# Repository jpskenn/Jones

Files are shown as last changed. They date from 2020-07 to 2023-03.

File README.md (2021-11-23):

# Jones（ジョーンズ）とは

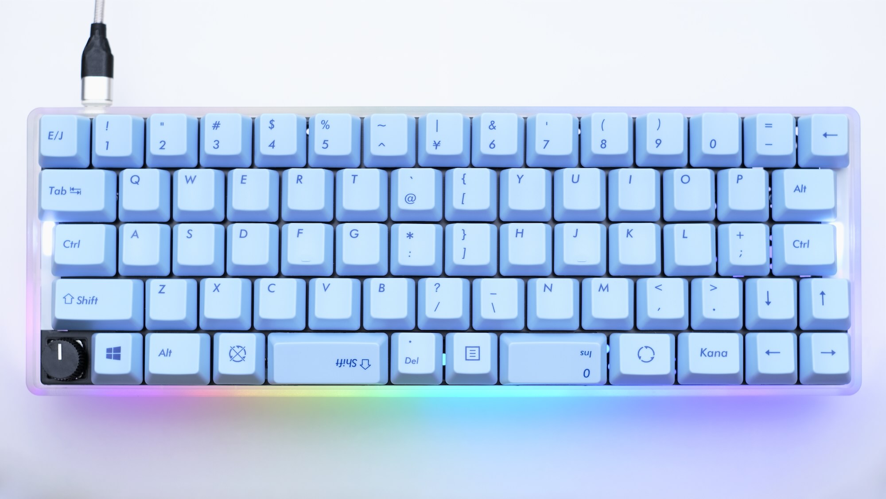
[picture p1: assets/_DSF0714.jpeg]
Jones


Jones（ジョーンズ）は、2行目と3行目にずれのない、シンメトリカルな60%キーボードです。  
左右対象のアルファ部と、右手側Modキーをホームポジションのすぐ隣へ配置したレイアウトが特徴で、自然なポジションで打鍵できます。  

40%や50%キーボードのコンパクトで軽快な運指の心地良さと、レイヤーに数字や記号を押し込まなくてよい十分なキー数を兼ね備えています。

GH60型やPoker型に互換性のあるケースや、専用のボトムプレートと組み合わせて使用できます。

[遊舎工房](https://shop.yushakobo.jp/products/2798)と[BOOTH](https://booth.pm/ja/items/3266269)で購入できます。  
また、その気になればご自分で製造することも可能です。

名前の由来は、ロースタガとオルソリニアをつなぐ”橋”という意味を込めて…

``` text
橋（ブリッジ） → ブリッジド → ブリジット → ブリジット・ジョーンズ → ジョーンズ

Bridge --> Bridged --> Bridget --> Bridget Jones --> Jones
```

という具合の言葉遊びで、ジョーンズ（Jones）に決まりました。

---

Jones is a symmetrical 60% keyboard, combined with Ortho-linear and Row-staggered. It has gap-less R2-R3 row.  
Symmetrical alpha-keys and nearby right side mod-keys provide natural typing position.  

It has compact and light fingering which like 40% and 50% keyboards.
And also, it has enough keys, no need to push numeric and symbol keys into layers.

It can be used with GH60 and Poker compatible cases.

Available at [Yushakobo](https://shop.yushakobo.jp/products/2798) and [BOOTH](https://booth.pm/ja/items/3266269).  
Or, manufacture by your self.

---

## 目次
<!-- @import "[TOC]" {cmd="toc" depthFrom=2 depthTo=4 orderedList=false} -->

<!-- code_chunk_output -->

- [目次](#目次)
- [対象とするユーザー](#対象とするユーザー)
- [コンセプト](#コンセプト)
- [特徴](#特徴)
  - [独自のずれ幅をもつ左右対象のアルファ部](#独自のずれ幅をもつ左右対象のアルファ部)
  - [右手のホームポジションに近づけたModキー](#右手のホームポジションに近づけたmodキー)
  - [キーレイアウトのバリエーション](#キーレイアウトのバリエーション)
- [機能](#機能)
  - [RemapやVIAなどのキーマップ書き換えツールに対応](#remapやviaなどのキーマップ書き換えツールに対応)
  - [より多くのレイヤーを使用可能](#より多くのレイヤーを使用可能)
  - [ケース](#ケース)
  - [レイヤーインジケータLED（オプション）](#レイヤーインジケータledオプション)
  - [アンダーグロー用LEDテープ（オプション）](#アンダーグロー用ledテープオプション)
  - [ロータリーエンコーダ（オプション）](#ロータリーエンコーダオプション)
  - [スピーカー（オプション）](#スピーカーオプション)
- [技術](#技術)
  - [総当たりマトリクス](#総当たりマトリクス)
- [ビルドガイド](#ビルドガイド)
- [ビルド例](#ビルド例)
- [関連リソース](#関連リソース)
  - [キーボードレイアウト定義ファイル](#キーボードレイアウト定義ファイル)
- [私の使用環境](#私の使用環境)
- [試作歴](#試作歴)
- [ロゴ](#ロゴ)

<!-- /code_chunk_output -->

## 対象とするユーザー

Jonesキーボードは、  
*一般的なキーボードのキー配列に不満があり、より良いタイピングポジションを求めている方*  
を対象に作られています。

特に、次のような方におすすめします。

- より良いタイピングポジションを求めている方  
  左右対称のレイアウトと右手側Modキーの配置変更によって、より良いポジションで打鍵することができます。  
  Z~Bを左へずらした完全に左右対称なレイアウトにすれば、さらにポジションを改善できます。

- 機能的なキー配列を求めている方  
  あまり使わないキーをホームポジションから外し、よく使うキーを使いやすい位置に配置しています。  
  分割したスペースキーや親指付近のキーにEnterやBackspaceを割り当てて、これまでとは違う使い方も楽しめます。

- レイアウトを変えるのが不安な方や、指使いを変えたくない方  
  左右対称のレイアウトに戸惑うかもしれませんが、一般的なキーボードの違いはごくわずかです。  
  3行目から下が左へ1/4キー（0.25u）ずれただけなので、ほぼ同じレイアウトで使用できます。  
  指使いを覚え直す必要がなく、これまでどおりの指使いのまま打鍵することができます。

- キーの数を減らしたくない方  
  数字行，記号，カーソルなど、よく使うキーは盤面上に配置されています。  
  テンキーやファンクションキーは、レイヤーを切り替えたり、他のキーと組み合わせたりして使用できます。

参考までに、*冗談半分で*以下のチャートにまとめました。

<!--　チャート更新 -->
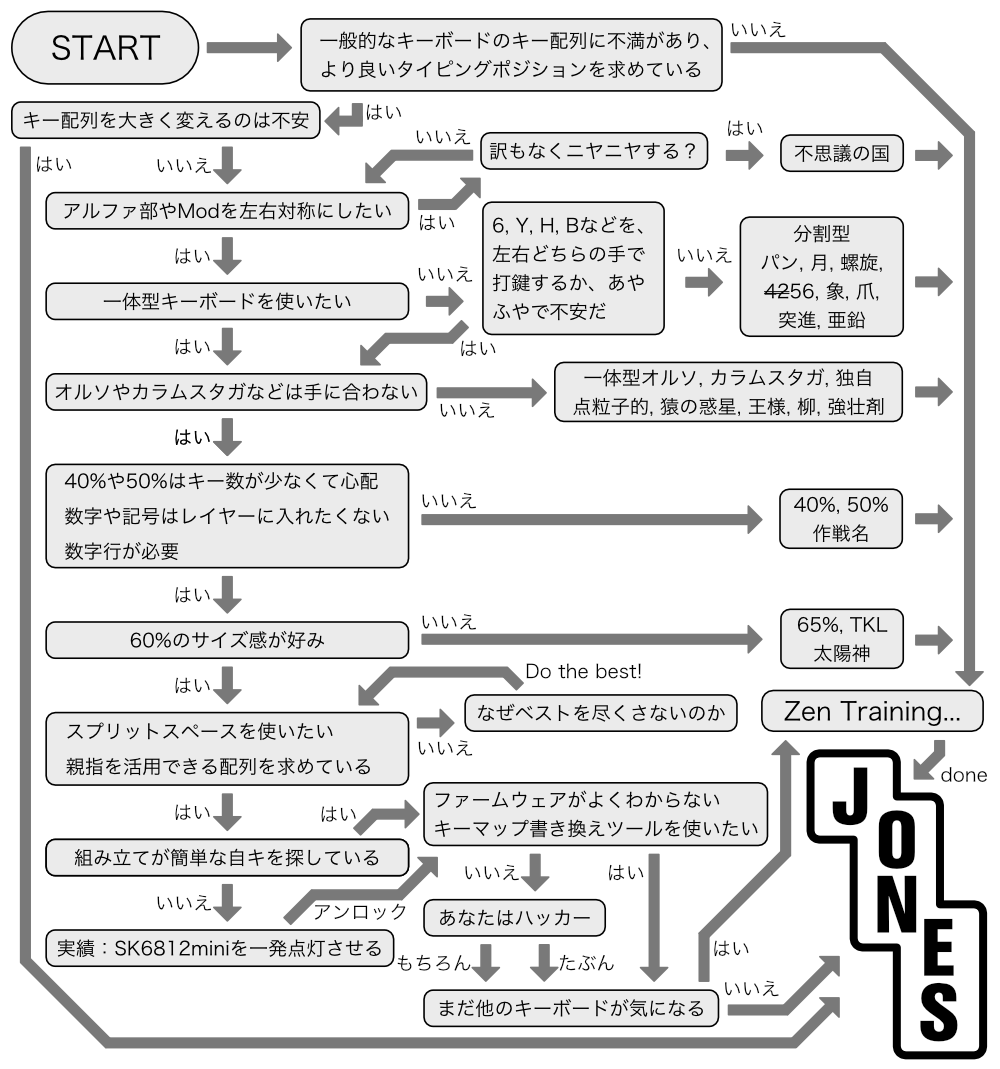
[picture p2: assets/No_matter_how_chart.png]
どうやってもJonesになるチャート


## コンセプト

このキーボードのコンセプトや実現したい要件は次の通りです。

- 基本的には、一般的なキーボードのロースタガレイアウトでそこそこ満足という気持ち。
- 左手の肘、手首、指先を直線状に並べて、ポジションを改善したい。  
  一般的なロースタガでは左手首の角度がおかしい。
- 右手のModが遠いと打鍵がつらくなるのを改善する。
- アルファ部が左右対称じゃないと話にならない。
- サイズは60%。  
  レイヤーに数字や記号を押し込まなくてもよいキー数と、筐体サイズのコンパクトさのバランス。
- GH60型のケースに対応させ、ケース設計をメイン作業に含めない。
  キーレイアウトを提案したい。
- HHKB的な何かを目指しつつ、スプリットスペースが使いたい。
- たまに一般的なキーボードを使うときにも、戸惑うことなく使えるようなレイアウトにとどめておく。
- 標準的なキーキャプですべて埋められるレイアウトを用意する。

## 特徴

### 独自のずれ幅をもつ左右対象のアルファ部

2行目と3行目にずれの無い、シンメトリカルなキー配列です。  
ロースタッガードとオルソリニアを組み合わせたような配列になっており、分類上は、シンメトリカル、左右対称ロースタッガードや変則ロースタッガードと呼んでも良いかもしれません。  

左手と右手が同じずれ幅となる左右対象のアルファ部により、肘、手首、指先が直線上に並んだ自然なポジションにします。  

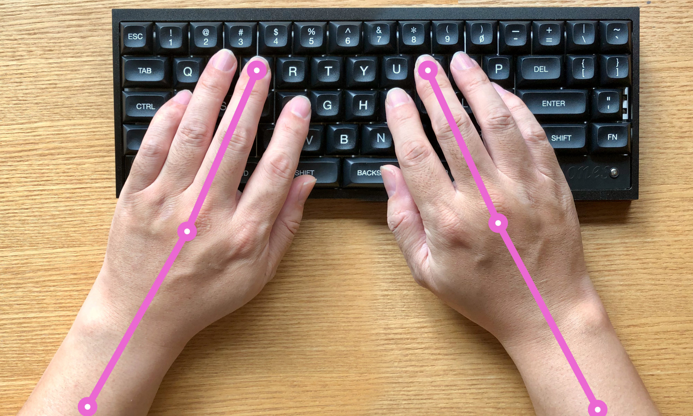
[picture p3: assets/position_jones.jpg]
Position:Jones
  
Jones, Wideレイアウト: 左手、右手ともに、肘、手首、指先が直線上に並ぶ

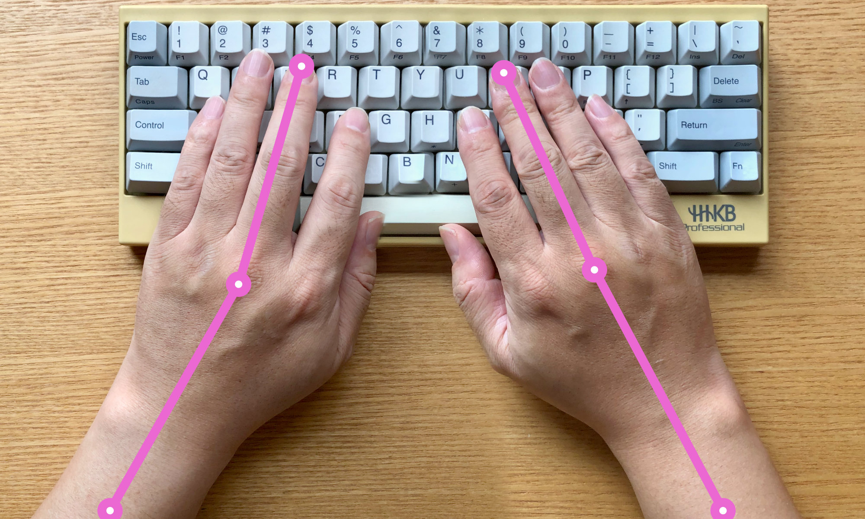
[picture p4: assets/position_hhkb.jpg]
Position:HHKB
  
一般的なレイアウト: 左手の手首から先、指先が外側へ向く

### 右手のホームポジションに近づけたModキー

40%や50%キーボードのコンパクトなレイアウトにならい、Modキーを右手のホームポジションのすぐ隣に配置しました。  
打鍵しやすい位置に使用頻度の高いキーを配置したことで、右手の負担を軽減できます。  

使用頻度の低い記号キーは、Wideレイアウトではキーボードの中央へ、Narrowレイアウトでは右端へ移動しています。

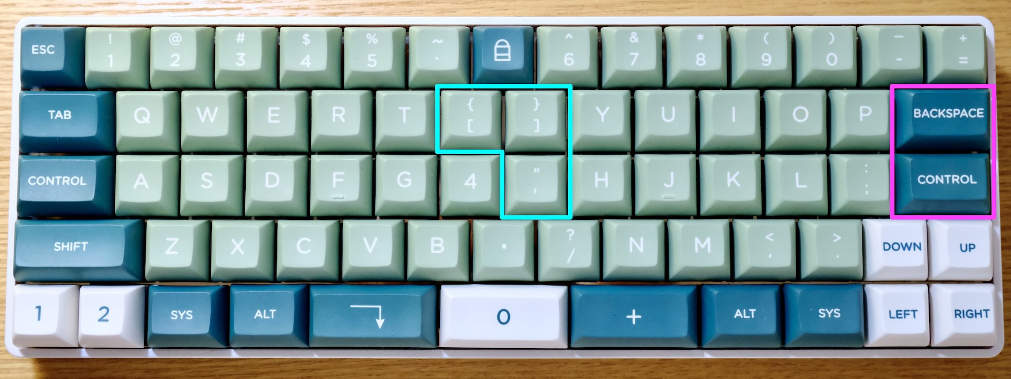
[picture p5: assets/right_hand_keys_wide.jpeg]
Mod keys at right side
  
右手のホームポジションすぐ隣のModキーと、移動した記号キー（Wideレイアウト，英語配列）

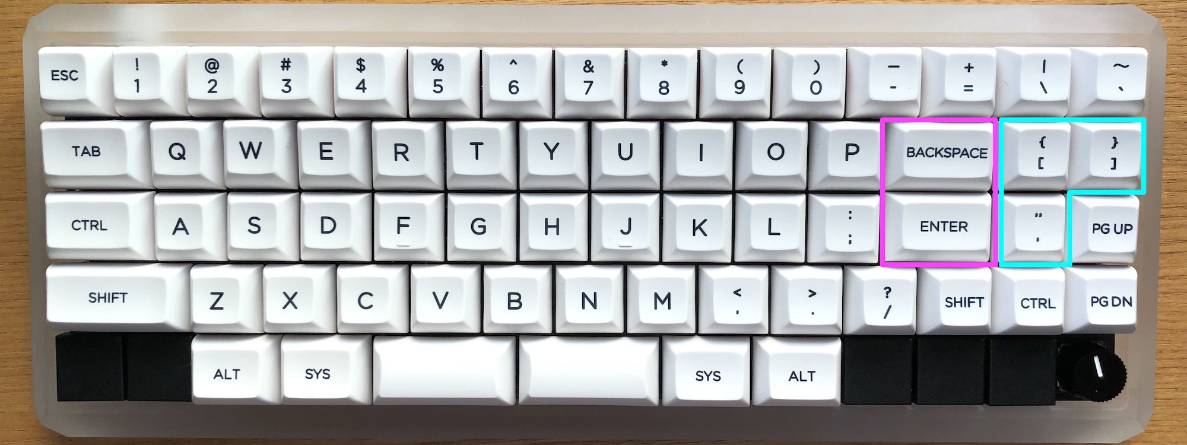
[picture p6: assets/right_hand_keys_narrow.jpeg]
Mod keys at right side
  
右手のホームポジションすぐ隣のModキーと、移動した記号キー（Narrowレイアウト，英語配列）

### キーレイアウトのバリエーション

キーレイアウトは、Wide（ワイド），Narrow（ナロー），Normal（ノーマル）の、3つのバリエーションから選べます。  
最下行はスペースキーとModキーの組み合わせが選択でき、左右の端にはロータリーエンコーダを配置することもできます。

いずれのレイアウトも、一般的な日本語108キーや英語104キーのキーキャップセットで組み立てることができます。  
Narrowレイアウトを隙間なく構成する場合は、カスタムキーキャップを使用します。

すべてのレイアウトは、[Keyboard Layout Editor: Jones v.1(042)](http://www.keyboard-layout-editor.com/#/gists/53fab8cd4a4480980921f37c39e1f5f3)をご覧ください。

- Wide（ワイド）レイアウト  
  右手ホームポジションを右側へずらしてModキーに近づけ、キーボード中央に2キー分の間隔をもたせたレイアウトです。  
  キーボード全体を左右対称にすることができます。  
  左手と右手のホームポジションが離れるため、肩への負担を軽減できます。

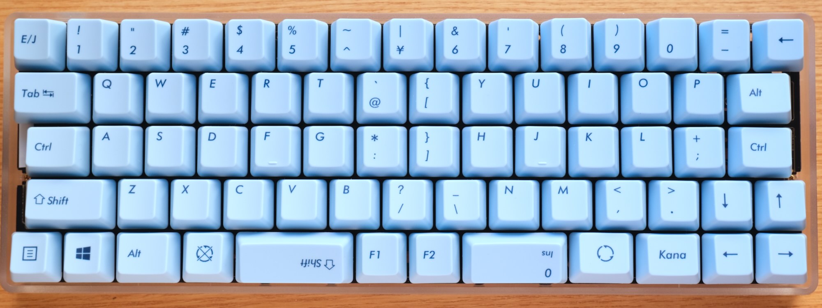
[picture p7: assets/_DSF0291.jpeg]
Jones, Wideレイアウト
    
  例：Wideレイアウト，日本語108キーを使用した、日本語配列の構成

- Narrow（ナロー）レイアウト  
  右側Modキーをキーボード中央側へずらし、ホームポジションに近づけたレイアウトです。  
  40%キーボードに、上へ1行、右に2列増やしたようなレイアウトになっています。  
  アルファ部とModを左右対称にしつつ、右端2列の非シンメトリカルな存在を楽しむことができます。  
  カスタムキーキャップを使って構成します。  

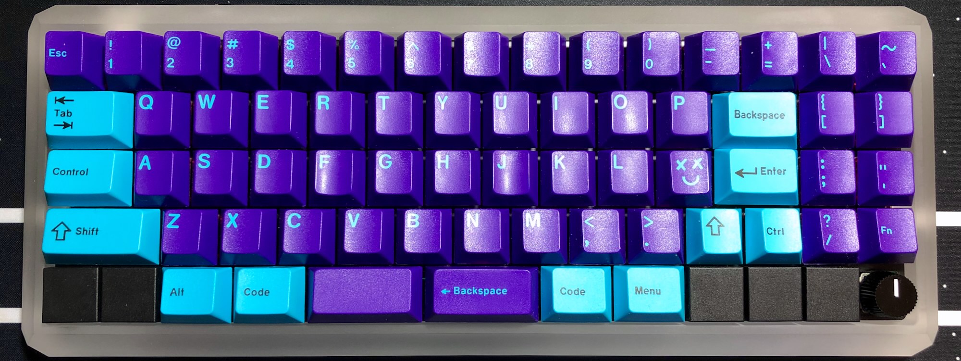
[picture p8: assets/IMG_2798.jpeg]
Jones, Narrowレイアウト
    
  例：Narrowレイアウト，カスタムキーキャップを使用した、英語配列の構成

- Normal（ノーマル）レイアウト  
  一般的な英語配列や日本語配列とほぼ同じになるように調整したレイアウトです。  
  WideやNarrowレイアウトへの移行（習得）に不安のある方や、一般的なキーボードに近いレイアウトでアルファ部を左右対称にしたい方におすすめです。  

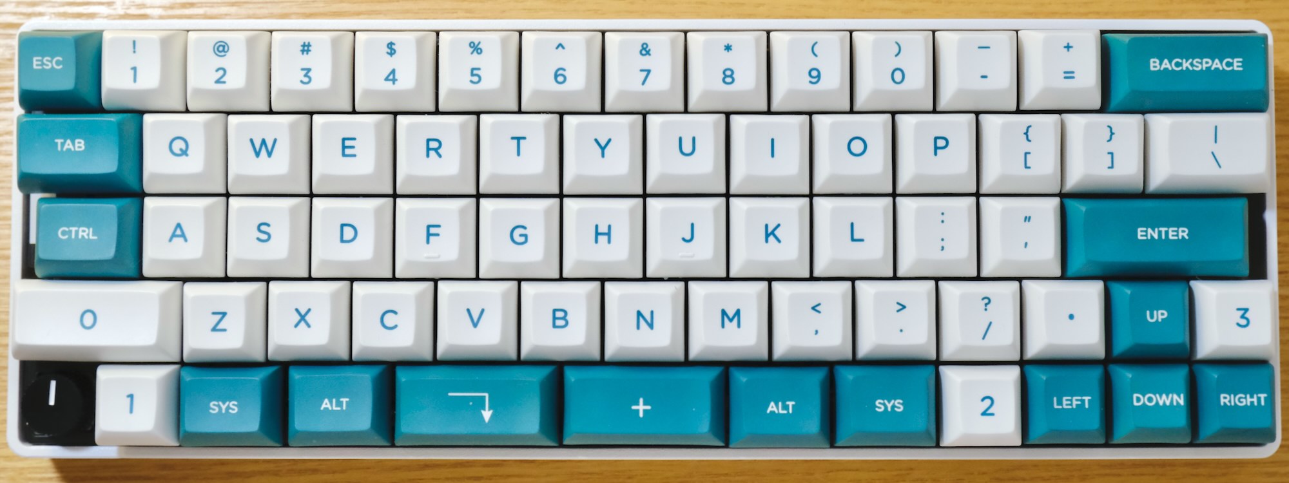
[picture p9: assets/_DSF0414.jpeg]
Jones, Normalレイアウト
    
  例：Normalレイアウト，英語104キーキャップを使用した、英語配列の構成

## 機能

### RemapやVIAなどのキーマップ書き換えツールに対応

[Remap](https://remap-keys.app)や[VIA](https://caniusevia.com)などのキーマップ書き換えツールに対応しており、ファームウェアを書き換えることなく、キーとロータリーエンコーダの割り当てを変更することができます。  

Remapにはキーボード定義を登録済みですので、サイトへアクセスしてキーボードを接続すれば、すぐにキーの割り当てを変更することができます。  
VIAを使用する場合は、以下のキーボード定義ファイルを読み込ませてください。  
キーボード定義ファイル：[jones_v1(042).json](https://gist.github.com/jpskenn/b0e62ff02264ebc955b5153c9b64200d)

### より多くのレイヤーを使用可能

外部EEPROMの搭載により、RemapやVIAでより多くのレイヤーを使用することができます。

出荷時に書き込まれている初期ファームウェアでは、6レイヤーまで使用可能です。  
使わない機能を無効化したファームウェアを用意すれば、さらに多くのレイヤーを使用できます。  
（例：スピーカーの機能を無効化すると、10を超えるレイヤーを使用可能）

### ケース

GH60型やPoker型に互換性のあるケースに対応しています。  

また、”Jones用ボトムプレートキット”を使用すれば、ケースレスのサンドイッチマウントとして使用できます。  
ケースを使用する場合に比べてキーボードの高さを低く抑えることができるので、手首の負担軽減などに有効です。  

### レイヤーインジケータLED（オプション）

レイヤーの状態を表示するインジケータLEDを、右側または左側に2個、もしくは左右両方に4個設置できます。

### アンダーグロー用LEDテープ（オプション）

ケース下面を照らす、アンダーグロー用LEDテープを取り付けできます。

### ロータリーエンコーダ（オプション）

ロータリーエンコーダを、最下行の左端または右端に1個、もしくは左右両端に2個設置することができます。  
OSのボリューム操作やマウスホイールの上下などの機能を割り当てて使用できます。  

### スピーカー（オプション）

キーボードの起動音やキー入力のクリック音を再生できるスピーカーを設置できます。  
音楽用キーボードのように、メロディの演奏も楽しめます。

## 技術

### 総当たりマトリクス

キースイッチとマイコンを接続するキーマトリクスに`総当たりマトリクス`と呼ばれる方式を採用し、10個のGPIOピンを使用して、70個(\*)のキースイッチを接続しています。  
\* ロータリーエンコーダの回転をキー操作として割り当てるため、ソフトウェア的には74キーを接続しています。

総当たりマトリクスについての詳しい説明は、[総当たりマトリクス / Round Robin Matrix](https://github.com/jpskenn/SMK-Supplements/tree/master/RoundRobinMatrix)を参照してください。

## ビルドガイド

- [Jones v.1 ビルドガイド](./docs/BuildGuide_v.1_JA.md)

<details>
<summary>以前のビルドガイド</summary>

- [v.0.4.1](./docs/BuildGuide_v.0.4.1_JA.md)
- [v.0.3.1 / v.0.3.2](./docs/BuildGuide_v.0.3.1_JA.md)
- [v.0.3](./docs/BuildGuide_v.0.3_JA.md)
- [v.0.2](./docs/BuildGuide_v.0.2_JA.md)
- [v.0.1](./docs/BuildGuide_v.0.1_JA.md)

</details>

## ビルド例

<!--
〓
NormalのUS, JP → レイアウトのところに載せている
ZincやKatana風の、Zが外にくる完全シンメトリカルなもの。
m.teiさんのアレ。
-->

| ビルド例 | 詳細 |
| --- | :-- |
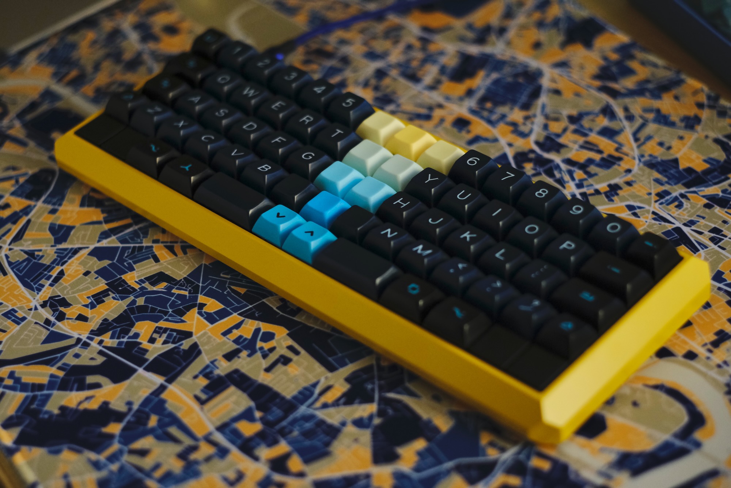
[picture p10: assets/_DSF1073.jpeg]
| [](./assets/_DSF1073.jpeg) | Wideレイアウト 英語配列, カスタムキーキャップ<br>case: 5° Five Degreee 60% Aluminum, E-Yellow<br>keycaps: DSS Solarlized, DSA Blank Keys, SP Blocker |
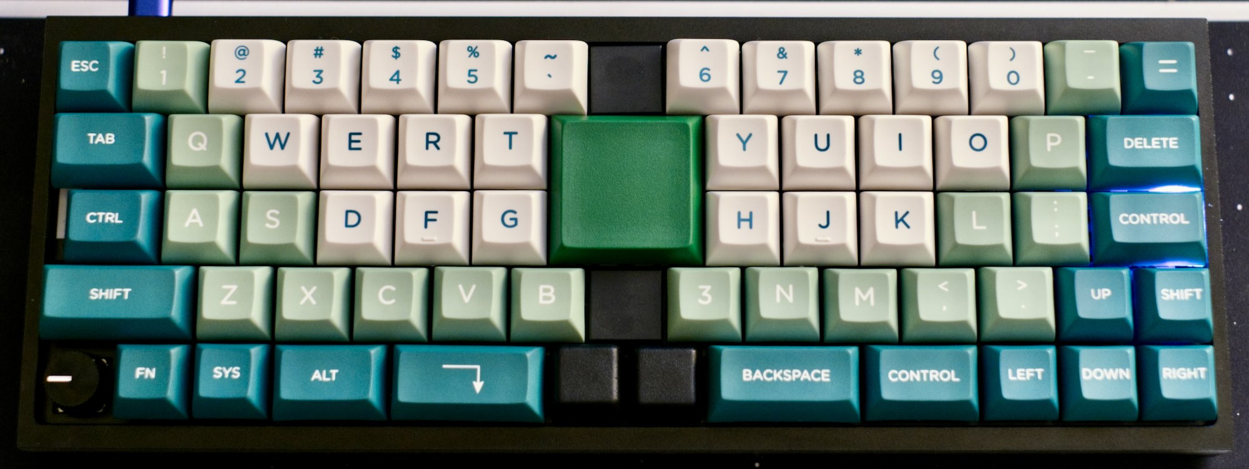
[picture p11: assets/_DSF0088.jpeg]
| [](./assets/_DSF0088.jpeg) | Wideレイアウト 英語配列, カスタムキーキャップ<br>case: TOFU Aluminum, Black<br>keycaps: KAT Lucky Jade, SP DSA 2x2 (Block) Key, SP G20, SP Blocker<br>rotary encoder: EC12E24204A2, knob: K-2605 |
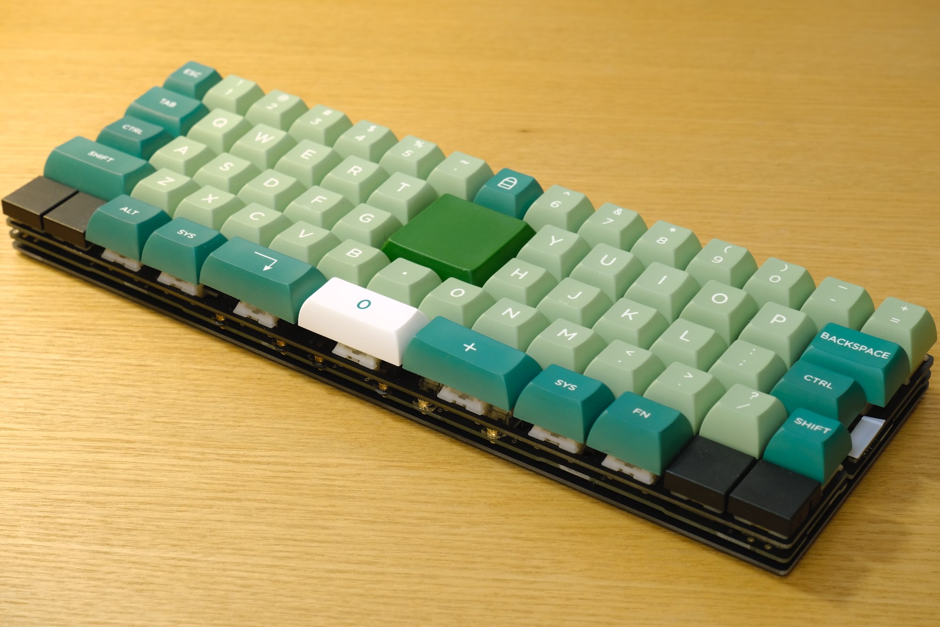
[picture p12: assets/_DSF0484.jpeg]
| [](./assets/_DSF0484.jpeg) | Wideレイアウト 英語配列, カスタムキーキャップ<br>case: Jones用ボトムプレート<br>keycaps: KAT Lucky Jade, SP DSA 2x2 (Block) Key, SP Blocker |
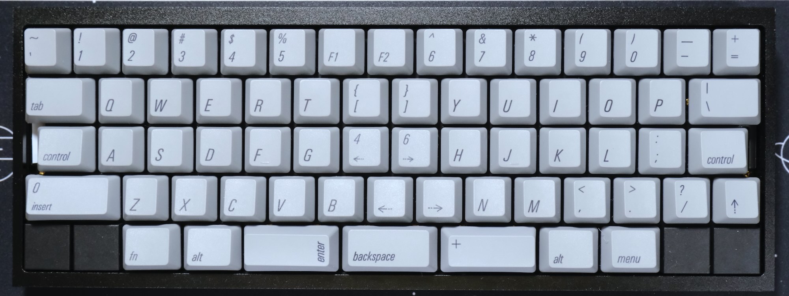
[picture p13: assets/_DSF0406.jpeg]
| [](./assets/_DSF0406.jpeg)| Wideレイアウト 英語配列, 英語104キーキャップ<br>case: TOFU Aluminum, Black<br>keycaps: Qisan PBT Keycaps 108, SP Blocker |
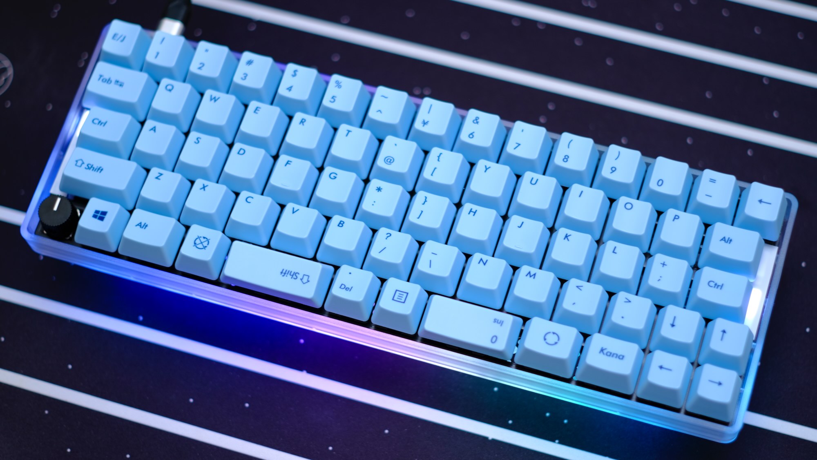
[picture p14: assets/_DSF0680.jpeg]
| [](./assets/_DSF0680.jpeg) | Wideレイアウト 日本語配列, 日本語108キーキャップ<br>case: 60％ Plastic, Clear<br>keycaps: Majestouch 日本語108キー・かななし・ミルキーブルー<br>rotary encoder: EC12E24204A2, knob: K-2605 |
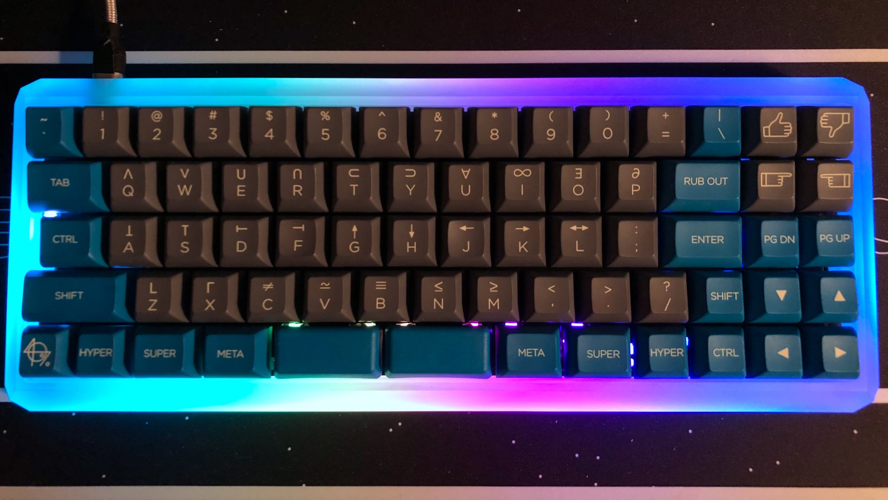
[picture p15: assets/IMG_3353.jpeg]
| [](./assets/IMG_3353.jpeg) | Narrowレイアウト 英語配列, カスタムキーキャップ<br>case: 5° Frosted Acrylic CNC 60%<br>keycaps: KAT Space Cadet, SP G20<br>アンダーグローLED |
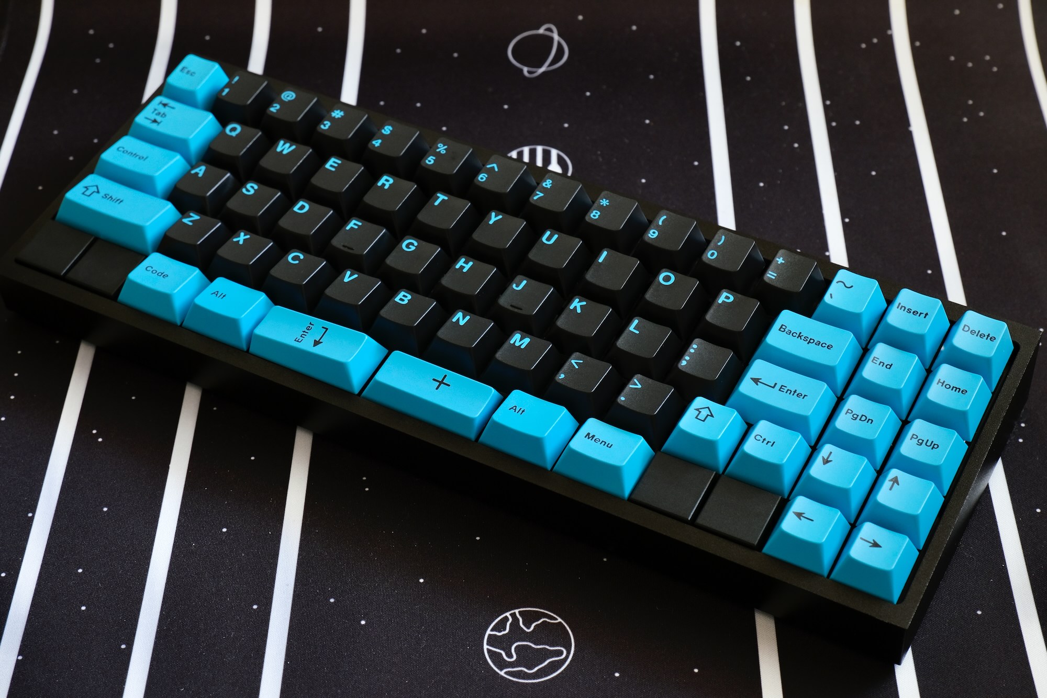
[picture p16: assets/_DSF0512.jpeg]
| [](./assets/_DSF0512.jpeg) | Narrowレイアウト 英語配列, カスタムキーキャップ<br>case: TOFU Aluminum, Black<br>keycaps: GMK Pulse, SP Blocker |
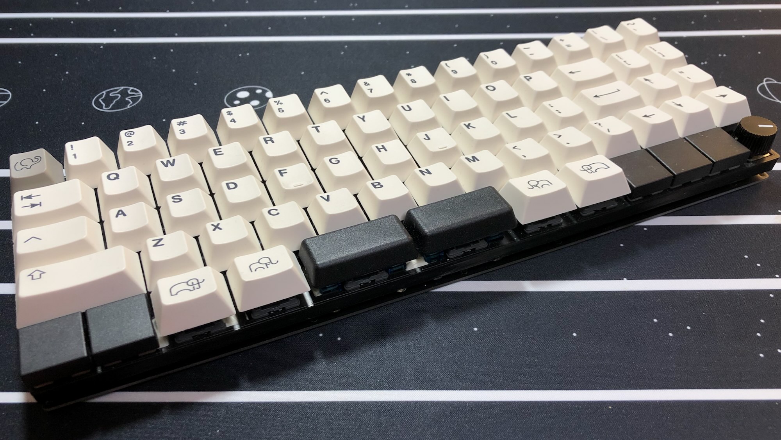
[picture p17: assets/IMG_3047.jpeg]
| [](./assets/IMG_3047.jpeg) | Narrowレイアウト 英語配列, カスタムキーキャップ<br>case: Jones用ボトムプレート<br>keycaps: ePBT Ivory, SP G20, SP Blocker<br>rotary encoder: EC12E24204A2, knob: K-2605 |

Twitterのハッシュタグ[#Jones_kbd](https://twitter.com/search?q=(%23jones_kbd)&src=typed_query&f=live)にも、作例が集まっています。

## 関連リソース

### キーボードレイアウト定義ファイル

[Remap](https://remap-keys.app)や[VIA](https://caniusevia.com)で使用できる、キーボードレイアウト定義ファイルです。  
このリポジトリの[VIAフォルダ](https://github.com/jpskenn/Jones/tree/master/VIA)に配置しています。

RemapのWebサイトには登録済みなので、このファイルは不要です。  
Webサイトを開いてキーボードを接続すれば、自動的にレイアウトが表示されます。

定義ファイルが登録されていないVIAを使用する場合や、Remapをローカル環境で動作させる場合に使用します。

Jones v.1用 キーボードレイアウト定義ファイル：[jones_v1(042).json](https://gist.github.com/jpskenn/b0e62ff02264ebc955b5153c9b64200d)

## 私の使用環境

私がどのような環境でJonesキーボードを使っているのかをお伝えすることで、このキーボードがどういう用途で適していて、何が良いところなのかを知っていただければと思います。

<details>
<summary>私の使用環境</summary>

### Jonesキーボードの使用歴

2020年7月からJonesキーボードを使い始めました。  
それ以来、自宅と会社のメインキーボードとして、1年以上（2021年9月現在）使い続けています。

試作を重ねる中でModキーの配置はちょくちょく変更していますが、Jonesの特徴である2行目と3行目にずれのない左右対称のレイアウトは、最初の試作から変わっていません。

振り返ってみて思うことですが、もしこのレイアウトが使いにくいものだったとしたら、1年以上も使い続けてこられたでしょうか？  
以前はRealforce R2（静音30g）の打鍵感にベタ惚れして使っていたのですが、Jonesを使い始めてからは、押し入れで眠ったままになっています。  
打鍵感、特にキースイッチに起因する指先の感覚において、JonesでRealforceほどの快適さを得ることはほぼ不可能ですが、それでもRealforceには出番がまわってきません。

この状況から考えると、少なくとも、RealforceよりもJonesのほうが使いやすいと感じる何かがあると言えるでしょう。

### キーボードのセッティング

[Remapで共有しているキーマップ](https://remap-keys.app/catalog/z8HynboRCOQfPmwXbzp6/keymap?id=NXDzVJVuxeW8HdR5joy8)を見てもらえば、だいたいの感じは伝わるでしょうか？

- レイアウト  
  使い始めから1年近くはNarrowレイアウトで使っていました。（試作段階で、Wideレイアウトに対応していない時期があったため）  
  現在はWideレイアウトで使っており、肩への負担を少し減らし、最下行中央のキーに機能を割り当てて親指を活用しようとしています。  

- キーマップ  
  英語配列を基本としたキーマップです。  
  日本語入力時に長音（伸ばし棒）の`ー`を使用率頻度が高いため、`L`の右隣の`;`に、`-`を割り当てています。  

  ホームポジションから外れる`[`,`]`,`'`などの記号キーは、手の移動が面倒なので物理的な配置はおこなわず、レイヤー内に配置しました。  
  また、1行目の数字行を打鍵するための肘や手首の移動ロスがバカにならないため、レイヤー内の2行目に数字と記号を配置して、ホームポジションのまま打鍵することが多くなってきました。  
  少しずつ40%キーボードに近づいている感じですが、とっさのときには1行目の数字行を打鍵してしまっており、まだしばらくは50〜60％くらいのキーマップにお世話になりそうです。

- レイヤー  
  7個のレイヤーを使用しています。  
  工夫すればもう少し減らせそうなのですが、外部EEPROMの搭載で使えるレイヤー数に余裕があるので、工夫するのを先延ばししています。

  スペースキーの長押しにレイヤーキーを設定してあり、左スペースにLower、右スペースにRaise、左右同時でAdjustのレイヤーへ移動します。  

  | No. | レイヤー名 | 内容 |
  | :-: | :-- | :-- |
  | 0 | Mac | Mac用ベースレイヤー<br>スペースキーの隣にCMD |
  | 1 | Windows | Windows用ベースレイヤー<br>スペースキーの隣にALT |
  | 2 | Numeric | Numeric（テンキー）用ベースレイヤー<br>数値入力専用 |
  | 3 | Lower | ファンクションキー<br>2行目に記号を配置して40%キーボード風に |
  | 4 | Raise | カーソル移動，ファンクションキー<br>2行目に数字を配置して40%キーボード風に |
  | 5 | Numeric Lower | Numeric（テンキー）使用時に、ちょこっとだけ文字入力するためのレイヤー |
  | 6 | Adjust | デフォルトレイヤーの切り替え，LEDやオーディオの設定変更，<br>CAPS LockやPrint Screenなどの間違って押したくないキーを配置 |

- レイヤーインジケータLED  
  NumericレイヤーのON/OFFとCAPS Lockの状態を把握したいので、インジケータLEDをつけています。  
  左Ctrlを1.25uのサイズにして、インジケータLEDを見えやすくしています。

- アンダーグロー用LEDテープ  
  単に光るというだけで特に機能が増えるわけではないのですが、アンダーグローが光っているだけで、なぜだか気分が良くなります。

- ロータリーエンコーダ  
  うまく機能を割り当てれば有効活用できそうなので、左下に取り付けています。  
  ですが、今のところはボリューム操作しか割り当てていないので、無かったら無いで問題なさそうな気もしています。

### 自宅における私的使用

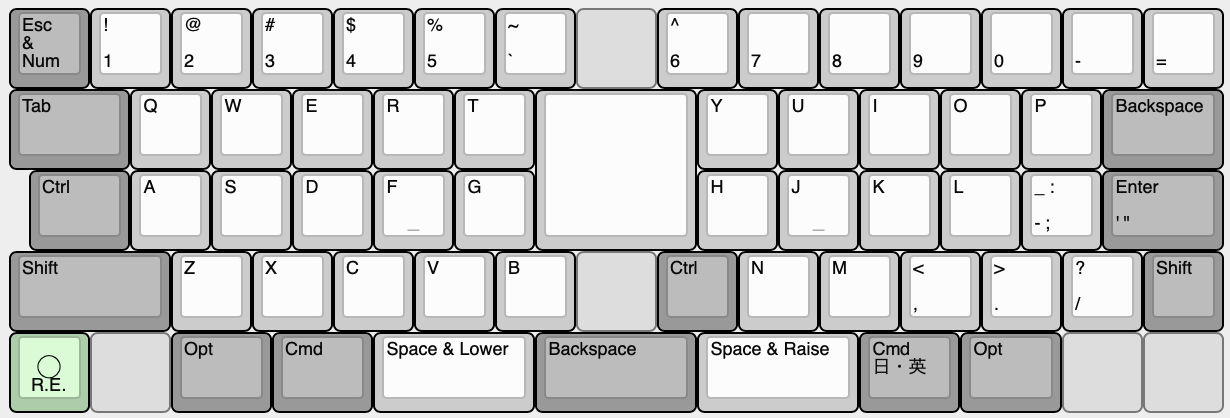
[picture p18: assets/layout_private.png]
for private
  

自宅ではMacを使用しており、主な用途は次のとおりです。

- キーボードファームウェアの作成。C言語など。（VS Code）
- 各種ドキュメント執筆。Markdown。（VS Code）
- 回路・基板の設計（KiCad）
- グラフィックソフトウェアを用いた、ケースやプレートの設計（Affinity Designerなど）
- 写真編集

Raiseレイヤーでカーソル移動ができれば十分なので、カーソルキーは省いています。

左手でマウスを使用するため、マウス主体のアプリケーションを使用する際に右手でModキーが操作できるよう、右手側に`Cmd`, `Opt`, `Shift`, `Ctrl`をそれぞれ単独で配置しています。

私は肘から少し先までを机に乗せて、手をあまり浮かせずに打鍵するタイプなので、小指の付け根付近が最下行のキーに当たりやすく、少し不快に感じます。  
そのため、最下行の左右端から2キーにはブロッカー（[Pimp my keyboard: Switch Blocker](https://pimpmykeyboard.com/switch-blocker-pack-of-10/)）を取り付けて、キーを配置していません。  
プログラムの動作や文章の表現を考えながらキーボードを使うときは、このちょっとした心地よさが大切な気がします。

ロータリーエンコーダも軸が短いタイプに背の低いノブを組み合わせることで、打鍵時に手に当たらないようにしています。

キーボード中央の2*2のキーは単なる飾りです :-)

### 会社における業務使用

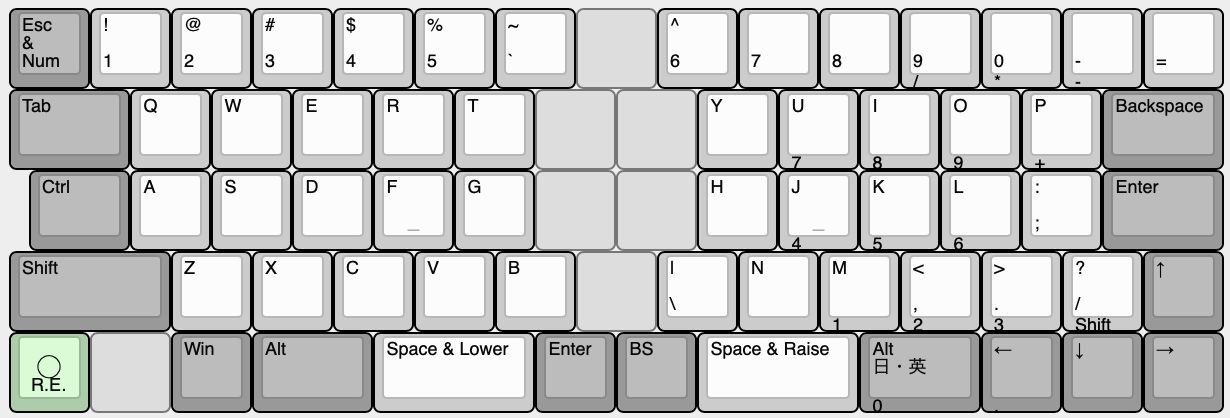
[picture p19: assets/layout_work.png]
for work
  

Windows XPのPCで、主な使用用途は次のとおりです。

- 何らかのデータの集計やリストの管理など（Excel）
- 作業効率化ツールの作成、保守（Excelマクロ VBA）
- 数値データの大量入力（独自ソフト）
- 掲示物の作成（Word, Excel）
- 共有PCでの作業

作業量の割合は、Excel関連が7割、数値データの入力が2割、共用PCでの作業が1割といった具合です。  

Windows PCのため、Windows向けのベースレイヤーに切り替えて使用しています。  
基本的には自宅で使用しているものと同じですが、独自ソフトでカーソルキーを使用する頻度が高いのと、右手にペンを持ったままカーソル操作を強いられることが多いため、カーソルキーを単独で配置している点が大きな違いです。  

数値データの大量入力は、Numericレイヤーに切り替えておこなっています。  
テンキー部分を右手のホームポジションに合わせて配置してあるので、右手の位置を変えずにBackspaceで削除したり、Lowerレイヤーでカーソル移動したりする操作をおこなうことができ、普通のテンキーに比べて作業効率が上がっています。

共用PCで作業することが日に何度かあり、そのときは一般的な日本語108キーボードを使用することになります。  
右手小指で打鍵するEnterがとても遠くに感じますが、Jonesのレイアウトが特殊すぎない範囲に収まっているので、指使いに戸惑うことなく打鍵できています。

余談ですが、緑色や水色などの色付きキーキャップを使用すると、キーボードについて声をかけられる率が上がります。  
特にピンク系で明るい色のキーキャップは、さらにたくさん声をかけられて、なんだか嬉しくなります。

</details>

## 試作歴

これまでの試作の記録は、[試作歴](./docs/Trials.md)にまとめています。

## ロゴ

Jones logo

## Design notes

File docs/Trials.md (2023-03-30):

# 試作歴

試作機の履歴をまとめています。

## v.1 (=v.0.4.2), 2021-08-25

- 遊舎工房にて委託販売開始。  
  BOOTHでもボトムプレートのセット品を販売。
- SMTA製造でMCUの在庫不足により、ATmega32u4-AUから-MUへ変更。
- ロゴ更新
- シルク調整, 修正
- アンダーグローLEDテープ対応
- Narrowレイアウトで一般的なキーキャップに対応（これにより、すべてのレイアウトで対応）
- Audio用のGPIOピンのメインとサブを入れ替え
- その他

## v.0.4.1, 2021-07

- 試作最終型の予定
- レイアウト調整。最下行から使わないバリエーションを削除。
- 基板とボトムプレートとの接続を調整。
- 外部EEPROMの部品サイズを変更。
- ロゴ追加

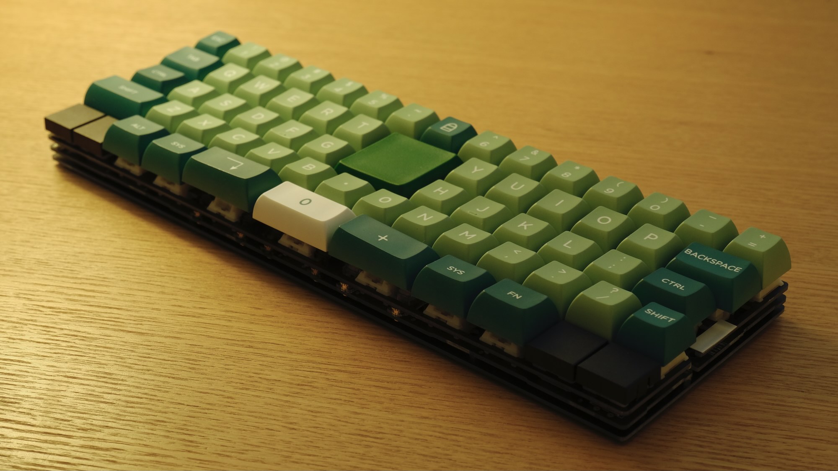
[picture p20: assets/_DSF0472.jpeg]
Jones v.0.4.1
  
v.0.4.1
Keycap: KAT Lucky Jade, SP DSA 2*2, PIMP MY KEYBOARD Switch Blocker
Case: Bottom plate kit for Jones

## v.0.4, 2021-06

- 世界的な半導体不足により、MCUをATmega32u4-MUから-AUに変更。
- v.0.2のWideレイアウトを復活させて再編成。
- ケースレス使用できるボトムプレートを試作。
- 総当たりマトリクスを10pinに変更し、外部EEPROMなしでもRemapで4レイヤーまで対応。
- I2C接続の外部EEPROMに対応。
- キープレートと基板を接続する試作→失敗

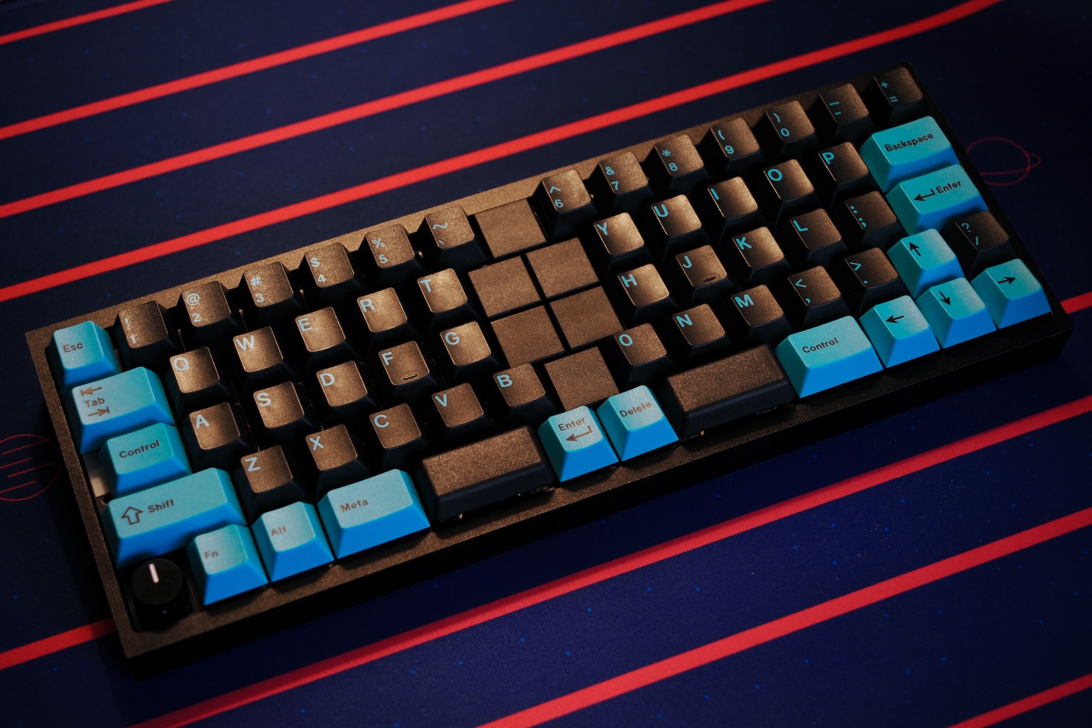
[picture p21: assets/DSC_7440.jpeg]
Jones v.0.4
  
v.0.4  
Keycap: GMK Pulse, PIMP MY KEYBOARD Switch Blocker
Case: KBDfans TOFU 60% Aluminum, Black

## v.0.3.2, 2021-04

- 組み立てやすさを向上。
- ネジ穴経由で導通する不具合対策
- キープレートの切り欠き部分を減らして剛性アップ

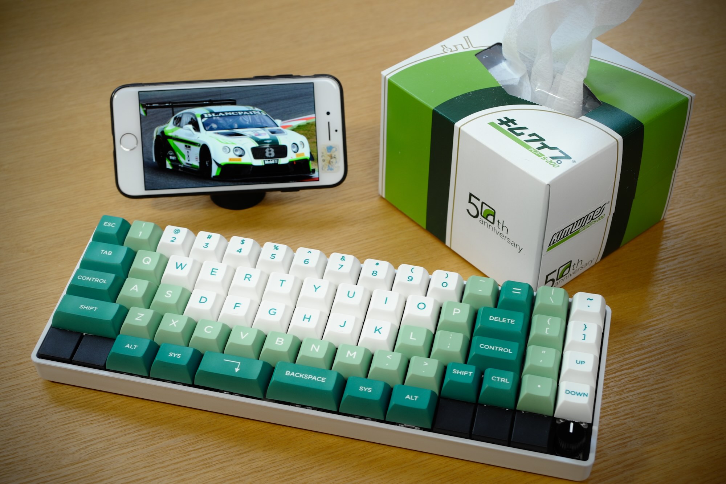
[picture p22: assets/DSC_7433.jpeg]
Jones v.0.3.2
  
Jones v.0.3.2  
Keycap: KAT Lucky Jade, PIMP MY KEYBOARD Switch Blocker
Case: 60% Plastic Case, White

## v.0.3.1, 2020-11

- v.0.3の課題や不具合解消。
- オーディオの2音同時発音に対応。
- テープLEDのみ光らせるパターンを追加。

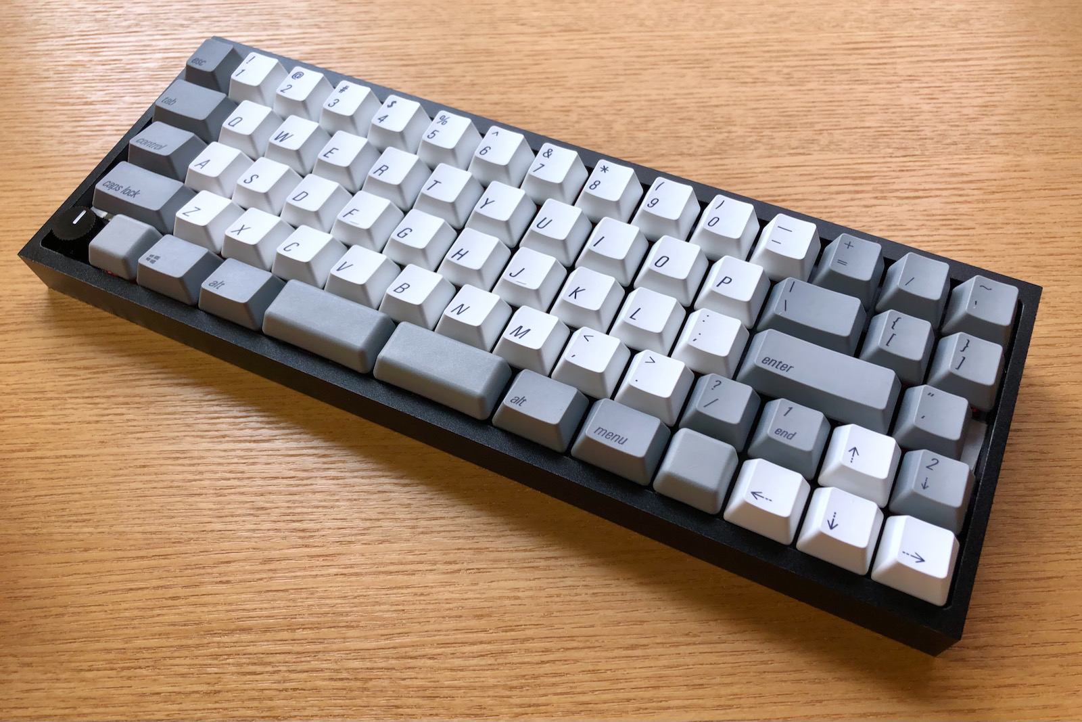
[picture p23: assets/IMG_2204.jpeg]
Jones v.0.3.1
  
v.0.3.1  
Keycap: Qisan / Magicforce PBT 108 keycaps
Case: KBDfans TOFU 60% Aluminum, Black

## v.0.3, 2020-10

- [レイアウト変更](http://www.keyboard-layout-editor.com/#/gists/ab35444150ef1aff63ed32bbe2b9a1ef)  
2U-Wide、Traditionalレイアウトを削除。  
もしかして日本語配列で使いたい人もいたりするの？との思いから、JPスタイルを追加。
- v.0.2の課題や不具合解消。
- キーマトリクスを”総当たりマトリクス”に変更し、MCUのピン使用数を大幅削減（19 → 11）。  
余ったピンを、2個目のロータリーエンコーダ、スピーカー、外部接続、OLED、I2Cなどの機能で使用。
- 左側LED、裏側LEDテープ追加。
- USB Type-C。
- ブロッカー、銘板パーツ廃止。  
[PIMP MY KEYBOARDのSwitch Blocker](https://pimpmykeyboard.com/switch-blocker-pack-of-10/)がブロッカーとして良い出来だったので、今後はこれを使う。

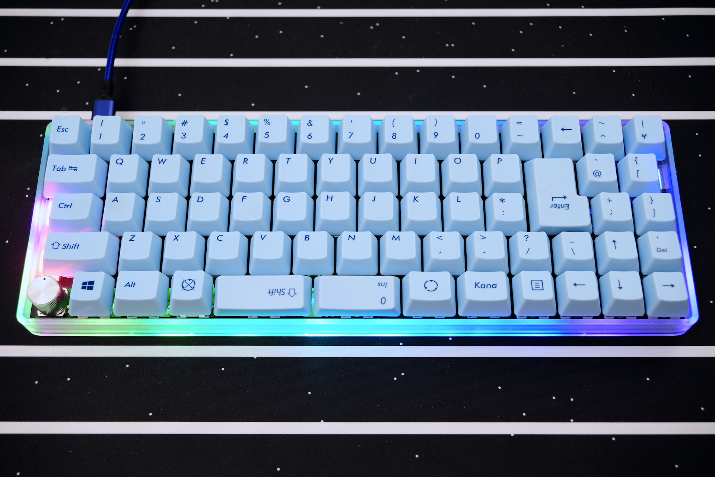
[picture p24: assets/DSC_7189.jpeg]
Jones v.0.3
  
Jones v.0.3  
Keycap: FILCO Majestouch 交換用カラーキーキャップセット 日本語108キー・かななし・ミルキーブルー  
Case: 60% Plastic Case, Clear

## v.0.2, 2020-08

- レイアウトの試行錯誤を続け、[2U-Wideレイアウト](http://www.keyboard-layout-editor.com/#/gists/3f5424e6560f5de6fa7c19e22f219831)を追加。  
2U-Wideのホームポジションは肩への負担も減るので気にいっていたが、このレイアウトを覚えると普通のキーボードをまともに打鍵できなくなったため、使用を封印。
- v.0.1の課題や不具合解消
- SMT Assemblyによる製造。  
SMTAに対応するため、部品サイズを変更。

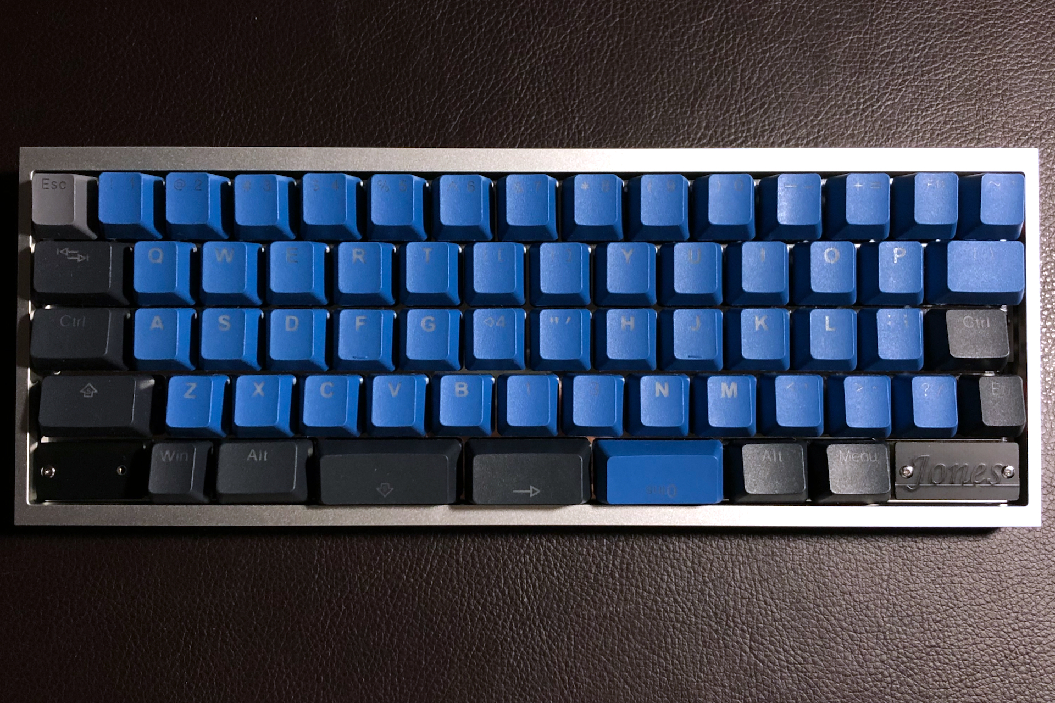
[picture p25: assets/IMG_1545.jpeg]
Jones v.0.2
  
Jones v.0.2  
Keycap: Tai-Hao PBT Backlit The Deep Forest Blue 132 Keys SKU#C22BF301  
Case: KBDfans TOFU 60% Aluminum, Silver

## v.0.1, 2020-07-10

- v.0のレイアウトを元に、[基板に乗せられるレイアウト](http://www.keyboard-layout-editor.com/#/gists/325aaaab8bd5e87bff89b81d67181bea)に調整。  
- ai03氏の[PCB Designer Guide](https://wiki.ai03.com/books/pcb-design/chapter/pcb-designer-guide)を参考に、基板を設計。  
- MCUを乗せた基板の組み立て、動作に成功。

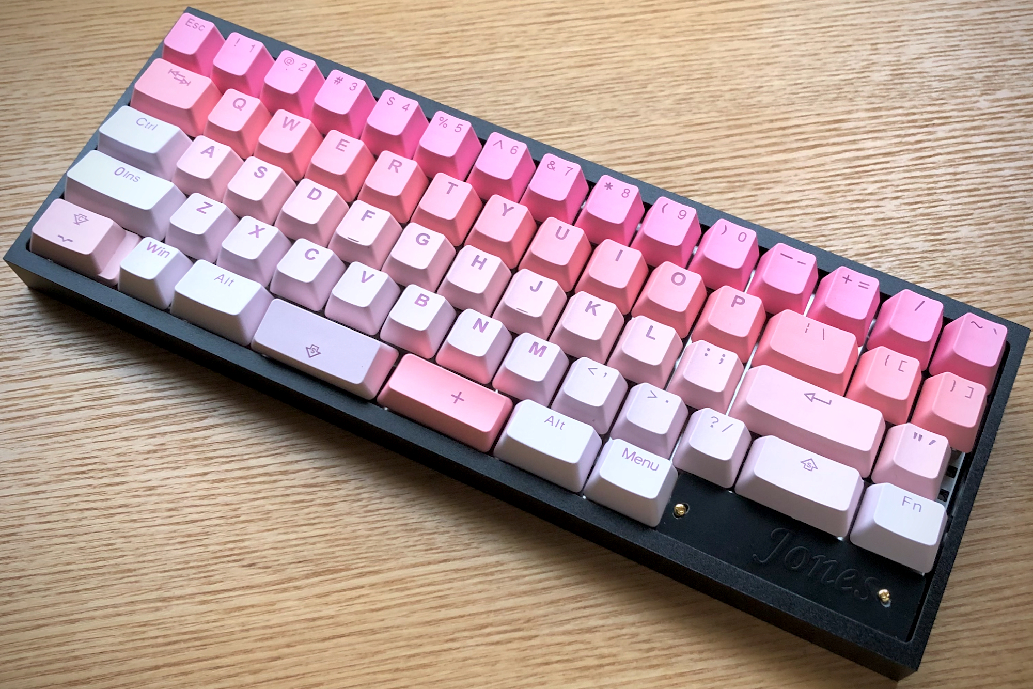
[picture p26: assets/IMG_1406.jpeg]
Jones v.0.1
  
Jones v.0.1  
Keycap: Tai-Hao Sakura Michi PBT  
Case: KBDfans TOFU 60% Aluminum, Black

## v.0, 2020-06-17

試行錯誤の末、2行目と3行目にずれが無いレイアウトが決定。  

KLEで作成したレイアウトを印刷して段ボールに貼り、両面テープでキーキャップを貼り付けたモックアップを作成。  
これをデスクに置いてエアータイプしまくって、違和感なく打鍵できることを確認。

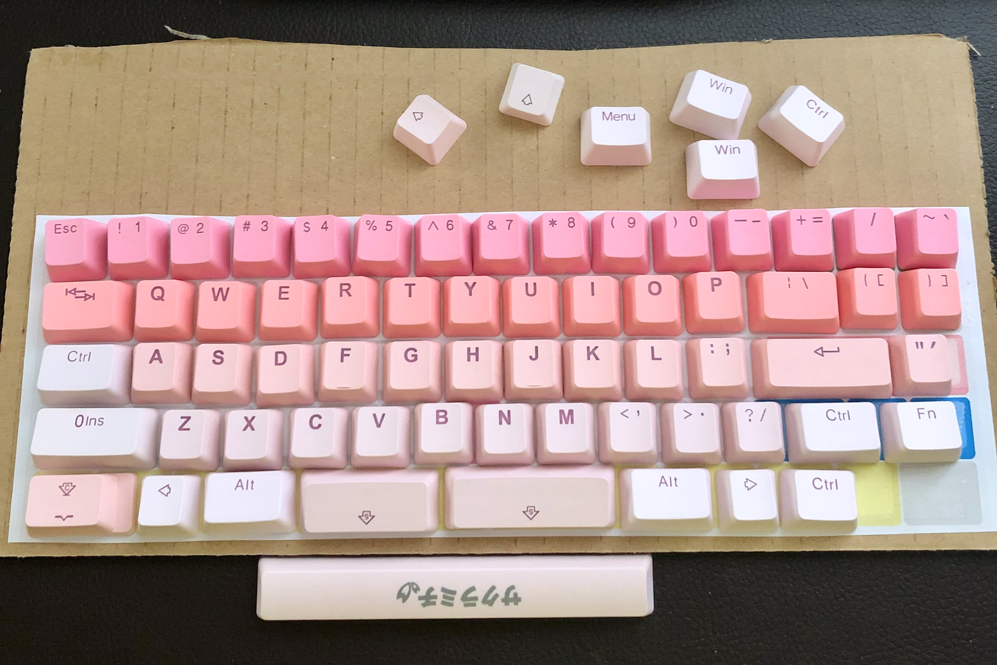
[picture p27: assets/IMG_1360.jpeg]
Jones v.0
  
Jones v.0 モックアップ

## Before v.0, 2020-05-27

物理配列について、

- [HHKB](https://happyhackingkb.com/jp/)
- [Treadstoneシリーズ](https://marksard.github.io/2018/12/17/about-treadstone48/)
- [Zinc（シンメトリカル版）](http://www.sho-k.co.uk/tech/735.html)
- [Katana60](http://xahlee.info/kbd/katana60_keyboard.html)

などを参考にしつつ、[Keyboard Layout Editor](http://www.keyboard-layout-editor.com)を使った机上検討を重ね、キーキャップを並べたモックアップをいくつか作成。

1行目と2行目のずれをなくしたものや、[QAZの並びでAを一番外側にしたりしたもの](http://www.keyboard-layout-editor.com/#/gists/f530b44df7799fa4d14944566bb18dd2)を作成するが、いずれも打鍵に不自然さがあったため、ボツ。

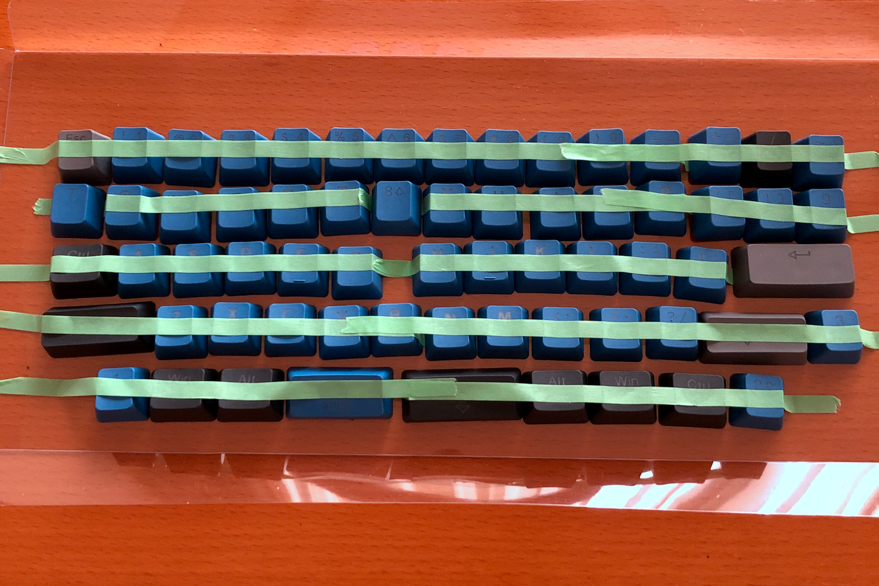
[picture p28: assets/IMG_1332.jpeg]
Jones before v.0
  
Jones before v.0 作成したモックアップのひとつ

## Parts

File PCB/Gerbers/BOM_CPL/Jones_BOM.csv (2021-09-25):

Comment | Designator | Footprint | LCSC
10uF | C1 | Capacitor_SMD:C_0805_2012Metric_Pad1.15x1.40mm_HandSolder | C15850
22pF | C2,C3 | Capacitor_SMD:C_0805_2012Metric_Pad1.15x1.40mm_HandSolder | C1804
0.1uF | C4,C5,C7 | Capacitor_SMD:C_0805_2012Metric_Pad1.15x1.40mm_HandSolder | C49678
1uF | C6 | Capacitor_SMD:C_0805_2012Metric_Pad1.15x1.40mm_HandSolder | C28323
PRTR5V0U2X | D10 | Package_TO_SOT_SMD:SOT-143
D | D0,D1,D2,D3,D4,D5,D6,D7,D8,D9,D11,D12,D13,D14,D15,D16,D17,D18,D19,D21,D22,D23,D24,D25,D26,D27,D28,D29,D30,D31,D32,D33,D34,D35,D36,D37,D38,D39,D40,D41,D42,D43,D44,D45,D46,D47,D48,D49,D50,D51,D52,D53,D56,D57,D59,D61,D62,D63,D64,D65,D67,D68,D69,D71,D73,D74,D75,D78,D79,D83,D84,D85,D87,D89,D91,D92,D93,D94,D95,D96,D97,D98 | Diode_SMD:D_SOD-123 | C81598
Conn_01x01 | EXT_P0,EXT_DP0,EXT_P1,EXT_DP1,EXT_P2,EXT_DP2,EXT_P3,EXT_DP3,EXT_P4,EXT_DP4,EXT_P5,EXT_DP5,EXT_P6,EXT_DP6,EXT_P7,EXT_DP7,EXT_P8,EXT_DP8,EXT_P9,EXT_DP9 | TestPoint:TestPoint_THTPad_D1.5mm_Drill0.7mm
500mA | F1 | Fuse:Fuse_1206_3216Metric_Pad1.42x1.75mm_HandSolder
MountingHole | H1,H2,H3,H4,H5 | MountingHole:MountingHole_2.2mm_M2
USB_C_Receptacle_USB2.0 | J1 | Connector_USB:USB_C_Receptacle_GCT_USB4085
Conn_01x03 | J2 | Connector_PinHeader_2.54mm:PinHeader_1x03_P2.54mm_Vertical
Conn_01x02 | J3 | Connector_PinHeader_2.54mm:PinHeader_1x02_P2.54mm_Vertical
Conn_02x03_Odd_Even | J5 | Connector_PinHeader_2.54mm:PinHeader_2x03_P2.54mm_Vertical
SolderJumper_2_Open | JP1 | Jumper:SolderJumper-2_P1.3mm_Open_Pad1.0x1.5mm
SolderJumper_3_Open | JP_LED1,JP_LED2 | Jumper:SolderJumper-3_P1.3mm_Open_Pad1.0x1.5mm_NumberLabels
SK6812MINI | LED1,LED2,LED3,LED4 | locallib:LED_SK6812MINI_PLCC4_3.5x3.5mm_P1.75mm_TriangleMark
Conn_01x03 | LED_STRIP1 | locallib:LED_Strip
#Jones_kbd v.1 (042) | LOGO1 | locallib:Jones_logo_B_R_60x98.2
Speaker | LS1 | Buzzer_Beeper:Buzzer_Murata_PKMCS0909E4000-R1
5.1k | R1,R2 | Resistor_SMD:R_0805_2012Metric_Pad1.15x1.40mm_HandSolder | C27834
22 | R3,R4 | Resistor_SMD:R_0805_2012Metric_Pad1.15x1.40mm_HandSolder | C17561
10k | R5,R6 | Resistor_SMD:R_0805_2012Metric_Pad1.15x1.40mm_HandSolder | C17414
1k | R7 | Resistor_SMD:R_0805_2012Metric_Pad1.15x1.40mm_HandSolder | C17513
4.7k | R8,R9 | Resistor_SMD:R_0805_2012Metric_Pad1.20x1.40mm_HandSolder | C17673
Conn_01x01 | Reserve_PF0,Reserve_AUDIO1,Reserve_AUDIO2,Reserve_PB5,Reserve_PD5,Reserve_PF6,Reserve_PC7,Reserve_PF7 | TestPoint:TestPoint_THTPad_D1.0mm_Drill0.5mm
5.2x5.2mm | ResetSW1 | Button_Switch_SMD:SW_SPST_TL3342
SW_Push | SW_0,SW_1,SW_\1,SW_`1,SW_-1,SW_Q1,SW_W1,SW_E1,SW_R1,SW_T1,SW_A1,SW_S1,SW_D1,SW_F1,SW_G1,SW_Z1,SW_X1,SW_C1,SW_V1,SW_B1,SW_=1,SW_UP1,SW_M1,SW_J1,SW_U1,SW_N1,SW_[1,SW_'1,SW_P1,SW_>1,SW_L1,SW_I1,SW_K1,SW_<1,SW_O1,SW_]1,SW_RIGHT1,SW_DOWN1,SW_;1,SW_Center1,SW_Y1,SW_LEFT1,SW_H1,SW_ESC1,SW_2,SW_B2,SW_]2,SW_[2,SW_'2,SW_3,SW_;3,SW_4,SW_5,SW_6,SW_7,SW_8,SW_9,SW_LWIN1u1,SW_Fn1u1,SW_LSFT1u1,SW_CAPS1u1,SW_CenterR1u1,SW_narrowCTL1u1,SW_narrow1u1,SW_CenterL1u1,SW_LSFT1u2,SW_L2-1u1 | MX_Alps_Hybrid:MXOnly-1U-Hotswap-guide
SW_Push | SW_;2 | MX_Alps_Hybrid:MXOnly-1U-NoLED
SW_Push | SW_BS1.5u2,SW_ENT1.5u2 | MX_Alps_Hybrid:MXOnly-1.5U-Hotswap-guide-Rotate
SW_Push | SW_BS2u1 | MX_Alps_Hybrid:MXOnly-2U-Hotswap-guide
SW_Push | SW_CTL1.5u1,SW_ENT1.5u1,SW_BS1.5u1,SW_RALT1.5u1,SW_TAB1.5u1,SW_LALT1.5u/MHEN1u1 | MX_Alps_Hybrid:MXOnly-1.5U-Hotswap-guide
SW_Push | SW_ENT2.25u1 | MX_Alps_Hybrid:MXOnly-2.25U-Hotswap-LeftRotate-guide
SW_Push | SW_LSFT1.75u1 | MX_Alps_Hybrid:MXOnly-1.75U-Hotswap-guide
SW_Push | SW_LSFT2u1,SW_LSPC2u1,SW_RSPC2u1,SW_CSPC2u1 | MX_Alps_Hybrid:MXOnly-2U-Hotswap-ReversedStabilizers-guide
SW_Push | SW_LSPC2.25u1 | MX_Alps_Hybrid:MXOnly-2.25U-Hotswap-guide
Rotary_Encoder_Switch | SW_RE1,SW_RE2 | locallib:RotaryEncoder_Alps_EC11K-Switch_Vertical_H20mm
SW_Push | SW_narrowRALT1.25u1,SW_ROPT1.25u1,SW_RALT1.25u1,SW_LALT1.25u1,SW_CTL1.25u1,SW_LWIN1.25u1,SW_BS1.25u1,SW_ENT1.25u1 | MX_Alps_Hybrid:MXOnly-1.25U-Hotswap-guide
SW_Push | SW_narrowRWIN1.25u1,SW_BS1.25u2,SW_ENT1.25u2 | MX_Alps_Hybrid:MXOnly-1.25U-Hotswap-guide-Rotate
ATmega32U4-MU | U1 | Housings_DFN_QFN:QFN-44-1EP_7x7mm_Pitch0.5mm | C112161
24LC64 | U2 | Package_SO:SO-8_3.9x4.9mm_P1.27mm | C79988
16MHz | Y1 | Crystal:Crystal_SMD_3225-4Pin_3.2x2.5mm_HandSoldering | C13738

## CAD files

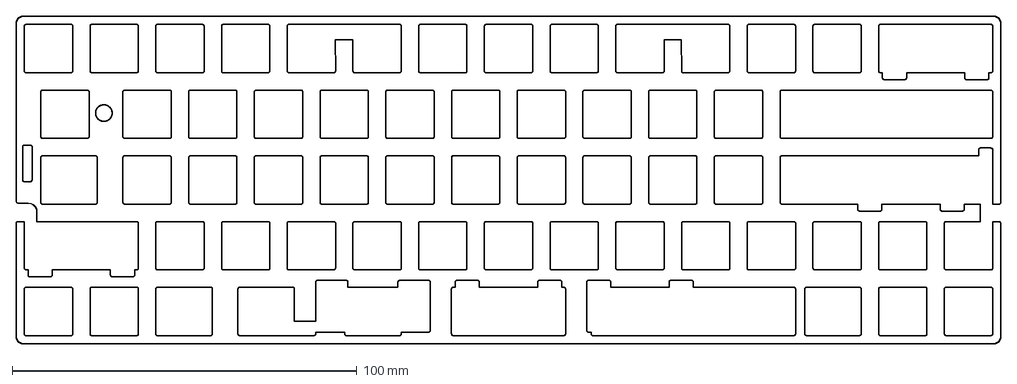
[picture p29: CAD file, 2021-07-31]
Plate/v.4.0.1/plate_v.4.0.3.dxf
285.4 x 94.9 mm

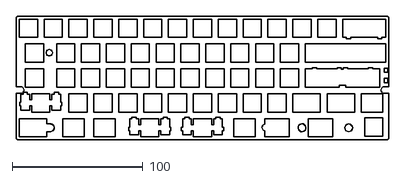
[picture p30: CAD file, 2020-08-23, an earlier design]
Plate/v.0.1/keyplate_SplitSpace_Merged_14x14.dxf
285.4 x 94.9

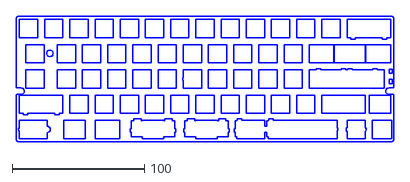
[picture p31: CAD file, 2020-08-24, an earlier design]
Plate/v.0.2/output.dxf
285.4 x 94.9

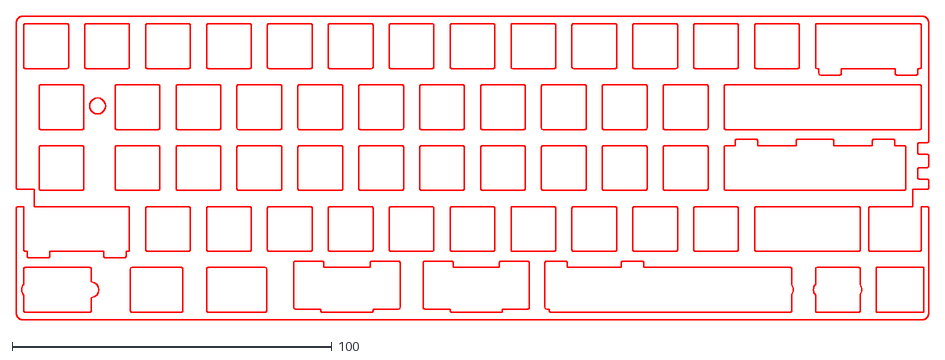
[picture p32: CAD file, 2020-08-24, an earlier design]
Plate/v.0.3/output.dxf
285.4 x 94.9

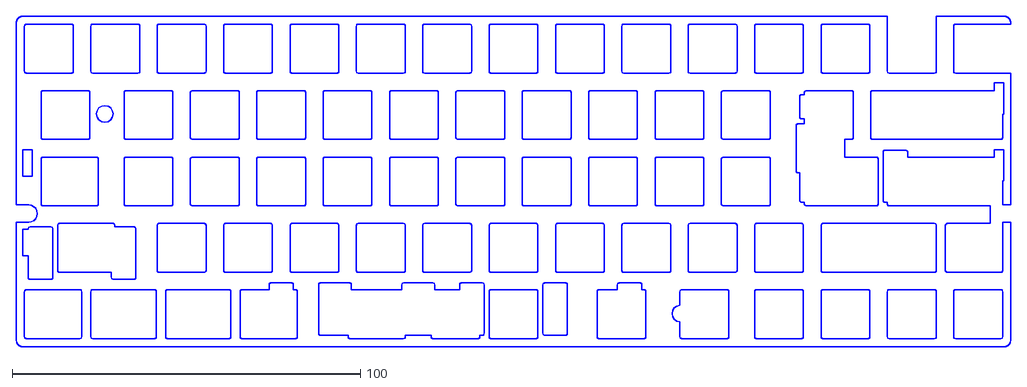
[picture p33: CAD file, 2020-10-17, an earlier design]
Plate/v.3.5.4/plate.dxf
285.4 x 94.9

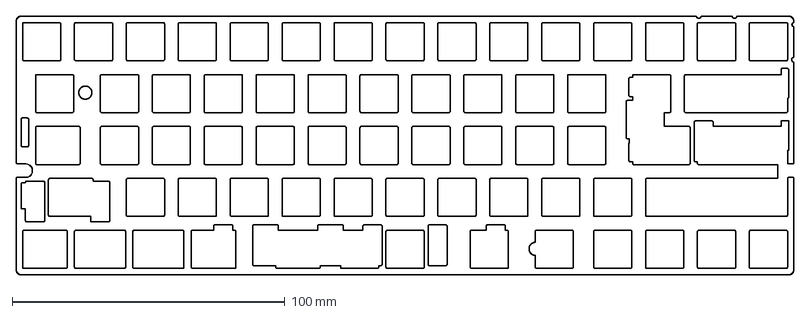
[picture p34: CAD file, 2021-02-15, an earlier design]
Plate/v.3.5.5/plate_v.3.5.5.dxf
285.4 x 94.9 mm

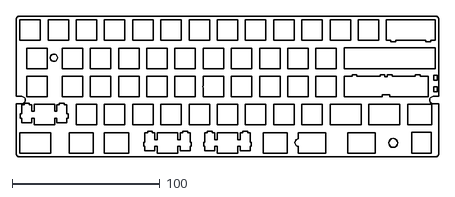
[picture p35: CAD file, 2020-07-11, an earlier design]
Plate/v.0.1/keyplate_SplitSpace_Merged_for_切断堂.dxf
285.4 x 94.9

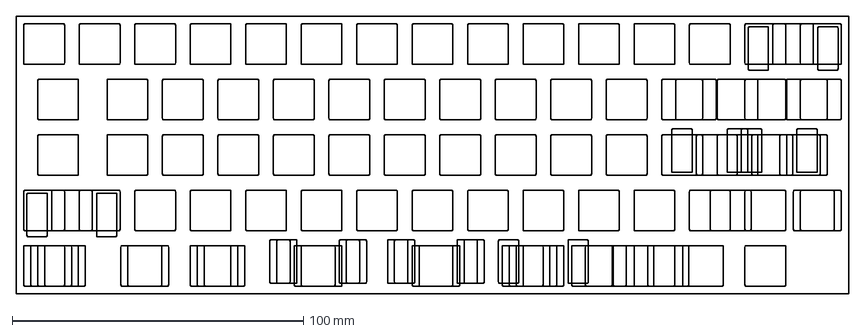
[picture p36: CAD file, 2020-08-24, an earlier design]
Plate/v.0.3/ai03_plate_generator.dxf
285.8 x 95.2 mm

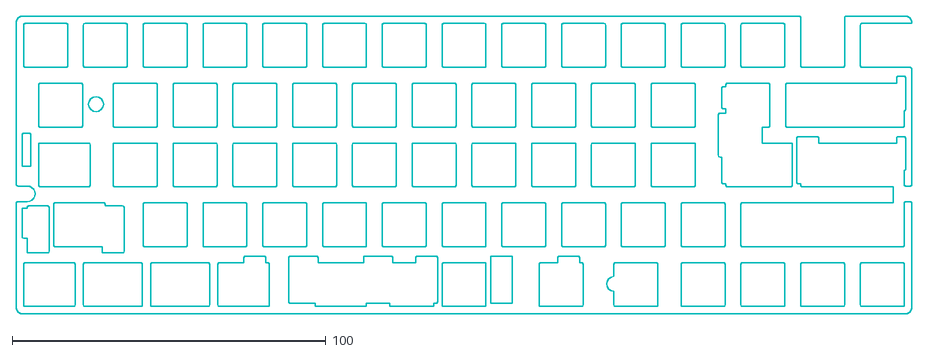
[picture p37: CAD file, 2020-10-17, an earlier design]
Plate/v.3.5.4/plate_ansi_jp_SpaceCadet.dxf
285.4 x 94.9

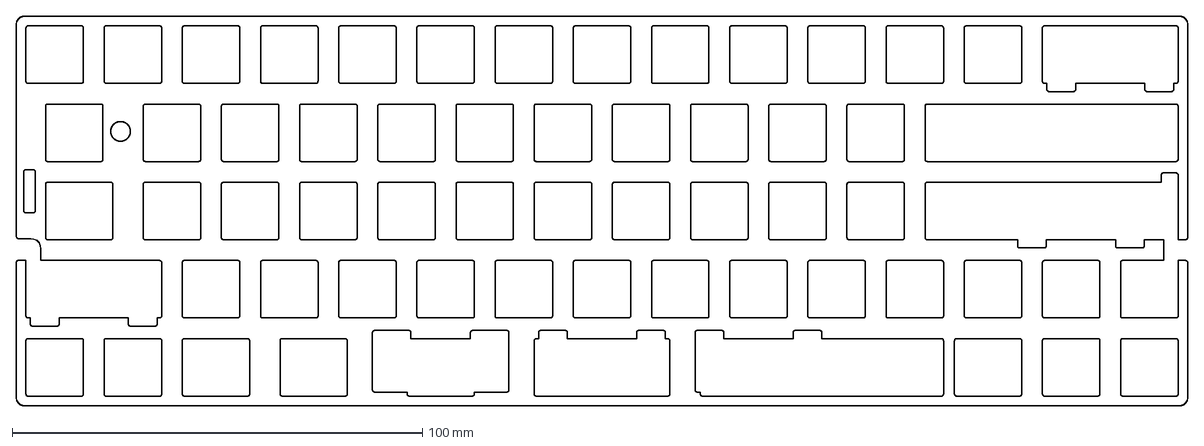
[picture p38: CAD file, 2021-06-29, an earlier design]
Plate/v.4.0.1/plate_v.4.0.1.dxf
285.4 x 94.9 mm

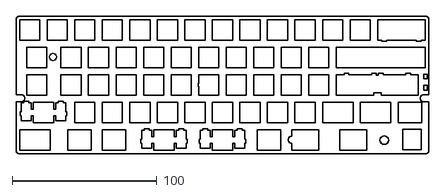
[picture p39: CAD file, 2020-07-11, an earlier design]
Plate/v.0.1/keyplate_SplitSpace_Merged.dxf
285.4 x 94.9

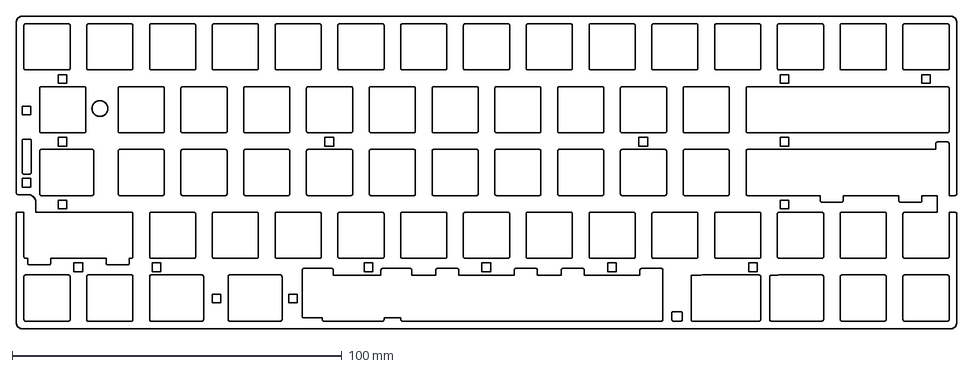
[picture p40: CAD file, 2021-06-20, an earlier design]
Plate/v.4.0.1/plate_v.4.0.dxf
285.4 x 94.9 mm

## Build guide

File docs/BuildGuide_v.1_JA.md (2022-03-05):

# Jones v.1 ビルドガイド

購入していただいた方、リポジトリから製造していただいた方、その他の皆様、Jonesに興味を持っていただきありがとうございます。

このドキュメントは、Jones v.1を組み立てるためのビルドガイドです。  
Jonesのコンセプトや特徴、ビルド例などについては、[Jones README](https://github.com/jpskenn/Jones/blob/master/README.md)をご覧ください。

ビルドガイド全体に目を通して作業手順を把握しておくとミスの防止につながりますので、ぜひ、一度お読みになってから組み立て作業を始めてください。

ファームウェアが書き込み済みですので、基本的な組み立ては、基板にソケットをはんだ付けしてケースに取り付けるだけです。  
オプションのインジケータLEDの取り付け作業を除いて作業の難易度はそれほど高くないため、手順は要点のみ記載しています。  
組み立て初心者の方や、しっかりと確認しながら組み立てたい方は、

<details>
<summary>《詳しい説明》</summary>

ここに追加の説明を表示します。
</details>

と書かれたところをクリックすると、追加の説明が表示されます。

---

## 目次

<!-- @import "[TOC]" {cmd="toc" depthFrom=2 depthTo=3 orderedList=false} -->

<!-- code_chunk_output -->

- [目次](#目次)
- [Jones v.1の特徴, 機能](#jones-v1の特徴-機能)
- [注意事項、制限など](#注意事項制限など)
- [部品リスト](#部品リスト)
  - [キット内容](#キット内容)
  - [別途用意が必要な部品](#別途用意が必要な部品)
  - [オプション部品](#オプション部品)
- [組み立てに必要な工具](#組み立てに必要な工具)
- [組み立て前の確認](#組み立て前の確認)
  - [同梱物の確認](#同梱物の確認)
  - [接続の確認](#接続の確認)
  - [ソケット用パッドの確認](#ソケット用パッドの確認)
- [組み立て手順](#組み立て手順)
  - [作りたいレイアウトを決める](#作りたいレイアウトを決める)
  - [スイッチ用ソケットの取り付け](#スイッチ用ソケットの取り付け)
  - [（オプション）インジケータLEDの取り付け](#オプションインジケータledの取り付け)
  - [（オプション）スピーカーの取り付け](#オプションスピーカーの取り付け)
  - [（オプション）ロータリーエンコーダの取り付け](#オプションロータリーエンコーダの取り付け)
  - [スタビライザーの取り付け](#スタビライザーの取り付け)
  - [スイッチの取り付け](#スイッチの取り付け)
  - [ケースへの取り付け](#ケースへの取り付け)
  - [仕上げ](#仕上げ)
- [参考](#参考)
  - [TIPS：キーキャップ](#tipsキーキャップ)
  - [機能追加：アンダーグロー用LEDテープの使用](#機能追加アンダーグロー用ledテープの使用)
  - [機能追加：1個のスピーカーで2音同時再生する方法](#機能追加1個のスピーカーで2音同時再生する方法)
  - [打鍵感向上：ケースへの基板取り付け方法の変更](#打鍵感向上ケースへの基板取り付け方法の変更)
  - [打鍵感向上：ケース内部の制振と静音化](#打鍵感向上ケース内部の制振と静音化)
  - [打鍵感向上：キープレートと基板間のパテ埋め](#打鍵感向上キープレートと基板間のパテ埋め)
  - [トラブル対応：正常に入力できないスイッチの原因調査](#トラブル対応正常に入力できないスイッチの原因調査)
  - [トラブル対応：LEDの取り付け不良調査](#トラブル対応ledの取り付け不良調査)
  - [資料：USBコネクタ接続図](#資料usbコネクタ接続図)
  - [資料：ファームウェアの書き込み方法](#資料ファームウェアの書き込み方法)
  - [資料：初期ファームウェアの機能と設定値](#資料初期ファームウェアの機能と設定値)
  - [資料：Jonesキーボードのファームウェア](#資料jonesキーボードのファームウェア)
  - [資料：EEPROMを消去して、初期状態に戻す方法](#資料eepromを消去して初期状態に戻す方法)

<!-- /code_chunk_output -->

---
## Jones v.1の特徴, 機能

- 主要な部品を実装済み  
  はんだ付けが必要な部品は、MXソケットとオプションパーツのみ。

- 3つのレイアウト、Wide（ワイド）, Narrow（ナロー）, Normal（ノーマル）を選択可能  
  レイアウト一覧：[Keyboard Layout Editor: Jones v.1(042)](http://www.keyboard-layout-editor.com/#/gists/53fab8cd4a4480980921f37c39e1f5f3)

- 一般的な日本語108キー、英語104キーのキーキャップセットに対応。

- RemapやVIAなどのキーマップ書き換えツールに対応したファームウェアを書き込み済み  
  ソース（[develop_jones](https://github.com/jpskenn/qmk_firmware/tree/develop_Jones/keyboards/jones/v1)）を元に、自由に改造することも可能。

- 外部EEPROM（8KB）を搭載し、十分な数のレイヤーを使用可能

- GH60型やPoker型に互換性のあるケースに対応  
  Jones用ボトムプレートキットと組み合わせて、ケースレスで高さを抑えて使用することも可能。

- オプションとして、以下のハードウェア機能を使用可能
  - レイヤーインジケータLED
  - アンダーグローLEDテープ
  - ロータリーエンコーダ
  - スピーカー

---

## 注意事項、制限など

- GH60型, Poker型ケースを使用する場合、ケースのネジ穴との干渉を避けるため、スイッチの足の加工が必要です。

- 一部のキーは上下逆向きや横向きに取り付けます。  
  キーキャップが取り付けにくかったり、キーキャップとスイッチが干渉し打鍵感が悪くなることがあります。

- 左シフトキーの2Uスタビライザーは、ケースネジに干渉するため使用を避けてください。

- スピーカーは、左シフトキーが1.75uまたは2uの場合にのみ取り付けることができます。

- 中央下のネジはキースイッチやスタビライザーと干渉するため、ねじ止めせずに使用します。

- もしかしたら取り付けできないケースがあるかもしれません。  
  取り付け確認済みのケースは次の通りです。  
  （これら以外のケースへの取り付けの成功／失敗の報告を募集しております。）
  - [KBDfans TOFU 60% ALUMINUM CASE](https://kbdfans.com/products/kbdfans-tofu-60-aluminum-case)
  - [KBDfans 5° FROSTED ACRYLIC CNC 60% CASE](https://kbdfans.com/collections/60-layout-case/products/pre-orderkbdfans-5-60-case)
  - [KBDfans 5° FIVE DEGREE 60% ALUMINUM CASE](https://kbdfans.com/collections/60-layout-case/products/pre-orderkbdfans-5-60-case)
  - [KBDfans 60% ALUMINUM LOW PROFILE CASE](https://kbdfans.com/collections/60-layout-case/products/customized-gh60-aluminum-case)
  - [60% プラスチックケース](https://yushakobo.jp/shop/60-plastic-case/)（簡単な加工が必要）
  - [Jones用ボトムプレート](https://booth.pm/ja/items/3266269)

  木製のケースは、ケースの内部構造が基板うら側のソケットやスタビライザーに干渉するものが多いため、注意してください。  
  ケース内部の外周部に数ミリ幅の段があり、基板を支えるような構造がこれに該当します。  
  カッターや彫刻刀で干渉箇所を削れば取り付けできますが、ひと手間かかる加工作業になります。  
  - [60% 竹製ケース（パームレスト一体型）](https://shop.yushakobo.jp/products/a0700bp-01)  
  Lekipon様より[ご報告](https://twitter.com/lekipon/status/1439607642431754250)をいただきました。  
  Dropで販売されている[NPKC 60% WOODEN WRIST REST KEYBOARD CASE](https://drop.com/buy/npkc-60-percent-wooden-wrist-rest-keyboard-case)も同じ形状で、干渉すると思われます。
  - [60% 木製ケース](https://shop.yushakobo.jp/products/60-wood-case)  
  竹製ケースと同じような内部構造で、写真で見ると干渉は少なめですが、注意が必要です。
  - その他の木製ケース

---

## 部品リスト

このキットを組み立てるためには、”キット内容”に加え、”別途用意が必要な部品”が必要です。  
好みに合わせて必要な数をお買い求めください。

”オプション部品”は使いたい機能などに合わせて用意してください。  

部品の購入先は、Self-Made Keyboards in Japanの[ショップリスト](https://scrapbox.io/self-made-kbds-ja/ショップリスト)などを参考にしてください。

### キット内容

| 部品名 | 個数 | 備考 |
| ----- | :-----: | ----- |
| ご案内リーフレット | 1 | |
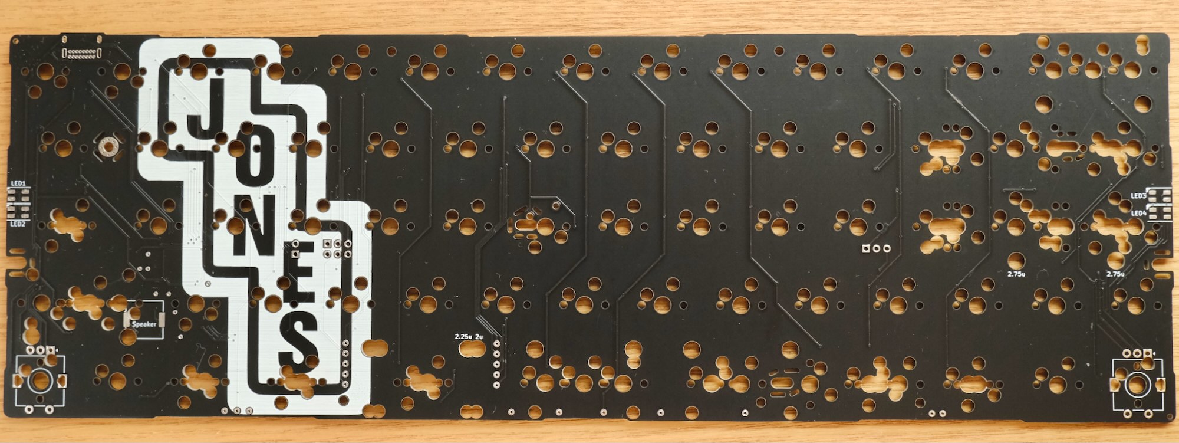
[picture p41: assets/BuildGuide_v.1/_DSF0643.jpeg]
基板おもて側
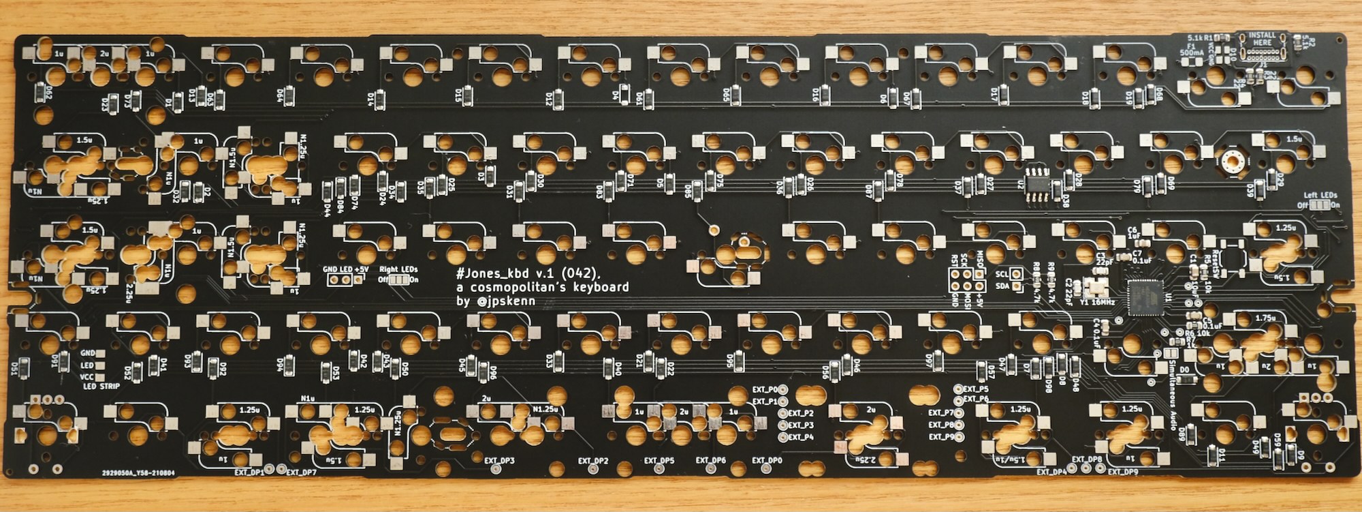
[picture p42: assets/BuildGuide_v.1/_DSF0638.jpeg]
基板裏側
| 基板 | 1 | [おもて側<br>](../assets/BuildGuide_v.1/_DSF0643.jpeg)<br>[裏側<br>](../assets/BuildGuide_v.1/_DSF0638.jpeg) |
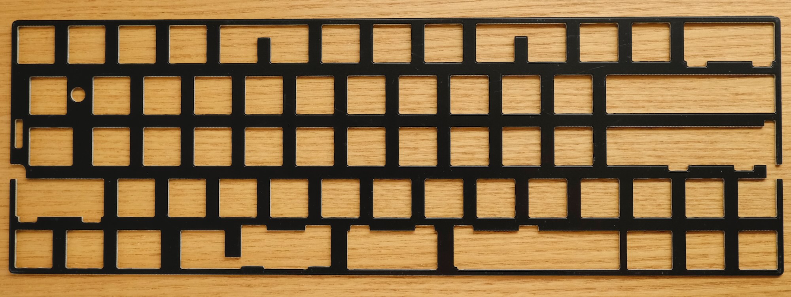
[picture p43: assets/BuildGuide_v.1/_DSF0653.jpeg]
キープレートおもて側
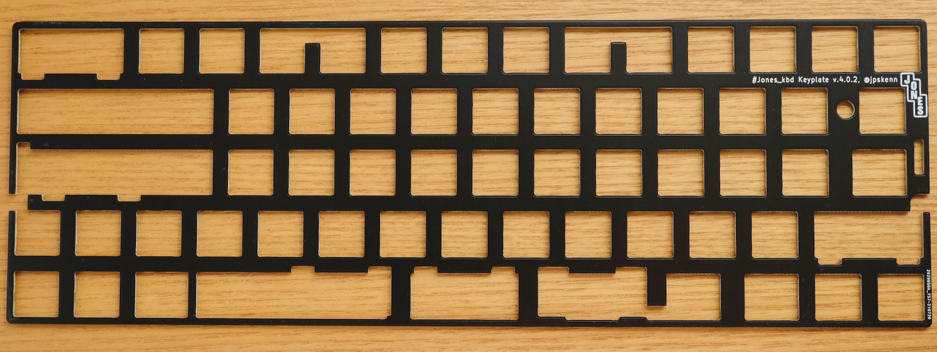
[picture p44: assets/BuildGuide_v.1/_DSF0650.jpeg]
キープレート裏側
| キープレート | 1 | [おもて側<br>](../assets/BuildGuide_v.1/_DSF0653.jpeg)<br>[裏側<br>](../assets/BuildGuide_v.1/_DSF0650.jpeg) |
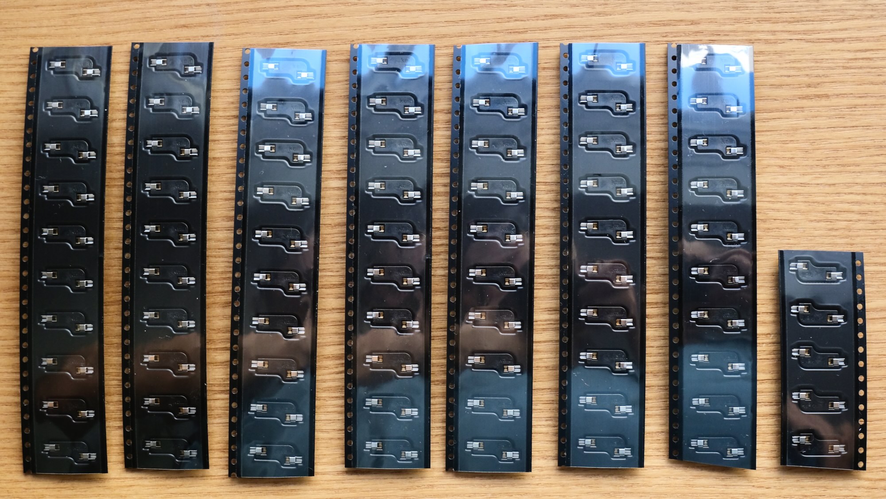
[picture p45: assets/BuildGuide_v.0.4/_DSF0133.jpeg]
MXソケット
| MXソケット | 75（予備含む） | [](../assets/BuildGuide_v.0.4/_DSF0133.jpeg) |
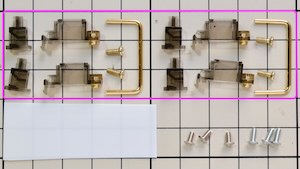
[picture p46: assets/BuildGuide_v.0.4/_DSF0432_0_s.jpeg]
| PCBマウント スタビライザー<br>2uサイズ, ねじ止め式 | 2 | [](../assets/BuildGuide_v.0.4/_DSF0432_0.jpeg)<br>2.25uのキーにも使用できます。 |
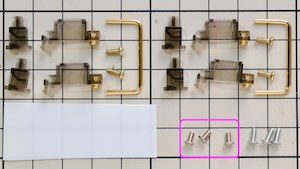
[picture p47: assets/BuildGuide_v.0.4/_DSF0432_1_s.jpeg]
| 低頭ネジ, M2 4mm | 3 | [](../assets/BuildGuide_v.0.4/_DSF0432_1.jpeg) |
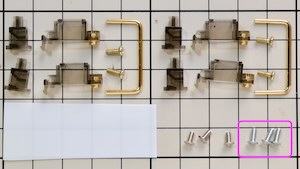
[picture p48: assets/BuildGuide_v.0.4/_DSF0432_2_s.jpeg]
| 低頭ネジ, M2 5mm | 3 | [](../assets/BuildGuide_v.0.4/_DSF0432_2.jpeg) |
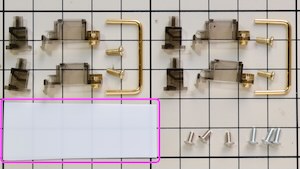
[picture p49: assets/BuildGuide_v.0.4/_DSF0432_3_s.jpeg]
| プラ板 | 1 | [](../assets/BuildGuide_v.0.4/_DSF0432_3.jpeg) <br>LEDインジケータ取り付け時のみ使用。|

※出荷時期によってメーカーや品番などが変わることがあります

### 別途用意が必要な部品

| 部品名 | 個数 | 備考 |
| ----- | :-----: | ----- |
| MXスイッチ | 最大 70 | 取り付け安定性の高い5pinタイプを推奨。<br>スイッチの端子折れや故障した場合に備えて、いくつか予備があると安心。 |
| キーキャップ<br>MXスイッチ用 | 必要数 | 一般的な日本語108または英語104のキーキャップセットに対応。<br>Narrowレイアウトを隙間なく埋める場合はカスタムキーキャップセットが必要。|
| PCBマウント スタビライザー<br>2uサイズ | 必要数 | Normalレイアウトで英語104キーキャップを使う場合など、キット付属の2個では足りない場合に必要。<br>確実に固定できるねじ止め式を推奨。<br>2uサイズは2.25uのキーにも使用できます。 |
| GH60型, Poker型ケース<br>または<br>Jones用ボトムプレートキット(\*) | 1 | |
| USBケーブル （Type-C） | 1 | |

\* Jones用ボトムプレートキットの内容は次の通り
| 部品名 | 個数 | 備考 |
| ----- | :-----: | ----- |
| ご案内リーフレット | 1 ||
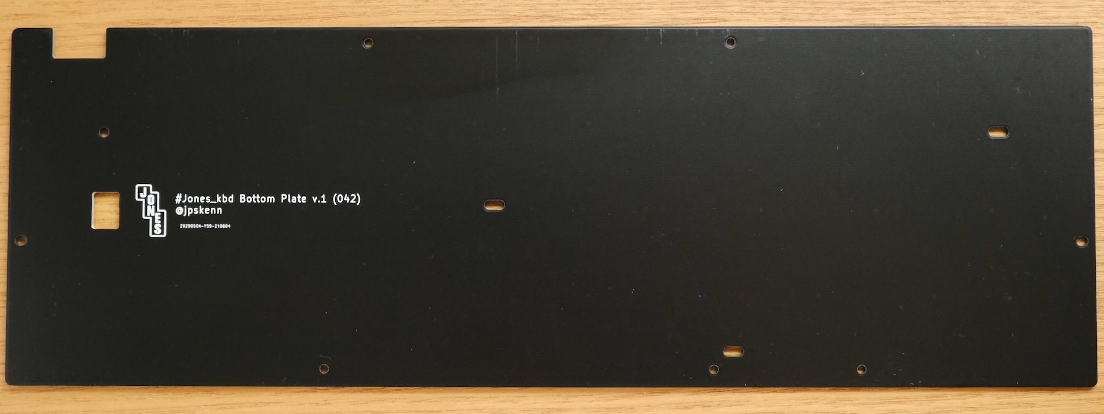
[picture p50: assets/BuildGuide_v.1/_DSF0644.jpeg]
ボトムプレートおもて側
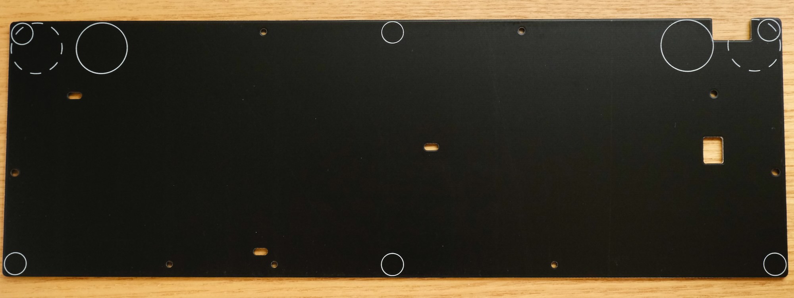
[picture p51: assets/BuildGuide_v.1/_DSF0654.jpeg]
ボトムプレート裏側
| Jones用ボトムプレート v.1 | 1 | [おもて側<br>](../assets/BuildGuide_v.1/_DSF0644.jpeg)<br>[裏側<br>](../assets/BuildGuide_v.1/_DSF0654.jpeg) |
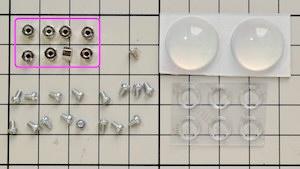
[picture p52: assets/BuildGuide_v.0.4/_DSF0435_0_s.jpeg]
| スペーサー, M2 3mm | 8 | [](../assets/BuildGuide_v.0.4/_DSF0435_0.jpeg) |
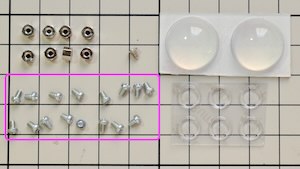
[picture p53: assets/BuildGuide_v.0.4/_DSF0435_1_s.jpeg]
| ネジ, M2 3mm | 16 | [](../assets/BuildGuide_v.0.4/_DSF0435_1.jpeg) |
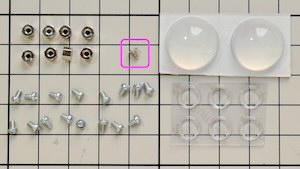
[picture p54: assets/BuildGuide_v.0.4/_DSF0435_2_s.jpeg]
| ネジ, M2 3mm, 低頭 | 1 | [](../assets/BuildGuide_v.0.4/_DSF0435_2.jpeg) |
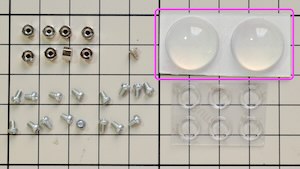
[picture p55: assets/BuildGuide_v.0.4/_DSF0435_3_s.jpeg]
| ゴム足 大 | 2 | [](../assets/BuildGuide_v.0.4/_DSF0435_3.jpeg) |
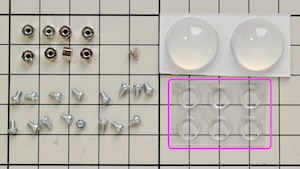
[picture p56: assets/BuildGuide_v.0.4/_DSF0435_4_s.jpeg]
| ゴム足 小 | 6 | [](../assets/BuildGuide_v.0.4/_DSF0435_4.jpeg) |

※出荷時期によってメーカーや品番、色などが変わることがあります

### オプション部品

| 部品名 | 個数 | 備考 |
| ----- | :-----: | ----- |
| LED<br>SK6812MINI | 2 または 4 | 左側2個、右側2個、または左右両側4個。 |
| フルカラーシリアルLEDテープ<br>幅1cm, 1mあたり60個のLED | 1本<br>（LED15個がついた約25cm） | Neopixel WS2812BやRGBテープと表記されていることもあります。 |
| ロータリーエンコーダ<br>ALPS EC11, ALPS EC12またはその互換品 | 最大 2 | 左側1個、右側1個、または左右両側2個。 |
| ロータリーエンコーダ用ノブ（つまみ）| 最大 2 | ロータリーエンコーダの軸の形状に合ったもの。 |
| スピーカー<br>Murata PKMCS0909E4000-R1 | 1 | |

---

## 組み立てに必要な工具

M2ネジに対応する先の細いドライバー、ピンセット、はんだ付け関連用品など、一般的な電子工作向け工具を使用します。  
[遊舎工房の工具セット](https://yushakobo.jp/shop/a9900to/)を参考に用意してください。

キースイッチの取り外し用の工具があると作業がはかどります。  
[TALP KEYBOARDで売っているこのタイプ](https://talpkeyboard.net/items/601362fe2438601925ad0692)は、1本でキースイッチとキーキャップの両方に使えるので便利です。

また、マスキングテープが1巻あると、基板や部品の仮固定などに使えて便利です。

なお、無くても組み立てはできますが、何か不具合があった場合の原因調査ではテスターが必要になることがあります。

---

## 組み立て前の確認

組み立てを開始する前に、同梱物と基板についての基本的な確認をおこないます。  
何か問題があった場合は作業を中止し、キット同梱のリーフレットに記載された連絡先へ問い合わせてください。

*組み立ての開始後は初期不良として対応できかねる場合があります。*

### 同梱物の確認

- 同梱物に不足がないこと

- 基板に配線が切れるような大きく深い傷や割れなどの破損がないこと

- 梱包の中に小さな部品が落ちていないこと（＝基板に実装された部品が外れていないこと）

### 接続の確認

MacやPCに接続して、キーボードとして認識されることを確認します。

```aside
充電用ではないUSBケーブルを使用してください。
他の機器を接続して使用した実績のあるケーブルを使うと、無用のトラブルを防げます。
```

下記のOS別の確認方法を参考に、確認してください。

<details>
<summary>《Mac, macOS Big Sur 11.4》</summary>

キーボードとMacを接続します。

接続した際に`キーボード設定アシスタント`が表示されることがありますが、この段階ではキーを押すことができないため、そのまま放っておくか、閉じるボタンで閉じておきます。

```aside
キーボード設定アシスタントは、次の操作でいつでも呼び出すことができます。

システム環境設定 → キーボード と進み、
キーボード タブ内の キーボードの種類を変更… ボタンを押す。
```

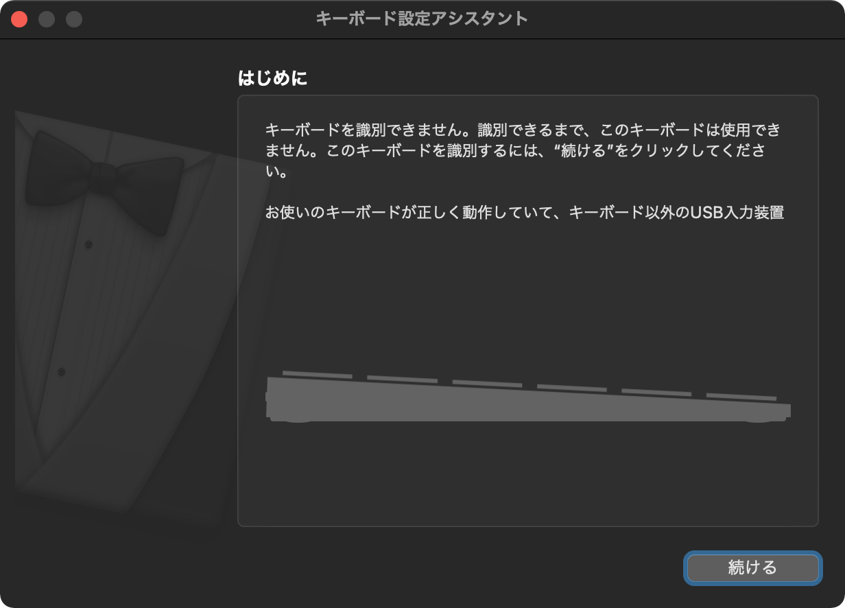
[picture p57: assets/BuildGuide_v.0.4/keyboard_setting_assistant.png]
キーボード設定アシスタント
  
キーボード設定アシスタント, そのまま放っておくか、閉じる

メニューバーから、`` → `このMacについて`を選び、表示された画面で`システムレポート…`をクリックします。  
システム情報が表示されたら、左側の`ハードウェア`から`USB`を選択します。

右側の`USB装置ツリー`のどこかに`Jones`というデバイスが表示されていれば、正しく認識されています。  
`USB装置ツリー`の下の方が見切れている場合があるため、スクロールして確認してください。

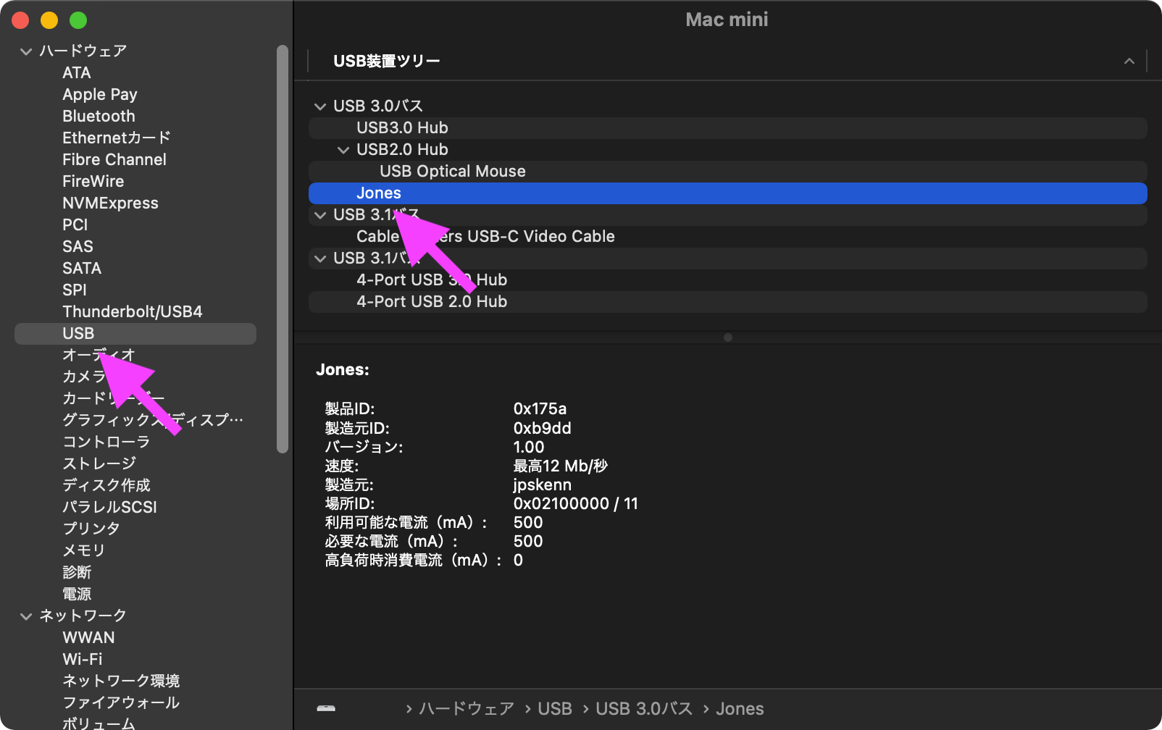
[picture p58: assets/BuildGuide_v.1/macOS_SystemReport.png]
Mac System Report
  
システム情報の表示
</details>

<details>
<summary>《Windows, 10 Pro 1909(18363.1082)》</summary>

キーボードとPCを接続します。

`スタートボタン`から`設定`を開いて`デバイス`を選択し、  
`マウス、キーボード、ペン`の項目に`Jones`が表示されていれば、正しく認識されています。

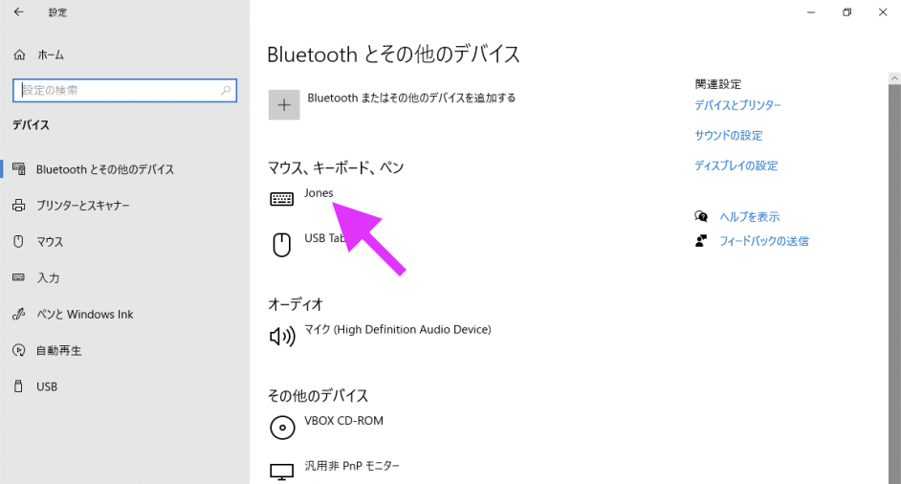
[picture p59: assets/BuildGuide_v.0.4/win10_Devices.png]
Windows Devices
  
デバイスの表示
</details>

### ソケット用パッドの確認

キースイッチのソケットをはんだ付けするソケット用パッド（ソケットをはんだ付けする基板上の金属部分）が、電気的に正しく反応することを確認します。  

レイアウトを画面に表示させて確認できるのでキーマップ書き換えツール[Remap](https://remap-keys.app/)のテスト機能を使う方法がおすすめです。  

<details>
<summary>《詳しい説明》</summary>

その他の方法として、OSのキーボードビューアや[Keyboard Checker](https://keyboardchecker.com)、[QMK Configurator](https://config.qmk.fm/)のキーボード入力テストを使用して確認することもできます。  
[VIA](https://caniusevia.com)を使用する際は、この定義ファイル（[jones_v1(042).json](https://gist.github.com/jpskenn/b0e62ff02264ebc955b5153c9b64200d)）を読み込ませてください。

ここでは、キーマップ書き換えツール[Remap](https://remap-keys.app/)のテスト機能を使い、確認を行います。

基板の裏面が上側になるように置き、PCやMacとUSBケーブルで接続します。

Google Chromeブラウザ（Web HID対応のバージョン89以降）で、[Remap](https://remap-keys.app/)を開きます。

`START REMAP FOR YOUR KEYBOARD`をクリックしてキーボード接続画面に進みます。

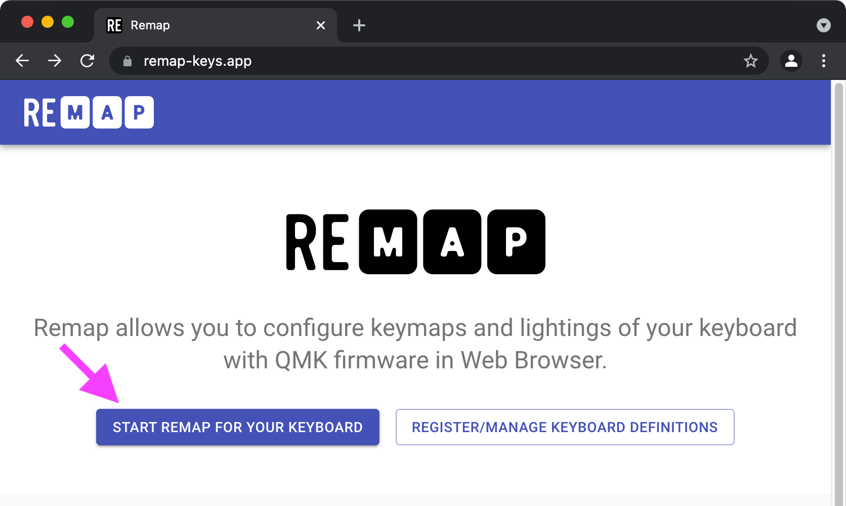
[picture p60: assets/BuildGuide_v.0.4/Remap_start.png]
START REMAP FOR YOUR KEYBOARD


`+ KEYBOARD`をクリックしてデバイスへの接続要求画面を開きます。

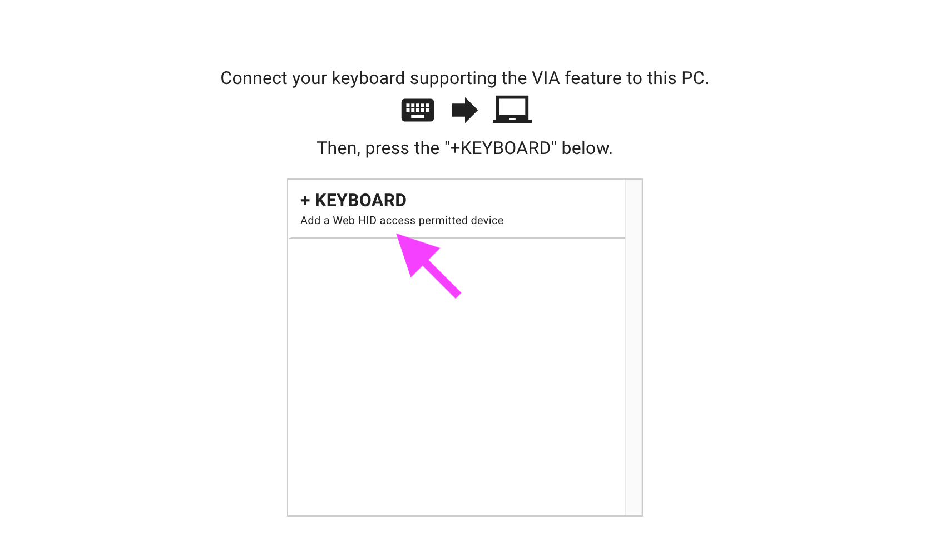
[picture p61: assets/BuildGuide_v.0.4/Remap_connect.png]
+ KEYBOARD


デバイスへの接続要求画面で`Jones`を選択して`接続`をクリックすると、画面にキーボードのレイアウトが表示されます。

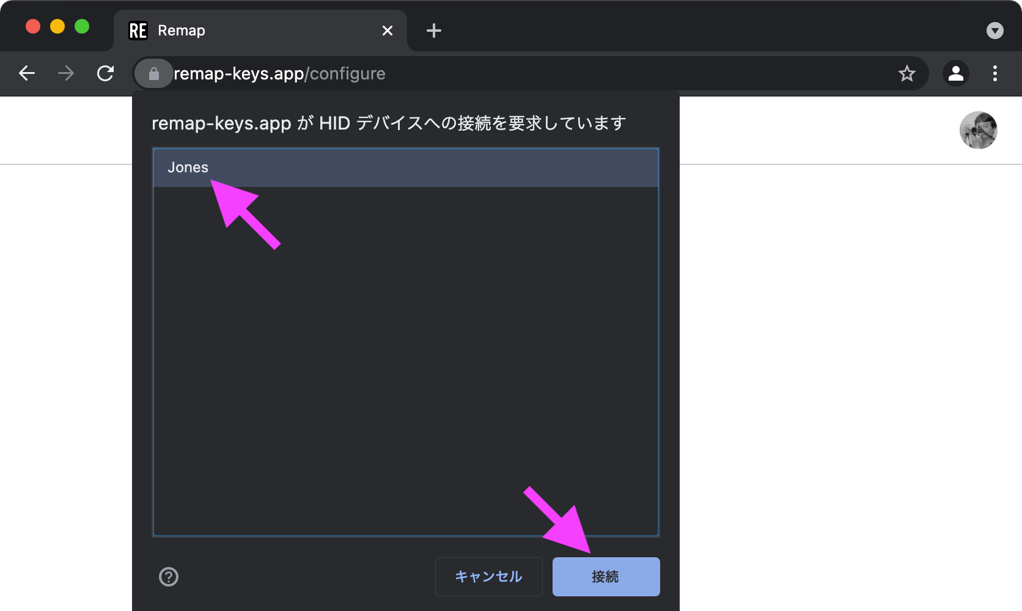
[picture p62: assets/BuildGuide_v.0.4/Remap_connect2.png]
デバイスへの接続要求


レイアウト右側の`Layout Option`で、組み立てようとしているレイアウトに設定します。  
キーマップは組み立て完了後に変更するため、ここではレイアウトだけ設定して先へ進みます。

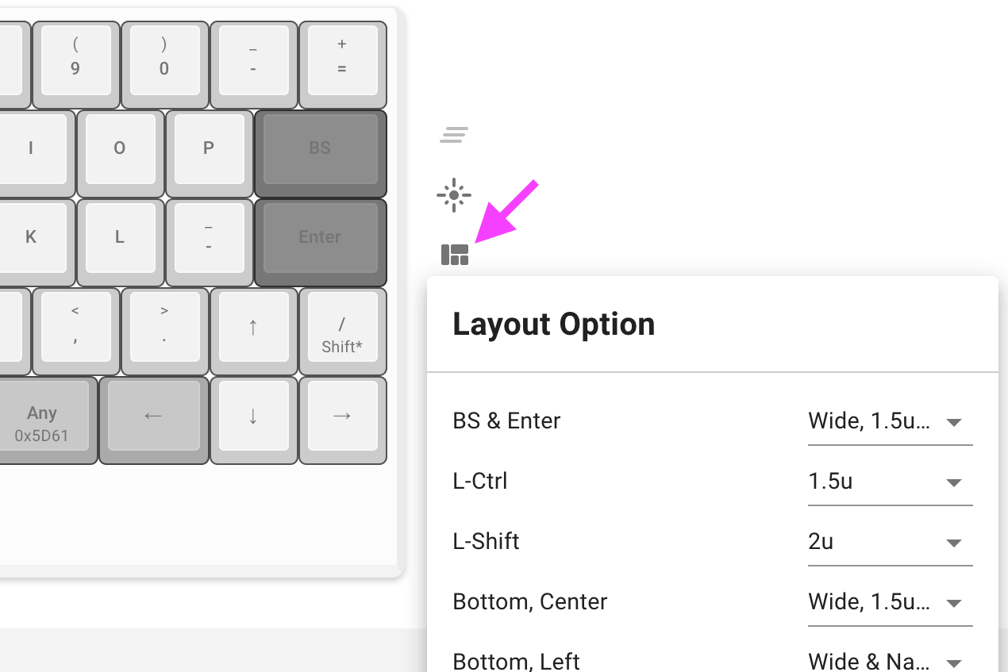
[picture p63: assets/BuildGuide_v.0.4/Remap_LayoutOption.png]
Layout Option


レイアウト右側の`…`をクリックし、`Test Matrix mode`を選択します。

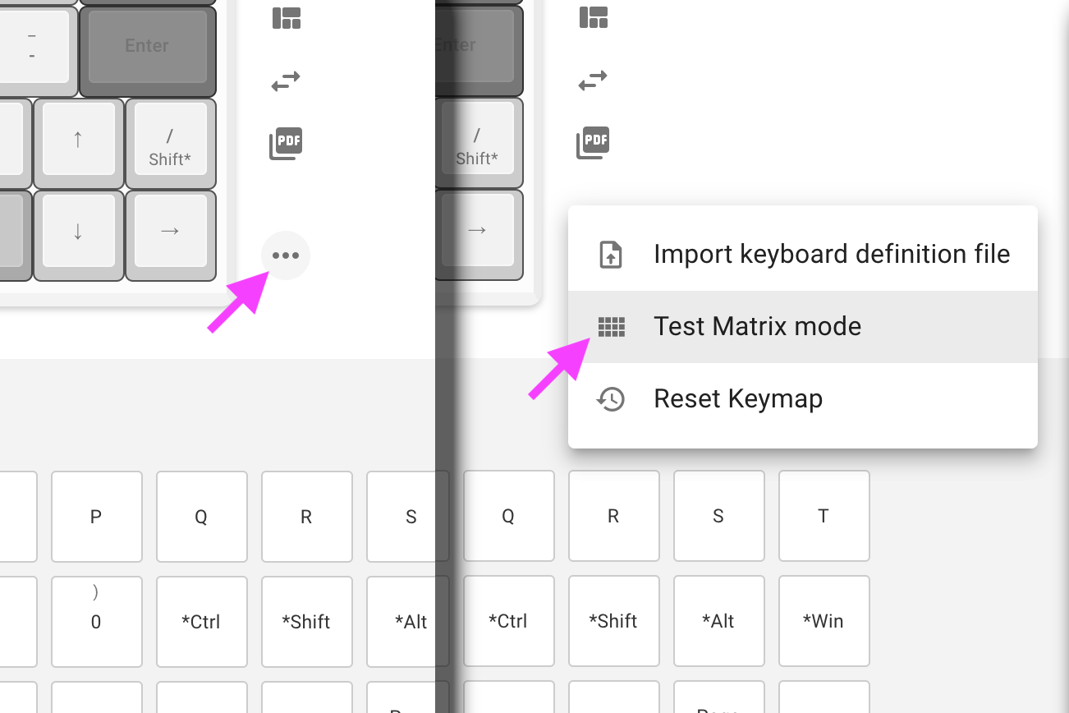
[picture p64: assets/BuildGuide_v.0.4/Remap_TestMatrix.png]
Test Matrix Mode


ピンセットなどの電気を通すものを使い、基板裏面のソケット用パッドをショートさせます。

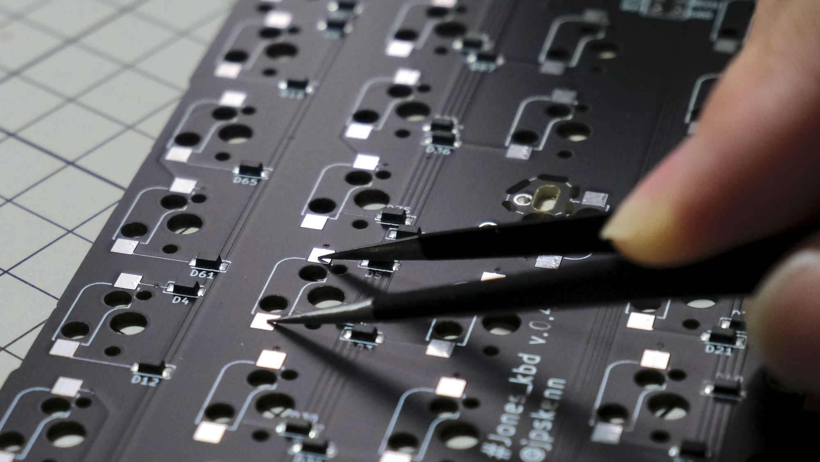
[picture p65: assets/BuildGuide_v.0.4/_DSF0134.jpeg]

ピンセットを使ってパッド部分をショートさせる様子

Remapの画面で、ショートさせたパッドに対応するキーの色が変わることを確認します。  

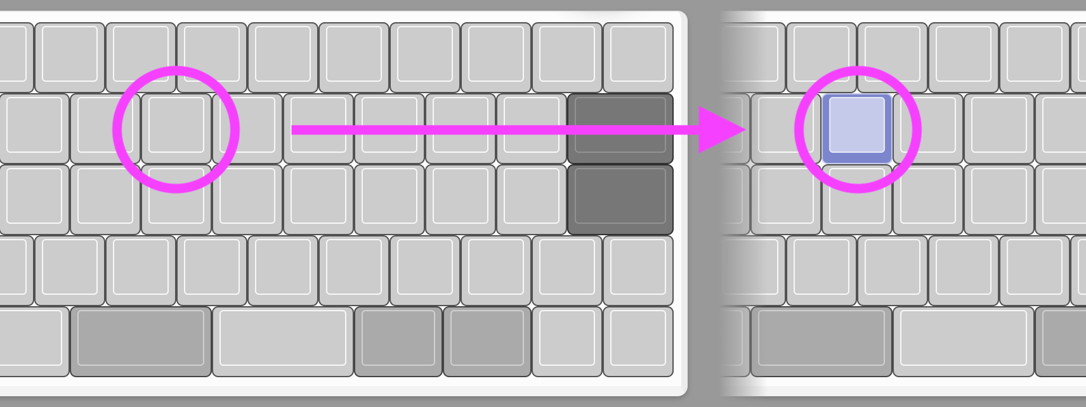
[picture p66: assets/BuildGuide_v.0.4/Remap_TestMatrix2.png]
キーの色が変わる


ソケット用パッドを順にショートさせ、全てのキーの色が変わることを確認します。  
なお、ロータリーエンコーダの回転に割り当てた箇所は、この手順では確認しません。

余裕があれば、すべてのレイアウトでも同様に確認します。

確認が終わったら、USBケーブルを抜きます。

</details>

---

## 組み立て手順

以下の手順に沿って組み立ててください。  
工具類や部品による怪我や、はんだ作業での火傷などに気をつけてください。

### 作りたいレイアウトを決める

Jonesのレイアウトは、大きく分けて次の3つから選ぶことができます。  

- Wide（ワイド）レイアウト  
  右手ホームポジションを右側へずらしてModキーに近づけ、キーボード中央に2キー分の間隔をもたせたレイアウトです。  

- Narrow（ナロー）レイアウト  
  右側Modキーをキーボード中央側へずらし、ホームポジションに近づけたレイアウトです。  

- Normal（ノーマル）レイアウト  
  一般的な英語配列や日本語配列とほぼ同じになるように調整したレイアウトです。

いずれのレイアウトも、一般的な日本語108や英語104のキーキャップセットで組み立てられます。  
Narrowレイアウトを隙間なく埋める場合は、カスタムキーキャップセットが必要です。  

レイアウトをまとめた[Keyboard Layout Editor: Jones v.1(042)](http://www.keyboard-layout-editor.com/#/gists/53fab8cd4a4480980921f37c39e1f5f3)を参考に、どのレイアウトを作るか決めてください。  

### スイッチ用ソケットの取り付け

基板裏側へソケットを取り付けます。

#### 取り付け位置の確認

使用するレイアウトに合わせて、基板裏側のソケットの取り付け位置を確認します。  

``` aside
ソケットは、使用するレイアウトの位置だけに取り付けます。
```

<details>
<summary>《詳しい説明》</summary>

基板にはソケットの枠が描かれており、1uよりも大きなキーと、ソケットが重なる箇所に適合キーサイズ（1uや2uなど）が表記されています。  
また、キーサイズの表記の先頭に`N`がついてものは、Narrowレイアウトで使用するキーを意味しています。  
これらの表記を参考に取り付け位置を確認します。  

わかりにくいときは、実際にスイッチやキーキャップを置いてみるとよいでしょう。  

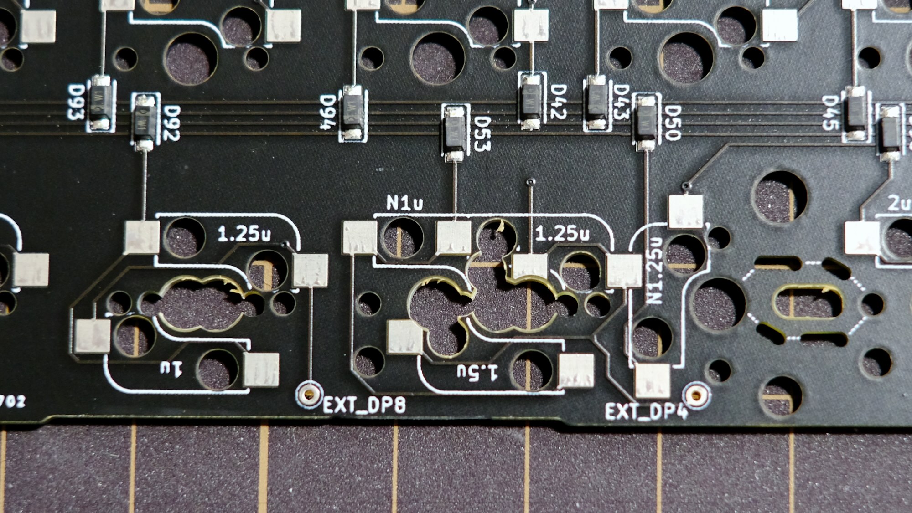
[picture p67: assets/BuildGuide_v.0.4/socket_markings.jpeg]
ソケット取り付け位置の表記

ソケット取り付け位置の表記
</details>

#### ソケット用パッドの予備はんだ

先ほど確認したソケット用パッドの*片方だけ*に、予備はんだ（はんだをちょっとつけておく）します。

<details>
<summary>《詳しい説明》</summary>

はんだごてを320℃程度に設定します。

利き手にはんだごて、もう一方の手にはんだを持ちます。

パッドにこて先をあてて、1、2と数えて加熱します。

こて先にはんだをあてて溶かし、  
溶けたはんだがパッド全体に広がったらはんだを離し、  
続いてこて先をパッドから離します。

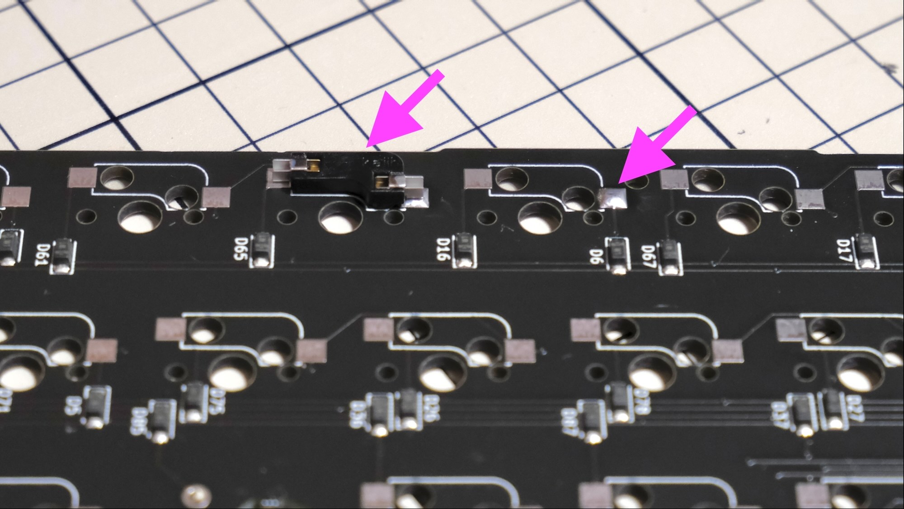
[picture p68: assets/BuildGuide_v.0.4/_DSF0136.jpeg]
ソケット用パッドへの予備はんだ

左：仮置きしたソケット  
右：ソケット用パッドへの予備はんだ  

</details>

#### ソケットの仮置き

ソケットを基板に描かれた枠に合わせ、プラスチックの突起が穴にはまるように仮置きします。

```aside
基板の製造ロットによっては、一部の穴が小さい（狭い）ことがあります。
プラスチックの突起を穴に合わせ、ソケットを指で押してはめ込んでください。
```

<details>
<summary>《詳しい説明》</summary>

この段階では、ソケットの片方の端子が予備はんだの上に乗り、基板から少し浮いて傾いた状態になります。

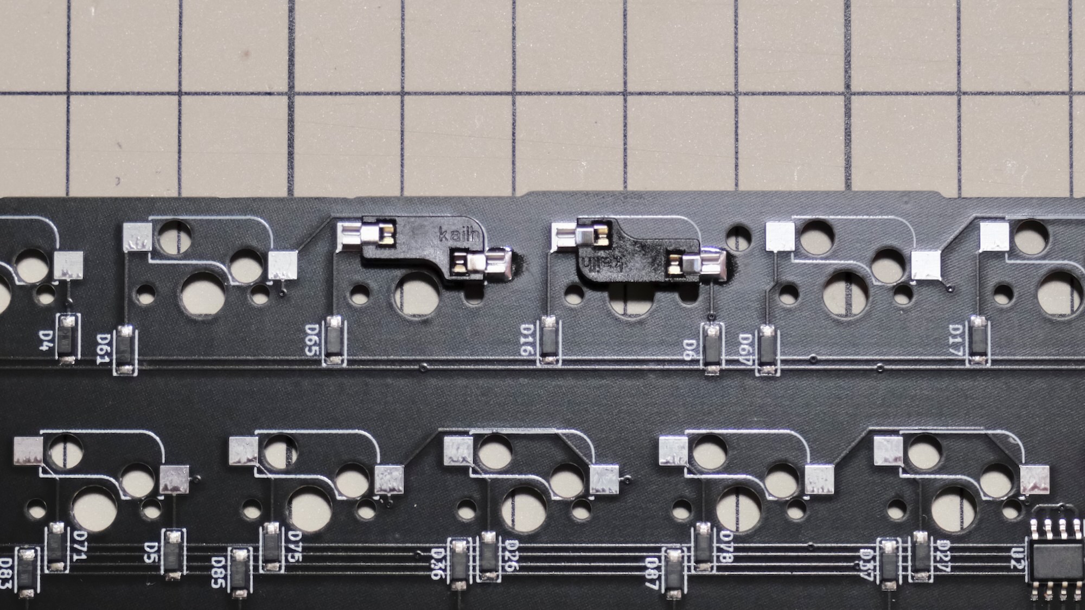
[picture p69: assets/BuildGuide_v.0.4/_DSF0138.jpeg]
ソケットの方向

左：正しいソケットの方向  
右：間違い（スイッチ中央の穴をふさいでいる）

</details>

#### 予備はんだした端子のはんだ付け

予備はんだした端子をはんだ付けします。

<details>
<summary>《詳しい説明》</summary>

はんだごてを320℃程度に設定します。

利き手にはんだごて、もう一方の手にピンセットを持ちます。

ピンセットでソケット中央のプラ部分を押さえ、端子の隙間にこて先を押し込みます。

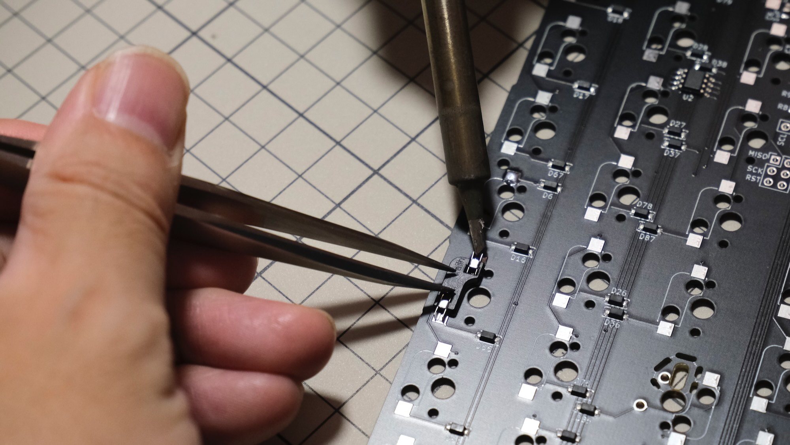
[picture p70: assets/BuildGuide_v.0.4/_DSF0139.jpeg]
金属部分へコテ先を押し込む

金属部分へコテ先を押し込む

1、2と数えたくらいで予備はんだが溶け始めます。  
ソケットを押さえていたピンセットを軽く押し込むと、ソケットのプラスチックの突起が基板の穴にはまり、浮いていた端子が基板に接します。

端子とパッドをしっかりと加熱するため、端子が基板に接してから、1、2と数えてこて先を離します。  
さらに1、2と数えて、はんだが冷えて固まるのを待ってから、ソケットを押さえていたピンセットを離します。

ソケットが枠に沿ってまっすぐに取り付けられ、傾いていないことを確認します。  
傾いている場合は端子部分を再加熱し、こて先とピンセットで傾きを修正します。
</details>

#### 残りの端子のはんだ付け

残りのもう一方の端子をはんだ付けします。

<details>
<summary>《詳しい説明》</summary>

利き手にはんだごて、もう一方の手にはんだを持ちます。

残りの端子の隙間にこて先を押し込み、1、2と数えて加熱します。

次の手順を、1、2、3、4と数える間におこないます。

1、基板のパッドと端子の隙間あたりへはんだを押しつけます。  
2、はんだを溶かしながら隙間へ流し込みます。  
3、溶けたはんだがパッド全体に広がる程度まで流し込んだら、はんだを離します。  
4、ソケットを動かしてしまわないよう、静かにこて先を離します。

はんだがパッド全体に広がり、端子の間にポコっと盛り上がって固まっているのが良好な状態です。

ソケットが枠に沿ってまっすぐに取り付けられていることを確認します。  
また、ソケットのプラスチックの突起が基板の穴にぴったりとはまり、基板から浮いていないことを確認します。  

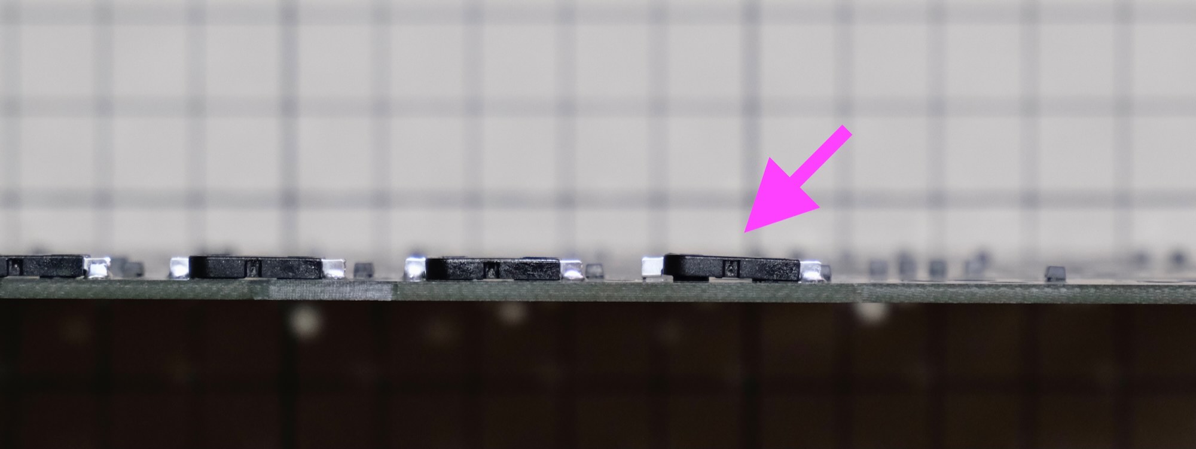
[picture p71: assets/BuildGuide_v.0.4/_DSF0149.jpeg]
浮いたソケット

右端：基板から浮いているソケット
</details>

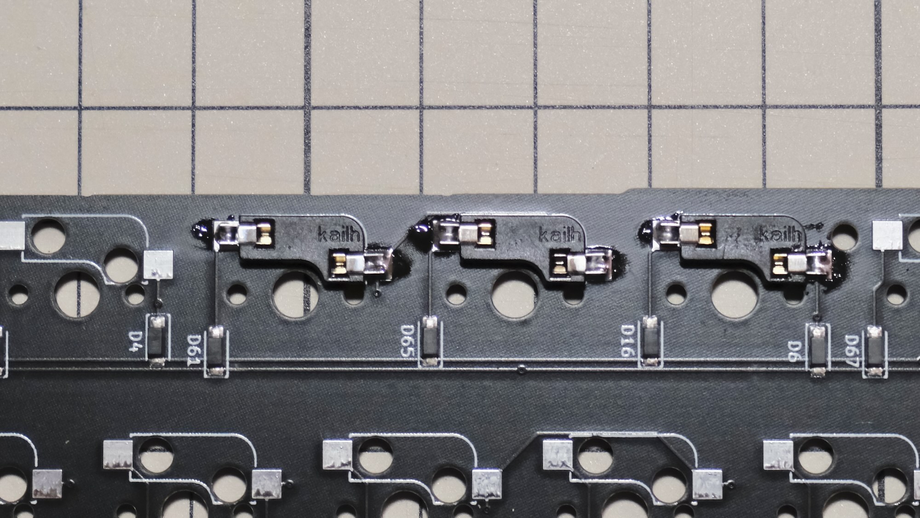
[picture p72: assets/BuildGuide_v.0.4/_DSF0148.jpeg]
取り付けたソケット

取り付けたソケット

#### すべてのソケットの取り付け

作業を繰り返して、すべてのソケットを取り付けます。

取り付けが終わったら、**はんだ付けし忘れた箇所がないか、しっかりと確認します**。  

```aside
特に”残りの端子のはんだ付け”を忘れることがよくあります。
スイッチを取り付けたあとに確認作業をおこないますが、面倒を避けるため、この段階でよく確認しておきます。
```

### （オプション）インジケータLEDの取り付け

*インジケータLEDを使用しない場合、この手順は不要です。*

<details>
<summary>インジケータLEDの取り付け</summary>

#### インジケータLEDの組み合わせとジャンパの設定

インジケータLEDを使用しない場合も含め、4通りの組み合わせがあります。  

| 組み合わせ | 左側<br>LED1, 2 | 右側<br>LED3, 4 | ジャンパ<br>Left LEDs | ジャンパ<br>Right LEDs |
| :--: | :--: | :--: | :--: | :--: |
| 未使用 | なし | なし | 不要 または Off | 不要 または Off |
| 左側のみ | あり | なし | On | 不要 または Off |
| 右側のみ | なし | あり | Off | On |
| 左右両方 | あり | あり | On | On |

#### ジャンパをおこなう

基板裏側のジャンパ`Right LEDs`と`Left LEDs`を、インジケータLEDの組み合わせに応じて`On`または`Off`にジャンパ（隣同士のパッドにはんだをつけてつなげる）します。  
`不要 または Off`となっている箇所は、ジャンパしなくてもかまいません。

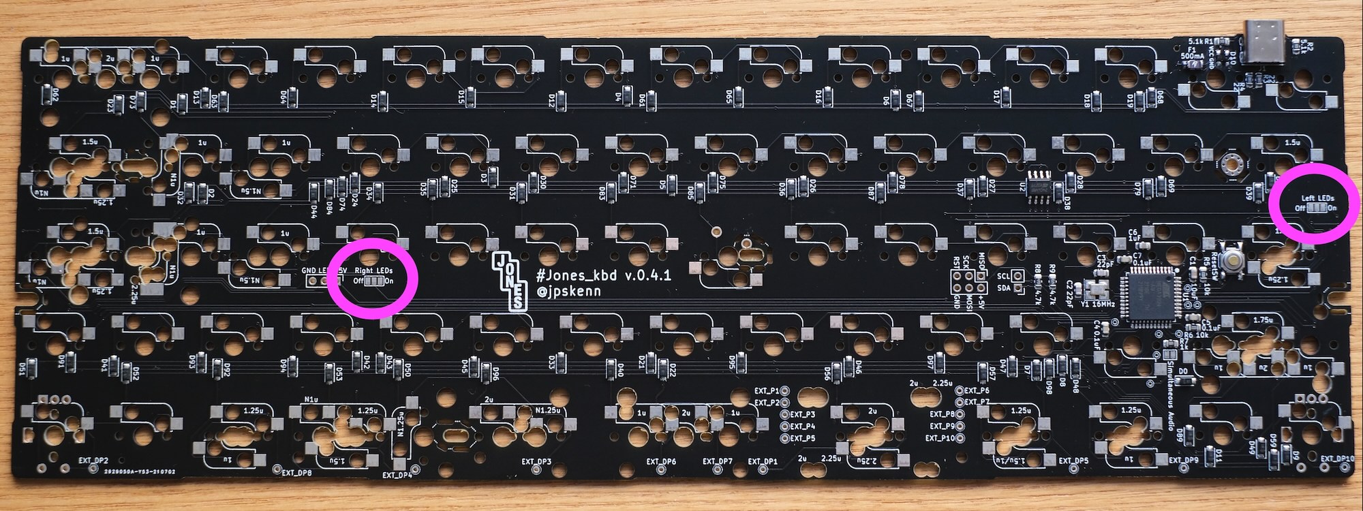
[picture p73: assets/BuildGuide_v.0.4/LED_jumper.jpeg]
LEDジャンパ箇所

LEDジャンパ箇所

<details>
<summary>《詳しい説明》</summary>

3個あるパッドのうち、中央と`On`の2個、または中央と`Off`の2個を同時に温め、  
こて先にはんだを押し付けて、たっぷり目に溶かし、  
こて先を、基板をなでるようにスッと横へずらしてパッドから離し、2個のパッドをはんだでつなげます。

最初のうちはうまくつなげられないことが多いですが、はんだをチョンチョンとつけたりしていると、そのうちつながります。  
はんだをつけすぎて、3個あるパッドがすべてつながってしまわないように気をつけてください。
また、パッドをこて先でグリグリいじりすぎると基板から剥がてしまうため、こて先はパッドにそっと乗せて温めて、スッと横へずらすだけにしてください。
</details>

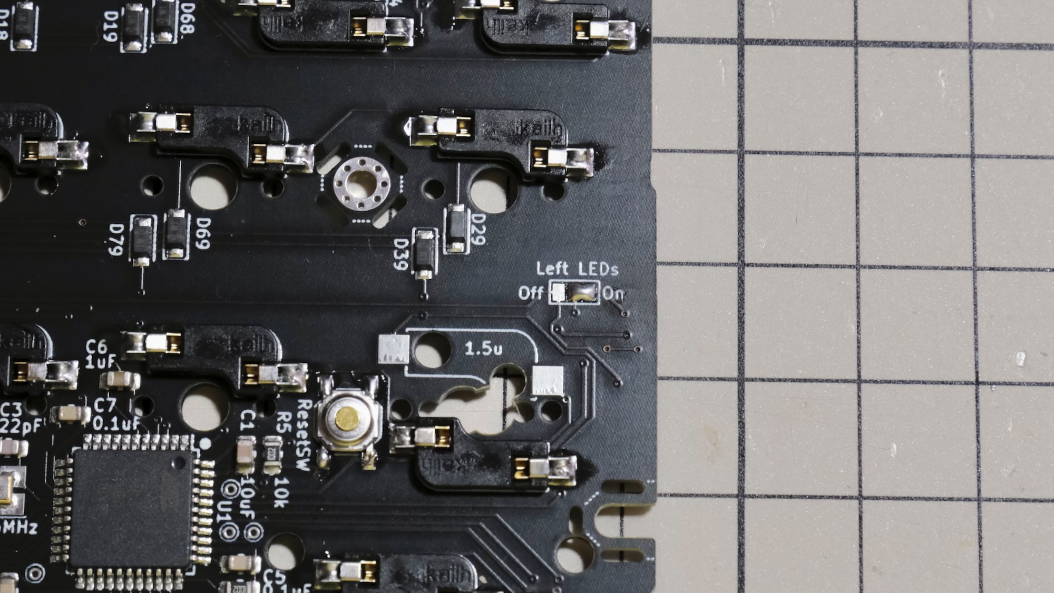
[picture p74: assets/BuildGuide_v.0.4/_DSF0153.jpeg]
Left LEDsをOnにジャンパ

Left LEDsをOnにジャンパした例

#### LED用パッドの予備はんだ

基板おもて側から、インジケータLEDの組み合わせに応じたLEDの取り付け場所へ予備はんだします。

<details>
<summary>《詳しい説明》</summary>

LED1個につき4箇所のパッドがあり、そのうち*1箇所だけ*に予備はんだします。  
スイッチソケット用のパッドに比べてLEDのパッドはとても小さいため、はんだをつけすぎないようにします。

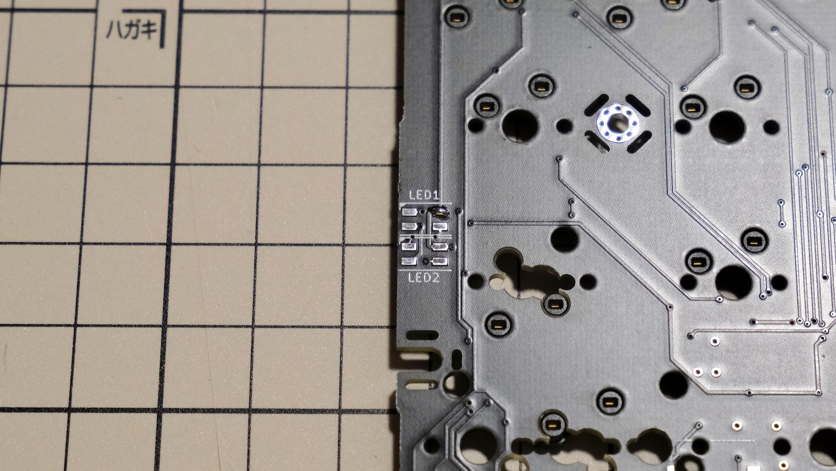
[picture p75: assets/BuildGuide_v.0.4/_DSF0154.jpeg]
LED用パッドの予備はんだ

LED1のLED用パッド4箇所のうち、右上へ予備はんだした状態

</details>

#### LEDの仮固定

予備はんだした箇所へ。LEDを仮固定します。

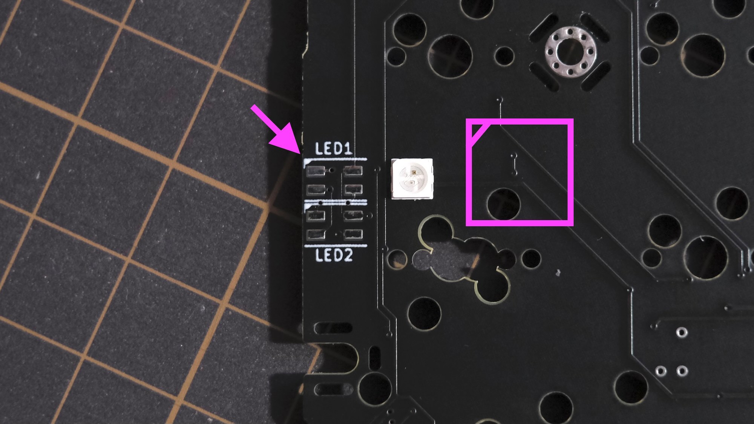
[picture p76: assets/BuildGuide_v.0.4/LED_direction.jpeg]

LED取り付け方向。基板に描かれた▲マークと、LEDの方向、

<details>
<summary>《詳しい説明》</summary>

LEDの1箇所だけ欠けた角が、基板に描かれた▲マークに合うように、LEDを基板に置きます。  
この段階では、LEDが予備はんだした箇所に乗り、基板から少し浮いています。

LEDは高温ではんだ付けすると壊れるため、こて先温度を220-270℃に設定します。  
220℃の方が安心ですが、加熱不足によるはんだ不良（表面上ははんだ付けされたように見えるが、内部はしっかりとくっついていない状態）になりやすいので注意してください。  
[加熱不足による、はんだ不良の例](https://twitter.com/jpskenn/status/1291328876283478016)

フラックスを予備はんだに塗っておくと、作業しやすくなります。

ピンセットでLEDをつまみ、位置がずれないように保持します。

はんだごてのこて先を、LEDの横方向からパッドとLEDの端子にあてて、予備はんだを溶かします。  
こて先温度を220℃に設定したときは、はんだが溶けるまでに少し時間がかかります。

予備はんだが溶けたら、LEDが設置位置の中心になるように微調整し、1、2と数えてこて先を離します。  
さらに1、2と数えて、はんだが固まったらLEDをつまんでいたピンセットを離します。  

はんだが、直径0.5-1mmくらいの小さな球のようになっていれば良い仕上がりです。

LEDの取り付け位置が大きくずれていたり基板から浮いている場合は、はんだ付けした箇所を再加熱し、ピンセットで修正します。  
再加熱する際も、フラックスを塗っておくと作業がしやすくなります。

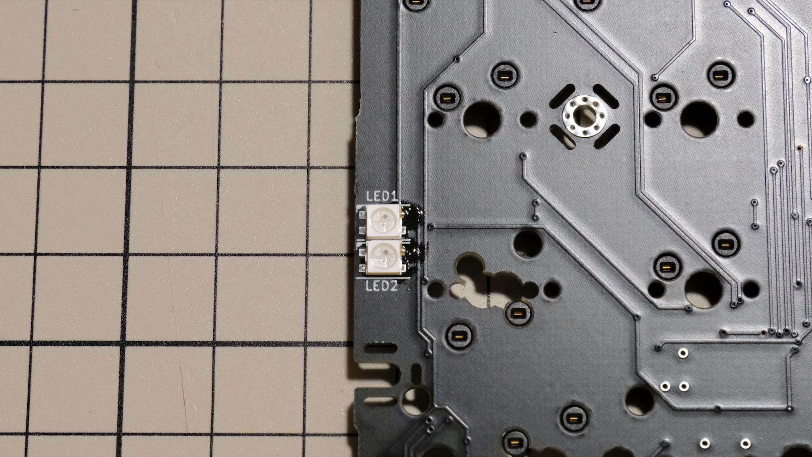
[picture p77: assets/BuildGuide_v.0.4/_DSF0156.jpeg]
仮固定したLED

仮固定したLED
</details>

#### LEDの取り付け

残り3箇所のパッドをはんだ付けし、LEDを取り付けます。

<details>
<summary>《詳しい説明》</summary>

次の順番で残り3箇所のパッドをはんだ付けします。

1. 予備はんだしたパッドとLEDの発光部を挟んだ反対側のパッド

1. 1の隣のパッド

1. 残ったパッド（予備はんだしたパッドの隣）

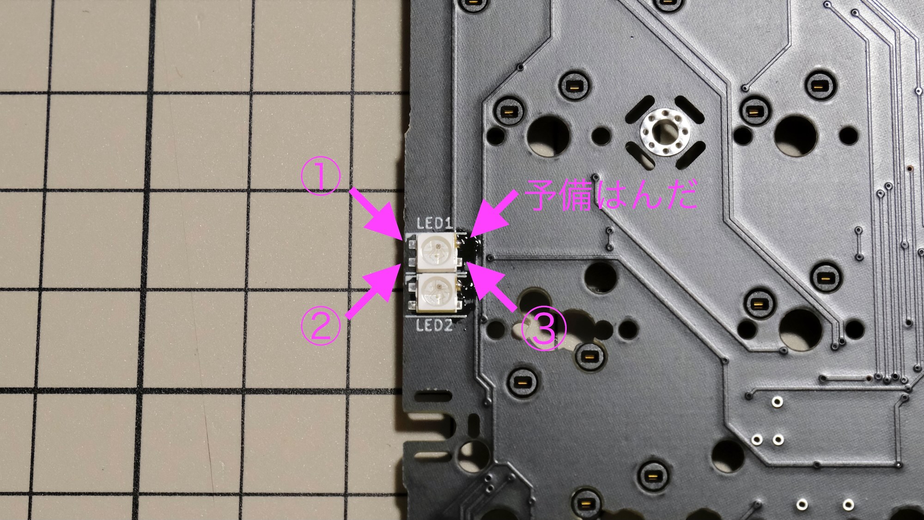
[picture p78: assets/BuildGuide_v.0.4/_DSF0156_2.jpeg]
残り3箇所の、はんだ付け順序

残り3箇所の、はんだ付け順序

フラックスを残り3箇所のパッドに塗っておくと、作業しやすくなります。

はんだをこて先にあてて溶かし、少量のはんだをこて先につけます（乗せます）。

こて先をパッドとLED側面の端子に軽く押しあて、こて先につけておいたはんだをパッドと端子にもつけます。  
押し当てるだけではんだがつくので、こて先は動かしません。

1、2と数えてこて先を離します。
</details>

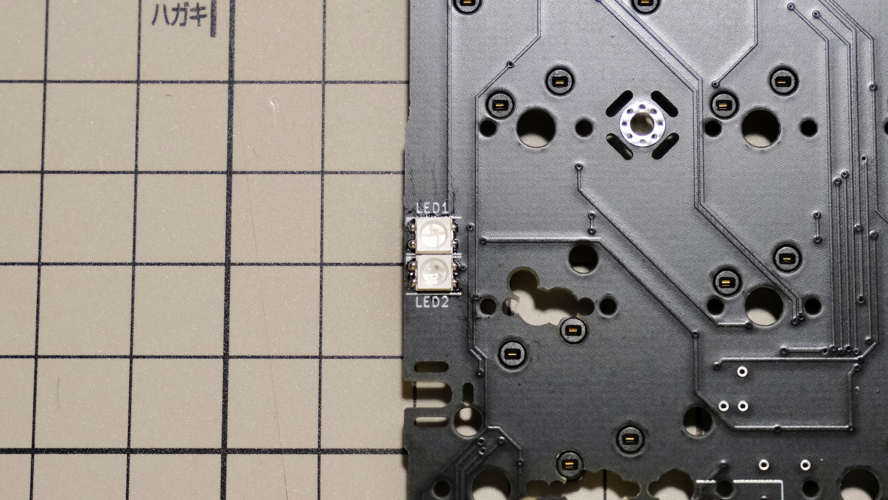
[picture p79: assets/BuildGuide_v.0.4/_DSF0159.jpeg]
取り付けたLED

取り付けたLED

作業を繰り返し、必要な数のLEDを取り付けます。

#### LEDの動作確認

LEDの動作確認のため、次の3箇所へ一時的にスイッチを取り付けます。  

- `左シフト`キー（むらさき）
- `左スペース`キー（みどり）
- `右スペース`キー（あお）

レイアウトによって取り付ける位置が少し変わるため、図を参考に取り付けてください。

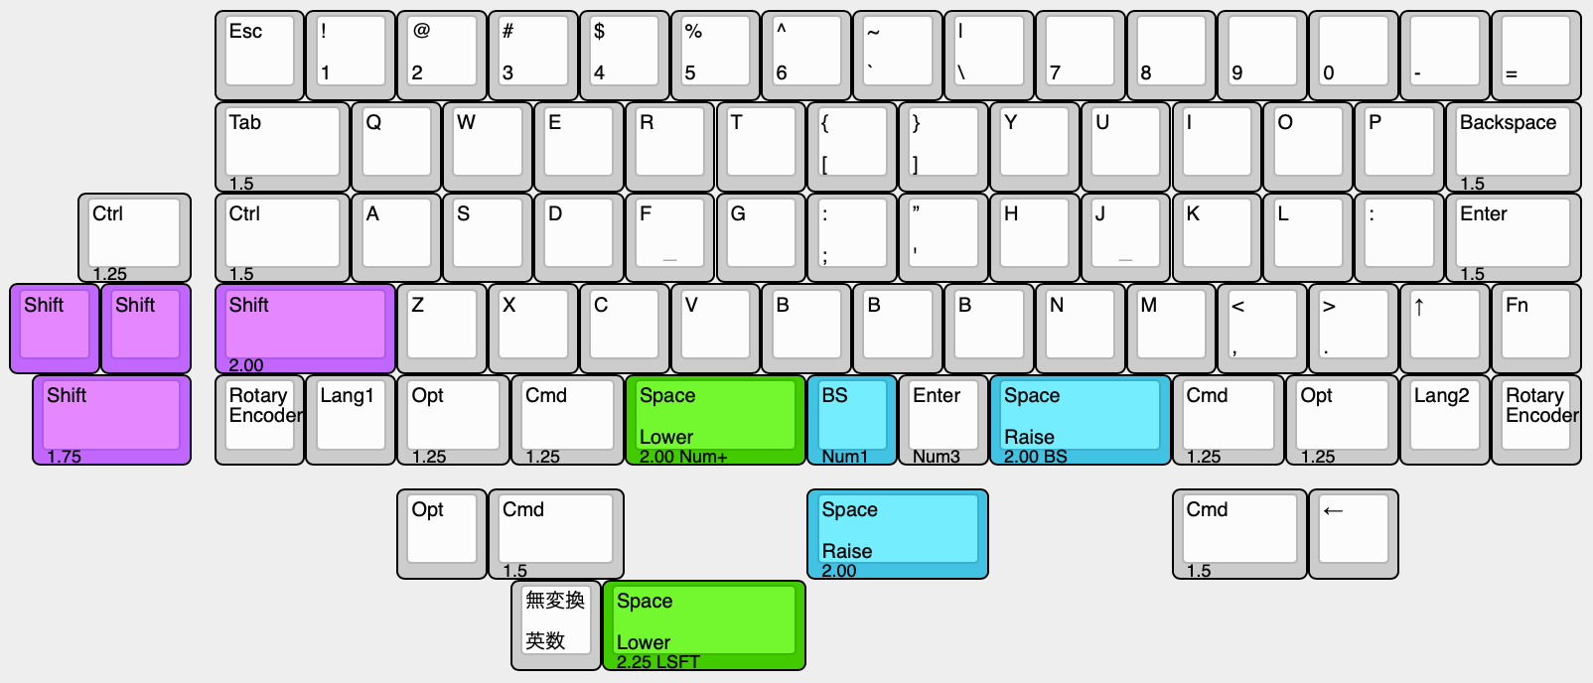
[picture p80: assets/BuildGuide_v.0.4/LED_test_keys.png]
LEDテスト用スイッチ取り付け箇所

LEDテスト用スイッチ取り付け箇所

3箇所に取り付けたスイッチ
3箇所に取り付けたスイッチの例（Wideレイアウト：左シフト2u, 左スペース2.25u, 右スペース2u）

USBケーブルを接続します。

以下のように、スイッチの状態に応じてLEDが点灯することを確認します。  
LEDを左右両方に取り付けている場合も、左側と右側で同じ光り方になります。

| スイッチの状態 | LEDの点灯<br>手前, 奥 | 備考 |
| :-- | :--: | :-- |
| 何も押さない | 白, 白 | |
| `左スペース`を押し続ける | 白, 緑 | |
| `右スペース`を押し続ける | 白, 水 | |
| `左スペース`と`右スペース`を押し続ける | 白, 赤 | |
| `左スペース`と`右スペース`を押しながら`左シフト`を押し、<br>すべてのスイッチから手を離す | 紫, 白 | 操作するたびに”白, 白”と”紫, 白”が切り替わる。|

確認が終わったら、USBケーブルを抜き、スイッチを取り外します。

光らないLEDがある場合は、[トラブル対応：LEDの取り付け不良調査](#トラブル対応LEDの取り付け不良調査)を参考にして調査します。

#### LEDディフューザーの取り付け

*ディフューザーを使用しない場合、この作業は不要です。*

キープレートのLED窓部分にプラ板をディフューザーとして取り付け、LEDの視認性を向上させることができます。

<details>
<summary>《詳しい説明》</summary>

```aside
この手順ではLED窓部分へ取り付けていますが、
ケースへ取り付けた後にネジを隠すように取り付けたりすると、仕上がりが良くなります。
```

LED窓部分
LED窓部分

LED窓の大きさに合わせて、プラ板を切り取ります。  
キープレートへ貼り付けるための、のりしろを残した大きさにします。

切り取ったプラ板
切り取ったプラ板

両面テープなどでキープレートへ貼り付けます。

</details>

プラ板貼り付け前・後
プラ板貼り付け前・後

</details>

### （オプション）スピーカーの取り付け

*スピーカーを使用しない場合、この作業は不要です。*  
*なお、スピーカーは、左シフトキーが1.75uまたは2uの場合にのみ取り付けることができます。*

<details>
<summary>スピーカーの取り付け</summary>

実験的ですが、1スピーカーで2音同時再生する機能を有効にしたい方は以下を参考にしてください。

- [機能追加：1個のスピーカーで2音同時再生する方法](#機能追加1個のスピーカーで2音同時再生する方法)

#### スピーカーの取り付け

基板おもて側、`Speaker`と書かれた枠内へスピーカーを取り付けます。

このスピーカーの端子に極性はないため、どちらの方向に置いてもかまいません。  
スピーカー上面の小さな穴が左方向になるように取り付けると、キープレートの枠から音が抜けて聞こえやすくなります。

<details>
<summary>《詳しい説明》</summary>

スピーカー取り付け箇所
スピーカー取り付け箇所

2箇所のパッドうち、1箇所だけに予備はんだします。

スピーカーを枠とパッドに合わせて置きます。

予備はんだした箇所の端子をはんだ付けします

スピーカーが枠に沿ってまっすぐに取り付けられていることを確認します。

残りの1箇所をはんだ付けします。
</details>

取り付けたスピーカー
取り付けたスピーカー

#### スピーカーの動作確認

USBケーブルで接続した際、`♪ピッ`という音が聞こえることを確認します。

確認が終わったら、USBケーブルを抜きます。

音が聞こえない場合は、スピーカーが正しくはんだ付けされているか確認します。

</details>

### （オプション）ロータリーエンコーダの取り付け

*ロータリーエンコーダを使用しない場合、この作業は不要です。*

<details>
<summary>ロータリーエンコーダの取り付け</summary>

#### ロータリーエンコーダの取り付け

基板おもて側の右下と左下のどちらか一方、または両方へロータリーエンコーダを取り付けます。  

```aside
ノブ（つまみ）は、キープレートと基板を組み合わせた後に取り付けます。
```

<details>
<summary>《詳しい説明》</summary>

ロータリーエンコーダ取り付け箇所
ロータリーエンコーダ取り付け箇所

対応するロータリーエンコーダは、ALPS EC11, ALPS EC12とその互換品です。  
取り付け確認済みのロータリーエンコーダは次の通りです。

- ALPS
  - EC11E09244AQ
  - EC11E153440D
  - EC11E18244AU
  - EC12E24204A2
- Bourns
  - PEC11R-4315F-S0012
  - PEC11R-4015F-S0024

ロータリーエンコーダのピン（上3本または上下5本）と、左右の固定足を、基板の設置位置に合わせて差し込みます。  
固定足が差し込みにくいときは、足を横から少し押さえ、先端を基板の穴に入れます。  

左右の固定足である程度しっかりと基板に固定されるはずですが、固定がゆるく、基板から外れたり浮いたりする場合はマスキングテープなどで仮固定します。

基板を裏側が上になるように置き、いずれかのピンを*1本だけ*はんだ付けします。

ロータリーエンコーダが基板に描かれた枠に沿ってまっすぐ取り付けられていることを確認します。

ロータリーエンコーダが基板から浮かないように気をつけながら、残りのピンをはんだ付けします。
</details>

取り付けたロータリーエンコーダ（基板おもて側）
取り付けたロータリーエンコーダ（基板おもて側）

取り付けたロータリーエンコーダ（基板裏側）
取り付けたロータリーエンコーダ（基板裏側）

#### ロータリーエンコーダの動作確認

USBケーブルを接続し、ロータリーエンコーダのつまみを左右に回すとOSの音声出力ボリュームが変化することを確認します。  
また、プッシュボタンスイッチ付きのロータリーエンコーダでは、Remapのテスト機能を使って確認します。

何か問題があった場合は、正しくはんだ付けされているかを確認してください。

</details>

### スタビライザーの取り付け

基板おもて側に必要な数のスタビライザーを取り付けます。

#### スタビライザーの取り付け位置の確認

使用するレイアウトに合わせて、基板おもて側のスタビライザー取り付け位置を確認します。  
なお、左シフトキーの2uスタビライザーは、ケースネジに干渉するため使用を避けてください。

スタビライザー取り付け箇所
スタビライザー取り付け箇所（左下は2uキーと2.25uキーがほぼ同じ位置に並ぶ）

#### スタビライザーの組み立て

必要な数のスタビライザーを組み立てます。

<details>
<summary>《詳しい説明》</summary>

次のようにスタビライザーを組み立てます。  

大きいプラパーツの下側から、小さいプラパーツの切り欠きの位置を合わせて差し込みます。  

金属の棒の先を、大きいプラパーツの穴を通して、小さいプラパーツの溝へ差し込みます。  

金属の棒を、プラ部分の爪へパチンとはめ込みます。  

反対側も同じ方法で組み立てます。

../assets/BuildGuide_ v.0.4/Stab_assemble.jpeg
スタビライザーの組み立て（[拡大](../assets/BuildGuide_v.0.4/Stab_assemble.jpeg)）

</details>

#### スタビライザーの基板への取り付け

基板おもて側から、スタビライザーを取り付けます。

<details>
<summary>《詳しい説明》</summary>

スタビライザーの棒がある方の突起部分を、大きい方の穴に斜めに差し込んで引っ掛けます。  
スペースキーとそれ以外のキーのスタビライザーは、上下を逆向きに取り付けるため注意してください。

大きい方の穴に引っ掛けたスタビライザー
大きい方の穴に引っ掛けたスタビライザー

スタビライザーの反対側のねじ止めする部分を、小さい方の穴にはめ込んでねじ止めします。

ねじ止めしたスタビライザー
ねじ止めしたスタビライザー
</details>

取り付けたスタビライザー
取り付けたスタビライザー

### スイッチの取り付け

スイッチを、キープレートをはさむようにして基板に取り付けます。

打鍵感向上に興味のある方は、次の項目をお読みになると何かヒントがあるかもしれません。

- [打鍵感向上：キープレートと基板間のパテ埋め](#打鍵感向上：キープレートと基板間のパテ埋め)

#### スイッチ取り付け前の確認

スイッチの端子を見て、折れたり、曲がったりしていないことを確認します。  
少しだけ曲がっているものは、まっすぐに戻します。

<details>
<summary>《詳しい説明》</summary>

スイッチの端子
スイッチの端子（左から順に、曲がり、正常、曲がり）

折れてしまっているものは使用できません。  
また、大きく曲がっているものは、まっすぐに戻しても折れやすくなっているため、使用を避けた方がよいでしょう。

</details>

#### キープレートの仮固定

キープレートの4隅に仮固定用のスイッチをはめ込んでから、基板へ取り付けます。  

```aside
スイッチの取り付け方向に注意します。
左上のキーは、他との3個とは上下が逆向きです。
```

```aside
キープレートを取り付けた後は、以下の基板おもて側の部品の取り付け・取り外しができなくなります。
基板おもて側の部品：インジケータLED，スピーカー，ロータリーエンコーダ，スタビライザー

キープレートを取り外すのが面倒なため、部品の取り付け忘れがないか確認しておきます。
```

<details>
<summary>《詳しい説明》</summary>

キープレートをおもて側が上になるように置きます。

使用するレイアウトに合わせ、キープレートの4隅にスイッチをはめ込みます。  
ロータリーエンコーダを取り付けている場合は、その隣へはめ込みます。

スイッチの取り付け方向がソケットの方向に合うようにしてください。  
例えば、左上のキーは上下逆向きにはめ込みます。

キープレート4隅につけたスイッチ
キープレート4隅につけたスイッチ

スイッチがキープレートの枠にぴったり密着してはまっていることを確認します。

スイッチのキープレートへのはまり具合（異常）
スイッチのキープレートへのはまり具合（異常）

スイッチのキープレートへのはまり具合（正常）
スイッチのキープレートへのはまり具合（正常）

基板を表側が上になるように置きます。

4隅にスイッチをはめ込んだプレートを基板に乗せ、スイッチの端子とソケットの位置を合わせます。
スタビライザーを取り付けているときは、キープレートの枠にはまるように位置を調整します。

キープレートの枠にはまったスタビライザー
キープレートの枠にはまったスタビライザー（Wideレイアウトの例）

4隅のスイッチを、1個ずつ基板のソケットに押し込んでいきます。  
スイッチの端子が奥まで差し込めるように、基板裏側のソケットを押さえながら、少しだけ力を入れてスイッチを押し込みます。  

```aside
洗濯バサミをつまんで開くよりも、もう少しだけ強い力で押し込みます。
それで押し込めないときは、スイッチの方向が間違っていたり、スイッチが斜めになっていたりしないか確認します。
```

スイッチを押し込む様子
スイッチを押し込む様子
</details>

キープレートを基板に仮固定
キープレートを基板に仮固定

#### （該当者のみ）ケースネジ穴に干渉するスッチの取り付け

*GH60型, Poker型ケースを使用しない場合、この手順は不要です。*

GH60型, Poker型ケースのネジ穴とスイッチ足の干渉を避けるため、スイッチの足を加工して取り付ける箇所があります。  

<details>
<summary>《詳しい説明》</summary>


スイッチの足を加工して取り付ける箇所

##### 中央ネジ穴に重なるスイッチ

すべてのレイアウトにおいて、中央ネジ穴に重なるスイッチは、スイッチの足を加工して取り付けます。

5pinスイッチは、中央ネジ穴と干渉する片方の足を、ニッパーなどで切断して取り付けます。  

3pinスイッチは干渉しないため、そのまま取り付けることができます。


5pinスイッチの片方の足を切断

##### 右上ネジ穴に重なるスイッチ

Narrowレイアウトを使用する場合のみ、右上ネジ穴に重なるスイッチの足を加工して取り付けます。

ケースによってネジ穴サイズの大小が異なりスイッチとの干渉具合が変わってくるため、現物合わせで干渉具合を確認します。

5pinスイッチ、3pinスイッチのいずれも、スイッチ中央の足（出っ張り）を、ネジ穴に当たらない程度に一部切断して取り付けます。  
中央の足をすべて切断するとスイッチ固定の安定性が下がるため、1/4〜1/3に切り込みを入れて一部だけ切断する方がおすすめです。


中央の足の1/4くらいに切り込みを入れてカットしたスイッチ

なお、押下時にスイッチの軸がネジに当たる場合は、軸の下端を切断したりして調整します。

軸の下端を切断
軸の下端を切断（上：切断後, 下：切断前）

</details>

#### 残りのスイッチの取り付け

スイッチの取り付け方向をソケットの方向に合わせて、残りのスイッチを取り付けます。

ロータリーエンコーダを使用する場合は、ノブ（つまみ）を取り付けます。

<details>
<summary>《詳しい説明》</summary>

スイッチの端子が曲がらないよう、真上からまっすぐに押し込みます。  
押し込む際に変な抵抗を感じたり、奥までスッと刺さらないときは、スイッチを一旦取り外し、端子が曲がっていないか確認してやり直します。

差し込み時に端子が曲がったスイッチ
差し込み時に端子が曲がったスイッチ

取り付けたら、スイッチがキープレートの枠にぴったりとはまっていることを確認します。  
スイッチがキープレートから浮いているような場合は、プレートを指で引っ張り、スイッチと密着させます。
</details>

スイッチをすべて取り付けた状態
スイッチを全て取り付けた状態  
（赤いペイントは、スイッチの足を切断したことがわかるようにつけた印で、特に意味はありません）

#### スイッチの動作確認

組み立て前におこなった[ソケット用パッドの確認](#ソケット用パッドの確認)と同様に、動作確認をおこないます。  
以前はピンセットでソケット用パッドをショートさせましたが、この手順ではスイッチを押して正しく反応することを確認します。

正常に入力できないスイッチがあった場合は、[トラブル対応：正常に入力できないスイッチの原因調査](#トラブル対応正常に入力できないスイッチの原因調査)の手順に沿って調査します。

### ケースへの取り付け

#### （該当者のみ）Jones用ボトムプレートキットの取り付け

*Jones用ボトムプレートキットを使用しない場合、この手順は不要です。*

ネジとスペーサーを使い、基板にボトムプレートを取り付けます。

<details>
<summary>《詳しい説明》</summary>

ボトムプレート裏面から、○印をつけた8箇所に、ネジ（M2 3mm）を使い、スペーサー（M2 3mm）をねじ止めします。  
右下の点線の○印は、キースイッチでネジ穴がふさがるため、WideレイアウトとNarrow, Normalレイアウトでねじ止め位置が異なります。

なお、GH60型, Poker型ケース取り付け用の、中央と中央右下のネジ穴はねじ止めしません。

スペーサー取り付け箇所
スペーサー取り付け箇所

基板を、ボトムプレートのスペーサーの位置にネジ穴の位置が合うように乗せます。  
基板裏側の部品やソケットが、スペーサーにぶつからないように気をつけてください。

基板おもて側から、ネジ（M2 3mm）を使ってねじ止めします。  
Narrowレイアウトの場合は、スイッチとの干渉を避けるため、右上のネジ穴にネジ（M2 3mm 低頭）を使用します。

```aside
せまくてネジが取り付けにくい場合は、
ネジ穴まわりのスイッチを取り外すと作業しやすくなります。
```

低頭ネジの取り付け箇所
低頭ネジの取り付け箇所

基板とボトムプレートをねじ止めした状態
基板とボトムプレートをねじ止めした状態

取り外していたスイッチを取り付けます。

ボトムプレート底面に、滑り止めのゴム足を貼り付けます。  

- キーボードに傾斜をつける場合
    奥の左・右の2箇所：ゴム足 大
    手前の左・中・右の3箇所：ゴム足 小

- キーボードをフラットにする場合
    手前と奥の左・中・右の6箇所：ゴム足 小

ボトムプレート取り付け完了
ボトムプレート取り付け完了

見た目を良くしたい場合は、キープレート, 基板, ボトムプレートの側面を、水性顔料インクのポスターカラーや油性マジックなどを使って塗ります。  
また、キープレートと基板の周りにマスキングテープなどを貼り付けて、見た目の印象を変えることもできます。

```aside
キープレートから基板までの厚さは6.6ｍｍです。
6mm幅のマスキングテープがちょうど良いサイズです。
```

側面の加工例
側面の加工例（マスキングテープ貼り付けと黒色ペンでの塗り）

</details>

#### （該当者のみ）60% プラスチックケースの加工

*60% プラスチックケースを使用しない場合、この手順は不要です。*

60% プラスチックケースへ取り付ける際は、基板裏側の部品がケース内リブと干渉するため、干渉箇所を切り取る加工を行います。

<details>
<summary>《詳しい説明》</summary>

切り取る箇所は以下の点線で囲んだ部分です。

リブ切り取り箇所
リブ切り取り箇所

写真で示した部分を、ニッパーやカッターなどを使って切り取ります。  
ニッパーで切り取る際は、1-2mmくらいずつ切り進んでください。  
それ以上の長さを一気に切断しようとすると、意図しないところが割れることがあります。

リブ切り取り前
リブ切り取り前

リブ切り取り後
リブ切り取り後

</details>

#### （該当者のみ）GH60型, Poker型ケースへの取り付け

*GH60型, Poker型ケースを使用しない場合は、この手順は不要です。*

ケースに基板をねじ止めして取り付けます。

<details>
<summary>《詳しい説明》</summary>

打鍵感向上に興味のある方は、次の項目をお読みになると何かヒントがあるかもしれません。

- [打鍵感向上：ケースへの基板取り付け方法の変更](#打鍵感向上：ケースへの基板取り付け方法の変更)
- [打鍵感向上：ケース内部の制振と静音化](打鍵感向上：ケース内部の制振と静音化)

基板の奥側（USBコネクタ側）からケース内へ入れていきます。

基板の奥側を水平から30度くらいの角度でケースへ差し込むと、USBコネクタがケースの穴にスッとはまります。  
その状態で基板の手前側を静かに下ろして水平にすると、力をかけることなく、基板全体がストンとケースに入ります。  
力を入れてグリグリとこじったり、ググググッと押し込むようなことはせず、角度を合わせて差し込むだけです。

スペーサー取り付け箇所
30度で差し込む

ケースネジ穴と基板のネジ穴の位置を合わせ、ケースに付属しているネジで仮止めします。  
ネジ穴とスイッチがかぶさる箇所は、キット付属の低頭ネジを使用します。  
低頭ネジは、ケースに付属しているネジの長さと同じか、より短いものを使用します。

ケースに対して上下左右の真ん中になるように、基板の位置を調整します。

ネジを締めて基板を固定します。

取り外していたスイッチを取り付けます。

ケース底面に、滑り止めのゴム足を貼り付けます。

</details>

### 仕上げ

キーキャップを取り付けます。

Remapで自分好みのキーマップに変更します。

完成です。

製作例
製作例

写真を撮影し、`#Jones_kbd` のタグをつけてツイートすると設計者が喜んだりします。  
[Twitter: #Jones_kbd](https://twitter.com/search?q=(%23jones_kbd)&src=typed_query&f=live)

完成したところですが、打鍵感の向上やアンダーグロー用LEDテープの使用など、DIYで楽しむ要素はまだまだ残っています。  
[参考](#参考)にいろいろと情報を載せていますので、ご活用ください。

---

## 参考

打鍵感向上や機能追加についてのDIY情報や、トラブル調査方法などの参考資料です。  
必要に応じてお読みください。

### TIPS：キーキャップ

キーキャップ関連のTIPSを紹介します。

<details>
<summary>《詳しい説明》</summary>

#### 2uと2.25uのスペースキー

カスタムキーキャップセットには2uや2.25uのスペースキーが含まれていたり、スペースキーを追加するバリエーションキットが用意されていることがあります。  
しかし、限定販売だったり、なかなかのお値段で手に入れにくいことがあります。

一般的なキーキャップセットには2uや2.25uのスペースキーは含まれていないので、他のキーで代用します。

- 日本語108キー  
  2.25u：左シフトキー  
  2u：テンキーの0（ゼロ），+（プラス），Enter

- 英語104キー  
  2.25u：左シフトキー
  2u：Backspace，テンキーの0（ゼロ），+（プラス），Enter

キーキャップセットとキーのプロファイル（高さや形）が異なりますが、スペースキーだけを購入することもできます。

- G20プロファイル（→[pimp my keyboard](https://pimpmykeyboard.com/g20-2-space-pack-of-4/)）  
  少し背が低く、キー天面が平らな形状です。  
  キーの角がなだらかになっており、指に刺さるような感触がありません。  
  いろいろな色を選べて他のキーキャップセットにも合わせやすいので、おすすめです。  
  （1uブロッカーの項目に写真あり）

- DSA（→[TALP KEYBOARD](https://talpkeyboard.net/items/5f942aa39a06e531a841f76b)）  
  DSAのスペースキーのうち、キー天面がなだらかな凸になったカマボコ状のタイプ。  
  ちょっと背が低いかもしれません。  
  DSAと言えばSPことSignature Plastic、そしてその直販のpimp my keyboardで探すのが筋ですが、カマボコ状のタイプが置いてないようなので…

#### 1uブロッカー

ブロッカーとは、以下の写真のように、キースイッチにふたをしてキーキャップを取り付けないようにするパーツです。  
[pimp my keyboard](https://pimpmykeyboard.com/switch-blocker-pack-of-10/)で販売されています。  
キースイッチにかぶせるように、パチっとはめて使います。

Cherry MXスイッチの形状に合わせて作られているため、トップハウジングの形状が異なるKailh Boxスイッチなどには取り付けできません。  

```aside
ブロッカーを取り付ける箇所だけ、ブロッカー対応の安いGateronスイッチなどを使って取り付けるとよいでしょう。
```

1uブロッカー使用例
1uブロッカーとG20プロファイル2uスペースキーを、CheeryプロファイルのePBT Ivoryキーキャップセットと組み合わせた使用例  

</details>

### 機能追加：アンダーグロー用LEDテープの使用

アンダーグロー対応ファームウェアへ書き換えることで、基板裏側へアンダーグロー用のLEDを取り付けて光らせることができ、クリアや半透明のケースの見栄えが良くなります。

なお、ファームウェアサイズの制限により、Audio機能の”Music Mode”は使用できなくなります。

``` aside
ファームウェアの機能を厳選すれば、アンダーグローと”Music Mode”を同時に使うことも可能です。
```


KBDfans 5° FROSTED ACRYLIC CNC 60% CASEでの使用例

不透明のケースを使用するとLEDの光がほとんど見えないため、取り付けはおすすめしません。  
Jones用ボトムプレートを使用する際は、基板とボトムプレートの間隔が狭いため取り付けることができません。

<details>
<summary>《詳しい説明》</summary>

*ファームウェアの書き換え作業を伴うため、動作不良があった場合に原因調査がしづらいことがあります。*  
*キーボードをいったん完成させ、動作確認が終わってからLEDテープの取り付け作業をおこなうことをおすすめします。*

#### 使用するLEDテープ

使用するLEDテープは、以下のようなタイプです。

- フルカラーシリアルLEDテープ  
  Neopixel WS2812BやRGBテープと表記されていることもあります。

- 幅1cm

- 1mあたり60個のLEDがついたタイプ

このテープを、LED15個分の約25cm使用します。

例えば、[NeoPixel RGB TAPE LED [1907]](https://www.akiba-led.jp/product/959)のような商品がこれに該当します。  
50cm/30LEDのものを買った場合は、真ん中で半分に切り、LED15個分を使用します。

#### LEDテープの取り付け

LEDテープを用意したら、LED信号の入力方向を示す`Din`の文字や、LEDに向かう矢印`→`が描かれている方向を確認します。


LED信号の入力方向を示す`Din`と矢印`→`

LED信号の入力側のテープ裏面の剥離紙を、端子が見える程度（5〜10mm）はがして切り取ります。  
端子が露出するように、シールの糊も取り除きます。


裏側の剥離紙をはがす様子

基板裏側のLEDテープ用パッド`LED STRIP`の、`GND`, `LED`, `VCC`の3箇所へ予備はんだします。

はんだごてを270℃程度に設定します。

LEDテープをマスキングテープなどで仮固定したり、端子付近をピンセットで押さえたりして、基板のパッドとテープ裏側の端子部分が重なるように固定します。  

テープおもて側の端子部分にはんだごてをあてて押さえつけ、パッド上の予備はんだが溶けたらはんだごてを離します。  
はんだごてで端子部分をグリグリいじりすぎると端子が剥がれてしまうため、上から押さえるだけにします。  
`GND`, `LED`, `VCC`の3箇所をはんだ付けします。


テープおもて側からはんだごてをあてて押さえつける様子

ソケットなどとのショートを防ぐため、テープのもう一方の端の端子部分へビニールテープなどを貼ります。

マスキングテープなどを使い、LEDテープを基板に固定します。

``` aside
LEDテープの剥離紙をすべてはがして基板に貼り付けてしまっても良いですが、メンテナンスしにくくなります。
また、はがす際に基板上の部品まではがれてしまったりするかもしれないので、注意が必要です。  
```


LEDテープを取り付けた様子

#### アンダーグロー対応ファームウェアの書き換え

```aside
ファームウェアの書き換えをおこなうと、EEPROMの初期化に伴って、キーマップも初期化されます。
Remapのキーマップ保存／復元機能を使うと、あとで復元することができます。
```

アンダーグロー対応ファームウェアを用意します。  
インジケータLEDの使用数によって、書き込むファームウェアが異なるため、使用環境に合ったものを用意してください。  
間違ったものを書き込んでも壊れることはありませんが、LEDの点灯位置がずれてしまいます。

ビルド済みのHEXファイルは以下のリンクからダウンロードできます。

- [アンダーグロー対応 インジケータLEDなし用](https://gist.github.com/jpskenn/50e3ec1cdb09e1d24a6f2a5ed4cc2e15)

- [アンダーグロー対応 インジケータLED2個（左または右の、どちらか片側のみ）用](https://gist.github.com/jpskenn/5f6d95be0a71697aa9e7e743e40a73b2)

- [アンダーグロー対応 インジケータLED4個（左右両側）用](https://gist.github.com/jpskenn/cc2e155be9b250978d8f289e9917b5cd)

[資料：ファームウェアの書き込み方法](#資料ファームウェアの書き込み方法)を参考に、ファームウェアを書き込みます。  

#### アンダーグローの動作確認とケースへの取り付け

キーボードの起動後、LEDテープのすべてのLEDが赤色に点灯していれば正しく動作しています。  
点灯しない場合は、はんだ付けをやりなおします。


すべてのLEDが赤色に点灯している様子

アンダーグローLED関連のキー割り当て（一部抜粋）
`Raise + Lower + L`: ON/OFF切り替え
`Raise + Lower + P`: 表示モード切り替え
`Raise + Lower + I`: 明るさ増加
`Raise + Lower + K`: 明るさ減少

ケースへ基板を取り付けます。  
60%プラスチックケースと組み合わせたときにケース内のリブがLEDテープと干渉しやすいため、テープを少しずらすか、ケース内のリブをカットして対処します。  
</details>

### 機能追加：1個のスピーカーで2音同時再生する方法

*元々は2個のスピーカーで2音同時再生する機能であり、1個のスピーカーでの再生は**実験的な機能**です。*

QMKのAudio機能で[Music Mode](https://docs.qmk.fm/#/feature_audio?id=music-mode)を使用する際に、1つのスピーカーで2音同時再生させることができます。  
なお、2音同時再生されるのはMusic Modeで演奏する際の音だけで、キーボードの起動音やリセット音などの[Songs](https://docs.qmk.fm/#/feature_audio?id=songs)については、単音再生のままで変わりません。

Playing QMK's simultaneous tones with single speaker. (https://www.youtube.com/watch?v=ZqbNMjGJpUM)
YouTube：2音同時再生デモ動画

ハードウェア的には1箇所ジャンパするだけで機能が有効になりますが、ファームウェアの書き換えが必要となります。

<details>
<summary>《詳しい説明》</summary>

#### 基板のジャンパ

キーボード裏側の`Simultaneous Audio`をジャンパします。

ジャンパ箇所
ジャンパ箇所

#### 2音同時再生対応ファームウェアの書き換え

```aside
ファームウェアの書き換えをおこなうと、EEPROMの初期化に伴って、キーマップも初期化されます。
Remapのキーマップ保存／復元機能を使うと、レイヤー0〜4までは復元することができます。
```

2音同時再生対応ファームウェアを用意します。

ビルド済みのHEXファイルは以下のリンクからダウンロードできます。

- [2音同時再生対応](https://gist.github.com/jpskenn/2a1d57117e745d635d038c64fdb32539)

ファームウェアサイズの制限により、`ベースレイヤー #3`を削除して、使用できるレイヤー数を6から5に減らしています。

[ファームウェアの書き込み方法](#ファームウェアの書き込み方法)を参考に、ファームウェアを書き込みます。  

#### 2音同時再生の確認

キーボード起動後に、`Raise` + `Lower` + `D`を押してMusic ModeをONにします。

`F`と`J`を同時に押して、2音同時再生されていれば正しく動作しています。

</details>

### 打鍵感向上：ケースへの基板取り付け方法の変更

GH60型, Poker型ケースへの基板取り付け方法を変更し、打鍵感の向上を目指すための資料です。  

通常であれば、左2, 右2, 中央1, 中央下1の合計6本のネジで基板をケースに固定しますが、基板を改造して固定方法を変えることで、打鍵感の向上を狙います。

なお、通常の手順で組み立てた後でも、これらの改造をおこなうことができます。

``` aside
60%プラケースはケース内のリブが基板と接しているため、この改造を行なっても、そのままでは打鍵感は向上しません。
ケース内のリブをネジ穴よりも低い高さに切り取る加工を行えば、効果が期待できます。
```

**この加工による基板の破損や、ケースへの取り付け不良などの不具合が発生することが考えられるため、加工者の責任でお楽しみください。**  
**また、改造を行なった基板は元には戻せませんので、それを理解した上でおこなってください。**

#### 方法1：基板中央のフレックス加工

基板の中央付近のネジ穴を切り取り、左右のネジだけでケースに固定することで、基板を適度にしならせて打鍵感を柔らかくする改造です。  

<details>
<summary>《詳しい説明》</summary>

組み立て済みの場合は、切り取り箇所付近のスイッチを取り外します。

基板裏側、中央と中央下のネジ穴
基板裏側、中央と中央下のネジ穴

中央と中央下のネジ穴を、基板裏側に白い点線で描かれた切断ガイドに沿ってニッパーなどを使って切り離します。  
まわりの部品を傷つけないように注意しながら、一度にカットしようとせず、基板の裏側とおもて側から少しずつ切り進めていきます。  
ケースねじ穴に当たらないよう、切り取った箇所のバリをやすりやカッターなどを使ってきれいにします。

切り離した状態
切り離した状態

ケースに基板を入れ、左右のネジだけでケースに固定します。

TOFUケースに入れた状態（中央ねじ穴）
TOFUケースに入れた状態（中央ねじ穴）

</details>

#### 方法2：ネジを使わずにケースへ固定

基板からすべてのネジ穴を切り取り、制振スポンジによってケース内側側面に固定することで、打鍵時の衝撃がケースのネジ穴へ直接伝わるのを抑える改造です。

<details>
<summary>《詳しい説明》</summary>

制振スポンジは、PORON（衝撃吸収の良いマイクロセルウレタンフォーム）などを使用します。

基板を支えるため、ケース内側に制振スポンジを敷き詰めます。  
ケースネジ穴と同じくらいの高さになるようにします。

すべてのネジ穴を、基板裏側に白い点線で描かれた切断ガイドに沿ってニッパーなどを使って切り離します。  
まわりの部品を傷つけないように注意しながら、一度にカットしようとせず、基板の裏側とおもて側から少しずつ切り進めていきます。

基板4辺の側面に、両面テープなどを使い、1.5mm厚の制振スポンジを貼り付けます。  
基板外形には0.5mmの凹みがついている箇所があるので、その部分へ貼り付けます。  
基板とケース内側との隙間が広い場合は、現物合わせで、凹みのない部分へ貼り付けます。

基板をケースへ入れます。

</details>

### 打鍵感向上：ケース内部の制振と静音化

ケース内部底面におもり（10円玉, 真鍮板, 自動車のホイールバランスウェイト, 鉛シート, etc.）を入れておくと、ケースの共振が抑えられ、打鍵感の向上や、打鍵音の変化が期待できます。

ウレタンスポンジやシリコンシートなどで基板とケース間の空間を埋めてケース内部の残響音を減らしたり、基板の振動を抑制して振動音の発生を抑えて静音化するのも効果的です。



### 打鍵感向上：キープレートと基板間のパテ埋め

キープレートと基板の間をパテ埋めすることで、打鍵感の向上を目指すための資料です。  

*施工後は各所のメンテナンスがしにくくなるため、キーボードをいったん完成させた後でおこなうことをおすすめします。*

パテ埋めすることで、次のような効果が期待できます。

- 剛性の大幅な向上
- 振動を大幅に低減
- キープレートと基板の間の空間で発生する音を除去
- キースイッチの安定性の向上

これらの効果により、ブレの少ないかっちりとした打鍵感と、密度が高く、明瞭で少しピッチが高い打鍵音を得ることができます。
<!-- 〓打鍵音比較を見せたいが、使用前がないかも -->

<details>
<summary>《詳しい説明》</summary>

組み立て済みの場合は、ケースから基板を取り外し、キープレートと基板を分離します。

キープレートにスイッチを取り付けた状態にして、裏側（スイッチの端子が見える側）を上にして置きます。

パテはエアコン配管用パテを使用します。



スイッチとスイッチの間、キープレートの枠の部分にパテを乗せます。  
基板と組み合わせた時に、スイッチと基板の間にはみ出さない程度の量にします。  
スタビライザーを取り付けているスイッチ付近は、スタビライザーの動作を妨げることがあるので、この段階ではパテを乗せずにおきます。



キープレートと基板を合わせ、スイッチをソケットにはめ込みます。

スタビライザー付近や、キープレートの枠がないスイッチの周り、基板外周部にパテを追加します。  



打鍵してみて、振動を感じたり、他と比べて音が異なる箇所があれば、スイッチを取り外してパテを押し込みます。



</details>

### トラブル対応：正常に入力できないスイッチの原因調査

正常に入力できないスイッチの原因調査方法について説明します。

<details>
<summary>《詳しい説明》</summary>

もっとも多い原因は、スイッチの取り付け不良です。  
スイッチを取り外し、端子が曲がったり折れたりしていないか確認します。  
端子の曲がりを修復するか、新しいスイッチに交換して、もう一度キー入力を確認します。

次いで多いのが、ソケットのはんだ不良です。  
ソケットのはんだ忘れや、はんだが適切に行われていないことが原因のため、ソケットのはんだ状態を確認します。  
必要であれば再度はんだ付けし直して、もう一度キー入力を確認します。

上記で解決できなかった場合は、基板のソケット用パッドをピンセットなどを使ってショートさせ、もう一度キー入力を確認します。  
キー入力が確認できた場合は、パッド自体は正常ですので、スイッチとソケットを再度調査します。

ソケット用パッドをショートしてもキー入力が確認できない場合は、組み立て途中に基板の配線や部品がダメージを受けたことが原因と考えられ、これ以降の調査と修復の難易度は、かなり高くなります。

電子工作に詳しい方であれば、[JonesのKiCadプロジェクト](https://github.com/jpskenn/Jones/tree/master/PCB)を参考にテスター等を用いて調査を進められると思います。

自分ではどうにもできない方は、キット同梱のリーフレットに記載された連絡先へ問い合わせてください。  
状況に応じて、できる限りのサポートをいたします。  

</details>

### トラブル対応：LEDの取り付け不良調査

LEDが点灯しない場合など、LEDの取り付け不良を調査する方法について説明します。

<details>
<summary>《詳しい説明》</summary>

#### ジャンパの確認

LEDの組み合わせに応じて、基板裏側のジャンパが正しく行われていることを確認します。

| 組み合わせ | 左側<br>LED1, 2 | 右側<br>LED3, 4 | ジャンパ<br>Left LEDs | ジャンパ<br>Right LEDs |
| :--: | :--: | :--: | :--: | :--: |
| LED未使用 | なし | なし | 不要 または Off | 不要 または Off |
| 左側のみ | あり | なし | On | 不要 または Off |
| 右側のみ | なし | あり | Off | On |
| 左右両方 | あり | あり | On | On |

#### LEDの確認

ジャンパが正しく行われても点灯しない場合は、LEDに原因があると考えられますので、以下の順に対処します。  

``` aside
なお、基板の配線へのダメージなど、他の要因も考えられますが、確率はかなり低いです。  
「組み立て中に工具で基板をガリっとやってしまった…」などの心当たりがあれば、また別ですが…
```

1. 光らないLEDのはんだ不良を修復する
    光らないLEDが正しくはんだ付けされていない、と仮定した対処です。
    光らないLEDの側面の端子部分にフラックスを塗り、こて先につけたはんだを押しあてて、はんだ付けをやり直します。

1. 光らないLEDの*ひとつ前*のLEDのはんだ不良を修復する
    光らないLEDのはんだは正常だが、ひとつ前のLEDのはんだ不良が原因で配線がつながっていない、と仮定した対処です。
    LEDは組み合わせによって、以下に示す順番で並んでいます。
    ひとつ前のLEDのはんだ付けをやり直します。
    | 組み合わせ | LEDの並び |
    | :--: | :-- |
    | 左側のみ | 左上（LED1） → 左下（LED2） |
    | 右側のみ | 右上（LED3） → 右下（LED4） |
    | 左右両方 | 左上（LED1） → 左下（LED2） → 右上（LED3） → 右下（LED4） |

1. 光らないLEDを新しいものに交換する
    220-270℃で1、2と数える程の加熱ではそう簡単にはLEDは壊れないと考えますが、何度かはんだをやり直しても点灯しない場合は、LEDが壊れていると判断して新しいものに交換します。

</details>

### 資料：USBコネクタ接続図

USBコネクタの配線は次の通りです。


USBコネクタ接続図

### 資料：ファームウェアの書き込み方法

ファームウェアの書き込み方法について説明します。

<details>
<summary>《詳しい説明》</summary>

#### QMK Toolboxの使用

ビルド済み（≒作成済み）のキーボード用ファームウェアを書き込むには、[QMK Toolbox](https://github.com/qmk/qmk_toolbox/releases)を使用します。

QMKファームウェアに関するドキュメントの、[ファームウェアを書き込む](https://docs.qmk.fm/#/ja/newbs_flashing?id=ファームウェアを書き込む)を参考に、QMK Toolboxを使ってキーボードに書き込みます。

#### キーボードを DFU (Bootloader) モードにする方法

JonesキーボードでDFU (Bootloader)モードにするには、次のように操作します。

1. USBケーブルを抜く

1. キーボードの左上のキーを押したまま、USBケーブルを差し込む

この操作によってEEPROMも消去されるので、古いデータが残って動作がおかしくなるのを防止できます。  
ファームウェアの書き込みが終わった後に外部EEPROMの消去がおこなわれるため、**キーボードの起動まで5〜10秒ほどかかります**。（書き込み直後の初回起動のみ）

**何らかの理由で上記の操作でモードが変わらない場合は、次のように操作します。**

1. USBケーブルを差し込みます。（キーボードが普通に使える状態）

1. 基板裏側のリセットボタン`Reset SW`を押します。

この操作をおこなった場合は、ファームウェアの書き込み後に[資料：EEPROMを消去して、初期状態に戻す方法](#資料eepromを消去して-初期状態に戻す方法)を実施して、EEPROMを初期状態に戻す必要があります。

</details>

### 資料：初期ファームウェアの機能と設定値

出荷時に書き込まれている初期ファームウェアの機能と設定値を説明します。

<details>
<summary>《詳しい説明》</summary>

- キーマップ書き換えツール
  RemapやVIAに対応。

- キーレイアウト
  Wideレイアウト

- キーマップ
  日本語配列を元にしたキーマップ

- レイヤー
  6個のレイヤー。
  初期状態では、Wideレイアウトで英語配列のキーマップが設定され、6個のレイヤーを使用できます。  
  レイヤー構成とLEDインジケータの色は次の通りです。

  | No. | レイヤー名 | 機能 | LEDインジケータ色<br>手前, 奥 |
| :-: | :-- | :-- | :-: |
| 0 | ベースレイヤー #1 | 日本語配列 | 白, 白 |
| 1 | ベースレイヤー #2 | テンキー | 青, 青 |
| 2 | ベースレイヤー #3 | （未設定） | 黄, 黄 |
| 3 | Lower | 記号, ボリューム, ファンクションキー | －, 緑 |
| 4 | Raise | カーソル移動, 数字, ファンクションキー | －, 水 |
| 5 | Adjust | 各種設定, スクロールロックなど | －, 赤 |

- レイヤーインジケータLED
  2個（左または右のいずれか）、または4個（左右両方）に対応。

- ロータリーエンコーダ
  1個（左または右のいずれか）、または2個（左右両方）に対応。

- オーディオ（スピーカー）
  単音再生に対応。
  起動音などの効果音, 擬似クリック音, Music Modeを使用可能。

</details>

### 資料：Jonesキーボードのファームウェア

ビルド済みファームウェアと、ソースファイルを用意しています。

#### ビルド済みのファームウェア

- [Jones v1 ファームウェア, VIA対応デフォルト](https://gist.github.com/jpskenn/3fcebf6a7c17f1a8433a8d954e05206f)

- [アンダーグロー対応 インジケータLEDなし用](https://gist.github.com/jpskenn/50e3ec1cdb09e1d24a6f2a5ed4cc2e15)

- [アンダーグロー対応 インジケータLED2個（左または右の、どちらか片側のみ）用](https://gist.github.com/jpskenn/5f6d95be0a71697aa9e7e743e40a73b2)

- [アンダーグロー対応 インジケータLED4個（左右両側）用](https://gist.github.com/jpskenn/cc2e155be9b250978d8f289e9917b5cd)

- [2音同時再生対応](https://gist.github.com/jpskenn/2a1d57117e745d635d038c64fdb32539)

#### ファームウェアのソース

2021年9月25日現在、QMK本家へのプルリクエストを申請中です。  
[[keyboard]Add v1 to jones keyboard #14405](https://github.com/qmk/qmk_firmware/pull/14405)

プルリクエストが取り込まれるまでは、僕のQMKからフォークしたリポジトリ  
[https://github.com/jpskenn/qmk_firmware](https://github.com/jpskenn/qmk_firmware)  
を使用してください。  

[develop_jones](https://github.com/jpskenn/qmk_firmware/tree/develop_Jones)ブランチの、`keyboards/jones/v1`に関連ファイルが格納されています。

### 資料：EEPROMを消去して、初期状態に戻す方法

キーマップやLEDの表示モードなどのEEPROMに記録されているデータを消去し、初期状態に戻すことができます。  

また、古いデータが残って動作がおかしくなるのを防止するため、ファームウェアを書き換える際にもこの操作をおこないます。

<details>
<summary>《詳しい説明》</summary>

USBケーブルを抜きます。

キーボードの左上のキーを押したまま、USBケーブルを差し込みます。

差し込んで1,2と数えてから、USBケーブルを抜きます。

USBケーブルを差し込みます。

5〜10秒ほどで外部EEPROMが消去され、キーボードが動作するようになります。  

これで設定が初期状態に戻ります。

</details>

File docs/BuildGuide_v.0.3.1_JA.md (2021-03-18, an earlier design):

# Jones v.0.3.1 ビルドガイド

購入していただいた方、リポジトリから製造していただいた方、その他の皆様、Jonesに興味を持っていただきありがとうございます。

Jonesのコンセプトや特徴などについては、[Jones README](https://github.com/jpskenn/Jones/blob/master/README.md)をご覧ください。

## 注意事項、制限など

- 一部の金属製ケースと組み合わせて使用した場合、誤入力が発生する場合があります。

    [誤入力対策](#誤入力対策)を参照してください。

- v.0.3.1の基板設計ミスにより以下の制限があります。（v.0.3.2では制限なし）  
    - 基板の配線を1箇所カットしてあります。（写真の矢印部分）
    - ANSIスタイルの”[”キーは、`SW_[1`のMXソケットを使用できません。（写真の×部分）  
    `SW_[2`へ取り付け済みのmill-maxソケットへ、スイッチを取り付けてください。（写真の○部分）  
  

    - JPスタイルのレイアウトを使用する際は、`SW_[2`へ取り付け済みのmill-maxソケットを取り外してください。  
    SW_@1へ取り付けるスイッチと干渉します。  
  基板の裏側から、mill-maxソケット側面をはんだごてで温めながら爪楊枝などで押し込むと、ポロッと外れます。

- ケースのネジ穴とスイッチの足が干渉する箇所では、スイッチの足を加工して取り付ける箇所があります。  

    Hキーは、3pinまたは片方の足をカットした5pinスイッチを取り付けます。  
基本的なANSIスタイルの[キーは、中央の足（でっぱり部分）を一部カットして取り付けます。

- 個性的なレイアウトは、スイッチソケットに対応していない箇所があります。  

    基本的なレイアウトのANSIとJPスタイルはスイッチソケットに対応しています。  
詳しくは以下のレイアウト図で確認してください。  
[Jones v.3.5.4 ソケットとスイッチ穴の方向](http://www.keyboard-layout-editor.com/#/gists/ef36178a15efbbe5e7411bcdeef87fc4)

- スイッチを上下逆向きに取り付ける箇所があります。  

    USBコネクタやネジ穴に干渉するキーや、複数のレイアウトを選べるキーは、スイッチを上下逆向きに取り付ける箇所があります。  
キーキャップによっては、キャップとスイッチが当たるかもしれません。（GMKのキーキャップでは当たることがあるようですが、所有していないため試せていません）  

    一部のキーは、上下逆向きを回避するための非ソケットのスイッチ穴が使える箇所もあります。  
詳しくは以下のレイアウト図で確認してください。  
[Jones v.3.5.4 ソケットとスイッチ穴の方向](http://www.keyboard-layout-editor.com/#/gists/ef36178a15efbbe5e7411bcdeef87fc4)

- 2U幅の左シフトキー用のスタビライザーは、ケースネジと左側LEDに干渉するため推奨しません。  

    左シフトキーは1.75U幅を使用するか、2U幅をスタビライザーなしで使用することをおすすめします。  

    2U幅の左シフトキー用のスタビライザーを使用する場合は、左側LEDを設置できません。  
また、スタビライザーを一部カットして取り付けるなどの工夫が必要です。

- もしかしたら、取り付けできないケースがあるかもしれません。  

    全てのGH60型ケースに取り付けできるかは、なんとも言えません…  
現在のところ、取り付け確認済みのケースは次の通りです。  
    - [KBDfans TOFU 60% ALUMINUM CASE](https://kbdfans.com/products/kbdfans-tofu-60-aluminum-case)  
    - [KBDfans 5° FROSTED ACRYLIC CNC 60% CASE](https://kbdfans.com/products/pre-order-kbdfans5-transparent-acrylic-cnc-60-case)  
    - [60% プラスチックケース](https://yushakobo.jp/shop/60-plastic-case/)（簡単な加工が必要）

    上記以外のケースへの取り付けの成功／失敗の報告を募集しております。

## 部品リスト

このキットを組み立てるためには、”キット内容物”に加え、”別途用意が必要な部品”が必要です。  
好みのものをお買い求めください。

なお、”オプション部品”は使いたい機能などに合わせて任意に用意してください。  

### キット内容物

| 部品名 | 個数 |
| ----- | -----: |
| Jones 基板 v.0.3.1 | 1 |
| Jones キープレート v.3.5.4 | 1 |
| USBコネクタ<br>GCT USB4085-GF-A| 1 |
| リセットスイッチ<br>RS-187R05A2-DS MT RT（または同等品） | 1 |
| 低頭ネジ<br>M2 4mm | 4(\*) |
| 低頭ネジ<br>M2 5mm | 4(\*) |

\* レイアウトとネジ止め箇所によって使用数が変わります。  
ケースネジの長さに合わせて使用し、残りはケース付属のネジを使用します。

### 別途用意が必要な部品

| 部品名 | 個数 |
| ----- | -----: |
| MXソケット | 最大 69(\*) |
| MXスイッチ | 最大 69(\*) |
| PCBマウント スタビライザー：2U<br>（ねじ止め式を推奨） | 3(\**) |
| キーキャップ | 必要数(\*) |
| ケース（GH60型） | 1 |
| USBケーブル （Type-C） | 1 |

\*レイアウトによって使用数が変わります。  
\**2Uの幅の左シフト（非推奨）を使用する場合は4。

### オプション部品

| 部品名 | 個数 | 使用機能, 備考 |
| ----- | -----: | ----- |
| Mill-Maxソケット | 必要数 | 個性的なレイアウト |
| LED<br>SK6812MINI | 最大 6 | インジケータLED |
| LEDテープ<br>26cm程度(\*) | 1 | アンダーグローLED |
| ロータリーエンコーダ<br>EC11, EC12またはその互換品 | 最大 2 | ロータリーエンコーダ |
| ロータリーエンコーダ用ノブ（つまみ） | 最大 2 | ロータリーエンコーダ |
| スピーカー<br>Murata PKMCS0909E4000-R1 | 1 | スピーカー |
| カプトンテープ | 必要な長さ | アンダーグローLEDの貼り付け,<br>絶縁など |

\*ファームウェアは1mに60個のLEDが配置されたLEDテープを想定して作成しています。

## 組み立てに必要な工具
ドライバー、ピンセット、はんだ付け関連用品など、一般的な電子工作向け工具を使用します。  
[遊舎工房の工具セット](https://yushakobo.jp/shop/a9900to/)を参考に用意してください。

安いものでもかまわないので、USBコネクタなどの導通確認にテスターを用意してください。  
作業の確認や、何か不具合があったときの原因調査にも使えます。

## 基板概要

（写真はv.0.3基板のため細部が少し異なります。）

- 基板おもて側  
部品が何も取り付けられていません。
基板おもて側

- 基板裏側  
細かな部品がたくさん取り付けられています。


- キープレートおもて側  
右上に切り欠きがあります。


## 組み立て手順

*作業をおこなう前に、各手順に目を通しておくと作業ミスの防止につながります。*

### 誤入力対策（v.0.3.2は対策不要）

一部の金属製ケースと組み合わせて使用した場合に、誤入力が発生する問題への対策をおこないます。

基板をおもて側にして、中央ネジ穴付近と下のネジ穴付近の、2箇所の作業箇所を確認します。


2箇所の作業箇所

#### 1箇所目

基板をおもて側にして、中央ネジ穴付近の配線を、写真で示した位置でカットします。 

カッターやマイナスドライバーを使い、他の配線を傷つけないように注意しながら、少しずつ削ります。 
1回でカットしようとせず、数回〜20回くらいにわけて少しずつ削ります。


中央ネジ穴付近、配線カット箇所

配線をカットしたら、基板をうら側にします。 
中央ネジ穴とダイオードD78の下側を、テスターで導通が**ない**ことを確認します。

 
1箇所目のテスター確認箇所

#### 2箇所目

基板をおもて側にして、下のネジ穴付近の配線を、写真で示した位置でカットします。



配線をカットしたら、基板をうら側にします。 
下のネジ穴と写真で示した正方形のパッドを、テスターで導通が**ない**ことを確認します。

 
2箇所目のテスター確認箇所

### リセットスイッチの取り付け

基板裏側の`ResetSW1`へ取り付けます。

基板のパッド4箇所のうち、1箇所だけに予備はんだします。


予備はんだ

リセットスイッチを基板のパッド位置に合わせて置きます。  
方向はどちら向きでも大丈夫です。

予備はんだしておいた箇所をはんだ付けします。

位置がずれていないことを確認します。

残りのパッド3箇所をはんだ付けします。


取り付けたリセットスイッチ

### USBコネクタの取り付け

基板裏側の`J1`へ取り付けます。

コネクタを基板裏側から差し込み、マスキングテープなどで仮固定します。


仮固定したUSBコネクタ

基板をひっくり返し、基板おもて側から、4本ある足の長い方の1本だけをはんだ付けします。  
コネクタがまっすぐ奥まで差し込まれた状態ではんだ付けされるようにします。

残り3本の足をはんだ付けします。

コネクタのピンをはんだ付けします。  
フラックスを塗っておくとはんだ付けしやすくなります。  
ピンはスルーホールからほとんど出ていないため、スルーホールにはんだを流し込むような具合ではんだ付けします。  
スルーホールの向こう側（基板おもて側）にはんだが溢れてしまわないよう、流し込みすぎないように注意します。


取り付けたUSBコネクタ

目視で、隣り合ったピン同士がはんだでくっついていないことを確認します。

USBコネクタ接続図を参考に、テスターで全てのピン間での導通を確認します。  
- A6とB6、A7とB7のように、緑または赤の線でつながっているピンや、GND同士、VCC同士で導通があることを確認します。  
- A1とA4、B6とB7のように、緑または赤の線でつながっていないピンでは導通しないことを確認します。  


USBコネクタ接続図

例えば、A1との導通は、次のようになります。

| ピン | 導通 | | ピン | 導通 |
| --- | :---: | --- | --- | :---: |
| A1 | － | | B1 | あり |
| A4 | なし | | B4 | なし |
| A5 | なし | | B5 | なし |
| A6 | なし | | B6 | なし |
| A7 | なし | | B7 | なし |
| A8 | なし | | B8 | なし |
| A9 | なし | | B9 | なし |
| A12 | あり | | B12 | あり |

### キーボードの接続確認
以下の手順Aまたは手順Bのいずれかをおこない、PCやMacでキーボードが認識されることを確認します。

接続が確認できない場合は、USBコネクタの取り付け不良などが疑われます。  
はんだ付けしたコネクタ端子、USBケーブル接続部分、コネクタに接続したケーブルの反対側などをテスターで確認してください。

#### 手順A QMK Toolboxによる確認
[QMK Toolbox](https://docs.qmk.fm/#/ja/newbs_getting_started?id=qmk-toolbox)をダンロードし、使用できる状態にしておきます。  

QMK Toolboxを起動します。

キーボードを接続します。

QMK Toolboxのメッセージエリアに、以下のメッセージが表示されれば、接続確認はOKです。

    *** DFU device connected

  
表示されたメッセージ

#### 手順B OSのデバイス管理機能による確認

キーボードを接続します。

##### Mac

　→　このMacについて　→　システムレポート… を開きます。

ハードウェアのUSBに、`ATm32U4DFU`のデバイスが表示されていれば、接続確認はOKです。

  
システムレポートの表示  
（下に`Jones`と表示されているのは、以前作成したv.0.2のJonesです💦）

##### Windows

（調査中）

### ファームウェアの書き込み
このあとの作業で各機能の動作確認をおこなうため、ファームウェアを書き込みます。

ファームウェアは以下よりダウンロードし、QMK Toolbox、またはQMKのコマンドなどで書き込んでください。  
なお、各ファイルは本家QMKには取り込まれていませんので、私がフォークしたリポジトリから取得してください。

- QMK Toolbox用hexファイル：  
[基本的なANSIスタイル用](https://gist.github.com/jpskenn/e458aba60c828ac9f2b4f6b7c2098455)  
[基本的なJPスタイル用](https://gist.github.com/jpskenn/6c6ec73f580b8839b76e3e6510bacca9)  

- QMKコマンド用キーボード関連ファイル：  
[jpskenn/qmk_firmware: develop_Jonesブランチ](https://github.com/jpskenn/qmk_firmware/tree/develop_Jones/)

#### QMK Toolbox
書き込むhexファイルを指定します。  

キーボードを接続します。

キーボードのリセットスイッチを押して、`*** DFU device connected`が表示されることを確認します。  

Flashボタンを押して書き込みます。

写真のような書き込みメッセージが表示されれば完了です。

  
書き込みメッセージ  
（ファイル名や%の数値などは実際と異なる場合があります）

#### QMKコマンド
ダウンロードしたファイルをQMKのkeyboardsディレクトリ配下へ配置します。  

キーレイアウトに合わせて、いずれかのコマンドを実行します。

ANSIスタイル

    qmk flash -kb jones/v.0.3.1 -km default_ansi

JPスタイル

    qmk flash -kb jones/v.0.3.1 -km default_jp

何やら画面に表示された後、しばらくすると次のようなメッセージが繰り返し表示されます。

    dfu-programmer: no device present.
    ERROR: Bootloader not found. Trying again in 5s.

キーボードのリセットスイッチを押すと書き込みが始まります。

次のようなメッセージが表示されたら完了です。  
（%の数値などは実際とは異なる場合があります）

```
Bootloader Version: 0x00 (0)
Erasing flash...  Success
Checking memory from 0x0 to 0x6FFF...  Empty.
0%                            100%  Programming 0x6900 bytes...
[>>>>>>>>>>>>>>>>>>>>>>>>>>>>>>>>]  Success
0%                            100%  Reading 0x7000 bytes...
[>>>>>>>>>>>>>>>>>>>>>>>>>>>>>>>>]  Success
Validating...  Success
0x6900 bytes written into 0x7000 bytes memory (93.75%).
```

### （オプション・サポート外）基板のフレックス加工
基板から中央とスペースキー右側にあるネジ穴を切り取り、基板の左右だけでケースに固定することで基板を適度にしならせ、柔らかい打鍵感を得られる加工をおこなうことができます。  

打鍵感の好みは各個人で異なるため、一度組み立てて使ってみて、後から加工することもできます。  

なお、**この加工による基板の破損や、ケースへの取り付け不良が発生することが考えられるため、サポート外とします**。加工者の責任で作業をおこなってください。  
（KBDfans 5° FROSTED ACRYLIC CNC 60% CASEでは、特に問題なく快適に使用できています。）

加工箇所を確認します。  
加工すると正方向の`SW_ROPT/KANA1.25u` *`1`* のソケットは使えなくなるため、逆方向の`SW_ROPT/KANA1.25u` *`2`* のソケットを使用してください。（スイッチの位置は同じです）

  
基板裏側から見た加工箇所

ニッパーなどを使い、基板裏面に描かれた点線で切り離します。  
まわりの部品を傷つけないように気をつけながら、一度にカットせず、少しずつ切り進めていきます。

  
切り取ったネジ穴

### スイッチソケットの取り付け
基板裏側から取り付けます。

使用するレイアウトに合わせて取り付け位置を確認します。  
1箇所に複数のキーが集まっているところは、スイッチやキーキャップを実際に置いてみるとわかりやすくなります。  

[key layouts  
Keyboard Layout Editor: Jones v.3.5.4](http://www.keyboard-layout-editor.com/#/gists/ab35444150ef1aff63ed32bbe2b9a1ef)  

基本的なANSIスタイルと、基本的なJPスタイルのレイアウトはスイッチソケットに対応しています。  
スイッチソケットに対応していない箇所は、mill-maxソケットでソケット化するか、スイッチを直接はんだ付けします。  

**注意：  
ネジ穴の上に位置するキーは、直接はんだ付けしてはいけません。  
ソケットを使用し、ネジ止めした後にスイッチを取り付けられるよう、ソケットを使用します。**

基板のソケット用パッドの片方だけに予備はんだします。


ソケット用パッドへの予備はんだ

ソケットを基板の穴にはまるように置きます。  
スイッチ中央の穴をソケットでふさがない向きが正しい方向です。


ソケットの方向

ピンセットでソケットを押さえながら、予備はんだしたところをはんだ付けします。  
金属部分の間へコテ先を押し込んで、1、2、3と数えたくらいではんだが溶け、浮いていたソケットが基板に接します。  
ソケットが基板に接したら、1、2と数えたくらいでコテ先を離し、そこから1、2と数えてからピンセットを離します。


金属部分へコテ先を押し込む

ソケットが基板から浮いていないことを確認します。  


ソケットの浮き

反対側の金属部分へコテ先を押し込み、1、2、3と数えて温めます。  
基板のパッドと金属部分の間あたりへはんだを押しつけ、溶かしながら隙間へ流し込みます。  
流し込んだら、1、2と数えてコテ先を離します。

パッドにはんだが広がる程度に流し込んでください。  
金属部分の間に、はんだがポコっと盛り上がって固まっていれば十分です。


取り付けたソケット

### （オプション）スピーカーの取り付け
基板裏側でジャンパして、おもて側にスピーカーを取り付けます。

基板裏側のジャンパ`simultaneous audio`をジャンパすると、2音同時再生できるようになります。  
ジャンパしない場合は単音で再生されます。

  
ジャンパ箇所

  
ジャンパした状態

基板おもて側、スピーカー`LS1`のパッド2箇所のうち、1箇所だけに予備はんだしておきます。

スピーカーをパッドに合わせて置きます。  
どちらの方向に取り付けても大丈夫です。  
スピーカーの穴がキープレートの空き部分にくるような方向に取り付けると音が聞こえやすくなります。

予備はんだした箇所をはんだ付けします

スピーカーがまっすぐ取り付けられていることを確認します。

残りの1箇所をはんだ付けします。


取り付けたスピーカー

### （オプション）インジケータLEDの取り付け
基板裏側でジャンパし、おもて側の`LED1〜8`へ取り付けます。

インジケータLEDの組み合わせは次の通りです。  
左側LEDは4個、右側LEDは2行目または3行目のいずれかに2個取り付けます。

| 組み合わせ | 左側LED | 右側LED |
| :--: | :--: | :--: |
| A | なし | なし |
| B | なし | 2行目 |
| C | なし | 3行目 |
| D | あり | なし |
| E | あり | 2行目 |
| F | あり | 3行目 |

基板裏側のジャンパ`Left LEDs`を、左側LEDを使用する場合は`On`に、使用しない場合は`Off`にジャンパします。
  
左側LEDジャンパ位置

基板裏側のジャンパ`Right LEDs`を、右側LEDを使用する場合は`On`に、使用しない場合には`Off`にジャンパします。  
また、右側LEDを使用する場合は、基板裏側のジャンパ`Right LED Pos.`を、LEDの位置が2行目（＝R2）の場合は`R2`に、3行目（＝R3)の場合は`R3`にジャンパします。
  
右側LEDジャンパ位置

  
右側LEDをON、右側LEDの位置を3行目（＝R3）にジャンパした状態

基板おもて側から、選んだ組み合わせの位置にLEDをはんだ付けします。
- 左側LED 4個： `LED1〜4`
- 右側LED 2個： 2行目 `LED5〜6`　または　3行目 `LED7〜8`

基板の各LEDのパッドそれぞれ4箇所のうち、1箇所だけに予備はんだしておきます。

LEDは高温ではんだ付けすると壊れるため、コテ先温度を220-270℃に設定します。
使用するはんだの種類や作業手順にもよりますが、220℃では加熱不足によるはんだ不良に注意してください。

[加熱不足による、はんだ不良の例](https://twitter.com/jpskenn/status/1291328876283478016)

▲マークが設置位置を示す縦線の場所に合うように、LEDを基板に置きます。  
**左右でLEDの設置方向が異なるため注意してください。**


LED取り付け方向を示す縦線とLEDの方向、LED5およびLED6へ予備はんだした状態

フラックスを塗っておくとはんだ付けしやすくなります。

予備はんだした箇所をはんだ付けします。  
ピンセットでLEDをつまみ、位置がずれないようにします。  
小手先温度を220-270℃にして、LEDの横方向からパッドとLEDにコテ先をあて、1、2と数えてコテ先を離します。  
さらに1、2と数えてLEDを固定していたピンセットを離します。  
はんだが小さな球のようになっていれば良い仕上がりです。

LEDの位置がずれていないことを確認します。

残りの3箇所をはんだ付けします。  
予備はんだ以外の3箇所は、少量のはんだをコテ先に乗せておき、先ほどと同様の手順をおこないます。


取り付けたLED

### （オプション）LEDテープの取り付け
基板裏側から`LED TAPE`へ取り付けます。

LEDテープの取り付け位置を確認し、使用する長さにカットしておきます。  
基板上の部品やソケットへの接触が心配される箇所は、絶縁のためにカプトンテープなどを貼っておきます。

基板のLEDテープ用パッドの、+5V、LED、GNDの3箇所に予備はんだしておきます。

LEDテープをパッドに重ね、端子部分をコテ先で押さえつけるようにして、真ん中のLEDパッドだけをはんだ付けします。

LEDテープがまっすぐ取り付けられていることを確認します。

残りの+5VとGNDのパッドをはんだ付けします。

テープを貼り付けます。  
テープ自体のシール部分を使わず、カプトンテープなどで貼り付けておくと、後からメンテナンスしやすいかもしれません。

  
LEDテープを取り付けた状態

#### （オプション）ロータリーエンコーダの取り付け
基板おもて面から取り付けます。

右下`SW_RE1`と左下`SW_RE2`のどちらか片方のみ、または両方へ取り付けできます。

ピンと足の位置を合わせて基板に差し込みます。  
足が差し込みにくいときは、横から少し押さえて差し込みます。

基板裏側から、何本かあるピンのうち1本だけをはんだ付けします。

ロータリーエンコーダがまっすぐ取り付けられていることを確認します。

残りのピンをはんだ付けします。


取り付けたロータリーエンコーダ（基板おもて側）


取り付けたロータリーエンコーダ（基板裏側）

### スタビライザーの取り付け
基板おもて側から取り付けます。  
なお、2U幅の左シフトキー用のスタビライザーはケースネジに干渉するため、使用には工夫が必要です。

使用するレイアウトに合わせて、スタビライザーの取り付け位置を確認します。  
スタビライザーの棒が大きい穴の側にくる方向に取り付けます。

引っ掛ける部分を斜めに差し込んで引っ掛けてから、反対側の差し込み部分を押し込みます。


取り付けたスタビライザー

### キースイッチの取り付け
キープレートおもて面からスイッチを取り付けます。

使用するレイアウトに合わせ、キープレートの4隅にスイッチをはめ込みます。  
右上は枠の切れた2箇所を避け、3番目の枠へはめ込みます。  
左下、右下にロータリーエンコーダを取り付けている場合は、その隣へはめ込みます。


キープレート4隅につけたスイッチ

4個のスイッチをはめ込んだキープレートを、基板に合わせて乗せます。  
スタビライザーがキープレートの枠にはまるように、位置を調整します。


キープレートの枠にはまったスタビライザー（他のスイッチも取り付けた状態で撮影）

4隅のスイッチを基板のソケットに差し込みます。  
スイッチが奥まで差し込めていないときは、なるべくソケットの後ろ側を押さえながら、少しだけ力を入れて（※）押し込みます。  
※：洗濯バサミを開くよりもちょっと強いくらいの力

残りのスイッチを取り付けます。  
スイッチのピンを曲げないように気をつけます。

ソケットを使用しない箇所は、この時点でスイッチをはんだ付けします。

**注意：  
ネジ穴の上に位置するキーは、直接はんだ付けしてはいけません。  
ソケットを使用し、ネジ止めした後にスイッチを取り付けられるよう、ソケットを使用します。**

スイッチの足がケースネジ穴に干渉する箇所は、スイッチの足をカットして取り付けます。  
例えば、Hキーに5pinスイッチを使用する場合は、片方の足をカットします。  


また、ANSIスタイルの[キーは、中央の足（でっぱり部分）がネジに当たらないよう、1/4-1/3ほどカットします。  
押下時に軸がネジに当たる場合は、軸の下端をカットしてください。  



足をカットしたスイッチ  
  
左から順に  
- Gateron Silent Red 5pin：片方の足をカット
- Gateron Ink Black 5pin：片方の足をカット
- Kailh Pro Burgundy 3pin：無加工
- Gateron Ink Red 5pin：片方の足をカット、中央の足を1/3カット
- Gateron Silent Red 5pin：両方の足をカット、中央の足を全てカット

ほとんどのスイッチがこの加工で取り付けられるはずですが、うまく取り付けられないことも考えられます。  
以下の取り付け確認済みスイッチを参考にしてください。  

取り付け確認済みスイッチ：  
- Gateron Silent Red
- Gateron Silent White
- Gateron Ink Black
- Gateron Ink Red

### 動作確認
ケースへ取り付ける前に、キーボードをPCやMacに接続して動作確認を行います。

#### キースイッチの動作確認
確認の前に、実際のキーボードの配列と、OSが認識するキーボードの配列を合わせておきます。  
実際のキーボードの配列がANSIスタイルで、OSが日本語キーボードと認識しているような組み合わせや、この逆のような組み合わせのような場合は、意図した通りの入力結果になりません。  
OSの設定方法に従い、OSが認識するキーボードの配列を変更します。

確認は、OSのキーボードビューアや、[Keyboard Checker](https://keyboardchecker.com)、[QMK Configrator](https://config.qmk.fm/)の入力テスト機能を使用して行います。  
全てのキーで正常に入力できることを確認します。

なお、初めてJonesキーボードを使用する際はMac向けのキーマップに設定されているため、WindowsではALTキーとWindowsキーが逆に認識されます。  
Windows向けのキーマップには`Lower + Raise + W`を、Mac向けのキーマップには`Lower + Raise + M`を押して切り替えます。

また、LowerキーはOSで認識されないので、Lowerキーと組み合わせたキー、たとえば、`Lower + 1`の組み合わせで`F1`キーが入力できることを確認します。  

正常に入力できないキーがあった場合は、原因を調査し、修復します。

もっとも多い原因は、スイッチとソケットの取り付け不良です。  
スイッチを取り外し、ピンが曲がったり折れたりしていないか確認し、ペンチなどでピンの曲がりを修復するか新しいものに交換します。  
また、ソケットのはんだ忘れや、はんだ不良もよくある原因のため、ソケットのはんだを確認し、必要であれば再度はんだ付けします。  
スイッチをソケットへ確実に差し込み直して、もう一度キー入力ができることを確認します。

上記で解決できなかった場合、基板のソケット用パッド部分の2箇所をピンセットなどを使ってショートさせ、キー入力されるか確認します。  
キー入力された場合は、ソケットまたはスイッチに問題があるため、再度確認します。  
それでも改善されない場合は、スイッチとソケットを交換します。


ピンセットを使ってパッド部分をショートさせる

あまり考えられないことですが、パッドをショートしてもキー入力されない場合は、基板や部品へのダメージなどが原因と考えられます。  
これまでの軽微な作業ミスが原因だった場合とは異なり、原因箇所の特定にはテスターを使った詳しい調査が必要となり、修復の難易度も高くなることが予想されます。  
[Jones v.0.3.1 KiCadプロジェクト](https://github.com/jpskenn/Jones/tree/PCB_v.0.3.1/PCB)のPCB設計を参照し、パッド、ダイオード、MCUのピンなどの導通を確認して調査します。  
なお、基板製造上の問題を含む場合も疑われますので、[Twitter: @jpskenn](https://twitter.com/jpskenn/)へご一報いただければ、何か情報共有できるかもしれません。

#### ロータリーエンコーダの動作確認

ロータリーエンコーダのつまみを回し、OSの音声出力ボリュームが変化することを確認します。  

また、プッシュボタンスイッチ付きのロータリーエンコーダでは、プッシュするとOSの音声出力がミュート／ミュート解除されることを確認します。

デフォルトのキーマップでは、左下、右下ともに、同じ機能が割り当てられています。

動作不良の場合は、はんだ付けをやり直してください。

#### LEDの動作確認

右側2個のLEDが点灯（Mac向けのキーマップでは白色、Windows向けのキーマップでは青色）していれば正常です。

左側とLEDテープは`Lower + Raise + L`で点灯オン／オフが切り替わり、全て点灯していれば正常です。

光らない箇所がある場合は、次の法則にしたがって調査、修復します。

LEDは`左側の上から下　→　右側（2行目または3行目）の上から下　→　LEDテープ`の順に並んでおり、取り付け不良のLEDより先は光らない。  
また、取り付け不良のLEDには以下の2パターンあります。  
A. そのLED自体のはんだ不良のため光らない  
B. そのLEDから次のLEDへつながる端子だけはんだ不良のため光らない

次の例は、どちらも光るLEDは同じですが、不良箇所が異なることに注意してください。  
例1：右側の2個目がパターンAの取り付け不良だった場合、左側4個と右側の1個目だけ光り、右側2個目とLEDテープは光らない。  
例2：右側の1個目がパターンBの取り付け不良だった場合、左側4個と右側の1個目だけ光り、右側2個目とLEDテープは光らない。

以上をふまえ、  
先頭から数えて最初の光らないLEDについて、
光っていないLED自体のはんだをやり直して、点灯するかどうか確認し、  
点灯しない場合は、一つ手前のLEDのはんだをやり直して、点灯するか確認する  
という調査、修復をおこないます。

220-270℃で1、2と数える程の加熱ではそう簡単にはLEDは壊れないと考えますが、何度かはんだをやり直しても点灯しない場合は、LEDが壊れていると判断して新しいものに交換します。

主なLED関連キーは次の通りです。

    Lower + Raise + L  LED点灯のオン／オフ
    Lower + Raise + Lの右隣のキー（;）　次の点灯モードに切り替え
    Lower + Raise + P　前の点灯モードに切り替え
    Lower + Raise + I　LEDの輝度増加
    Lower + Raise + K　LEDの輝度低下

#### スピーカーの動作確認
キーボードとPCやMacを接続した際、♪ピロリロという音が鳴っていれば確認OKです。

音が鳴らない場合は、スピーカーのはんだ付けをやり直します。

主なスピーカー関連キーは次の通りです。

    Lower + Raise + A　スピーカーのオン／オフ切り替え
    Lower + Raise + S　タイプ音のオン／オフ切り替え
    Lower + Raise + A　ミュージックモードのオン／オフ切り替え

### （該当者のみ）60% プラスチックケースの加工

60% プラスチックケースへ取り付ける際は、ネジ穴と同じ高さのケース内リブが基板上の部品と干渉するため、以下の加工を行います。

#### 干渉箇所のカット
カットする箇所を確認します。  
次の場所の、ケースネジ穴と同じ高さになっているリブです。  
- 左の上側ネジの上下。
- 右の上側ネジの上下。
- ケース一番下の長いリブのうち、ソケットに当たる部分。  
（スイッチが上下逆向きになって、ソケットが下側に来ている箇所）


カット箇所


カット例、左の上側ネジの上下


カット例、一番下の長いリブ

写真で示した部分を、ニッパーやカッターなどを使ってカットします。  
ニッパー使用時は、1-2mmくらいずつ切り進んでいきます。  
それ以上の長さをカットすると、意図しないところまで割れてしまうことがあります。

### ケースへの取り付け

取り付け前に、Hキーなどのネジ穴にかぶさるスイッチを外しておきます。

基板の奥側（USBコネクタ側）からケース内へ入れていきます。  
ケースに対して基板を30度くらいの角度で差し込むと、USBコネクタがケースの穴にスッとはまります。  
その状態で基板の手前側をおろして水平にすると、力をかけることなく、基板全体がストンとケースに入ります。  
力を入れてグリグリとこじったり、ググググッと押し込むようなことはせず、角度を合わせて差し込むだけです。


30度で差し込む

ケースネジ穴と基板のネジ穴の位置を合わせ、ネジで仮止めします。  

基板が上下左右の真ん中になるように位置を調整します。

左の上側のネジを固定してから、残りのネジを固定します。  
スイッチがかぶさる箇所は低頭ネジを使用します。  
なお、左右の4箇所だけネジ止めして、中央と中央下をネジ止めせずに使用しても特に問題ありません。

取り外してしていたスイッチを取り付けます。

### 仕上げ

PCやMacに接続し、各部の動作を簡単に確認しておきます。

ケース底面に滑り止めのクッションパッドを貼り付けます。  
60% プラスチックケースに付属するパッドが貼り付け部分よりも大きいときは、ハサミなどでカットして貼り付けます。

ロータリーエンコーダのノブを取り付けます。

キーキャップを取り付けます。

完成です。

写真を撮影し、`#Jones_kbd` のタグをつけてツイートすると設計者が喜んだりします。  
[Twitter: #Jones_kbd](https://twitter.com/search?q=%23Jones_kbd)

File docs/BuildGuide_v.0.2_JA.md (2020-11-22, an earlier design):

# Jones v.0.2 ビルドガイド

## 注意事項、制限など

制作にあたり、次のような注意事項、制限があります。

- ケースのネジ穴とスイッチの足の干渉  
市販のケースはJonesレイアウト向けに設計されていないので、ケースのネジ穴とスイッチの足が干渉する箇所があります。  
これらの箇所では、基板を低頭ネジでケースへ固定し、スイッチの足がねじ穴に重なる場合は、3pinのスイッチ、または足をカットした5pinスイッチを取り付けてください。  

 レイアウトによっては、スイッチ中央の足（でっぱり部分）がネジに当たらないよう、1/4～1/3ほどカットする必要があります。  

- スイッチソケット
レイアウトのバリエーションすべてをソケット化できないため、スイッチソケットに非対応の箇所があります。  
Mill-Maxソケットでソケット化するか、スイッチを直接はんだ付けしてください。

- スタビライザー
Jonesレイアウトでは左シフトキーのサイズが2Uのため、スタビライザーを取り付けるとケース取り付けネジと干渉し、ねじ止めできなくなる場合があります。  
ネジ止めしなくても問題なく使用できますが、気になる方はスタビライザーを加工するなどの工夫が必要です。

### v.0.2の注意事項、制限

- LEDテープ用シルクの間違い  
シルク表記のGNDと+5Vが逆になっています。  
誤：GND/LED/+5V  
正：+5V/LED/GND

## 部品リスト

### 基本部品

| 部品名 | 個数 |
| ----- | -----: |
| Jones 基板 | 1 |
| USBコネクタ<br>MOLEX 548190519| 1 |
| リセットスイッチ<br>RS-187R05A2-DS MT RT | 1 |
| リセッタブルヒューズ<br>500mA トリップ1A 1206 | 1 |
| MXソケット | 約60(\*) |
| MXスイッチ | 約60(\*) |

\*レイアウトによって使用数が変わります。

### オプション部品

| 部品名 | 個数 |
| ----- | -----: |
| Mill-Maxソケット | 必要数 |
| LED SK6812MINI | 2 |
| ロータリーエンコーダ EC11、EC12互換 | 1 |
| ブロッカー（基板に付属） | 必要数 |
| キープレート（下記参照）| 1 |

#### キープレート

発注について

## 組み立てに必要な工具
ドライバー、ピンセット、はんだ付け関連用品など、一般的な電子工作向け工具が必要です。  
また、MCUやUSBコネクタ取り付け後の確認にテスターが必要です。

以上に加え、やすりがあると仕上がりがきれいになります。  
また、ヘッドマウント型のルーペがあると細かいはんだ付けが楽になります。

## 基板概要
〓基板全体写真　おもて〓
〓基板全体写真　裏〓

〓基板説明。捨て基板とかブロッカーとかの呼び方とかも。

## 組み立て手順

部品の実装は、特に記載がない限り、基板裏面へ取り付けます。
表面から取り付る部品は、スタビライザー、MXスイッチ、インジケータ用のLED、ロータリーエンコーダのみです。

### 基板の切り離し

捨て基板、ブロッカーパーツを切り離します。  
マウスバイトの両側を指でつまみ、折り曲げて切り離します。  
切り離した箇所はとがっているので、ニッパーでカットしたり、やすりで削っておきます。  
〓つまんで、折り曲げようとしている写真〓
〓バリと、やすった後写真〓

### MCU、USBコネクタ関連部品の取り付け

部品の取り付け例の写真を参考に、各部品を取り付けてください。

MCU Direction  
部品の取り付け例

MCU Direction  
MCU, クリスタルの取り付け方向

#### MCU
MCU上面の●印を、基板のマークに合わせて取り付けてください。  
取り付け後、テスターで端子がショートしていないか確認します。

#### クリスタル
クリスタルに書かれた文字の左下が、基板のマークに合うように取り付けます。  
取り付け後、テスターで端子がショートしていないか確認します。

#### コンデンサ、抵抗、リセッタブルヒューズ
これらの部品はどちら向きに取り付けてもかまいません。  
以下の記号に対応する部品を取り付けます。  

| 部品記号 | 取り付け部品 |
| ----- | ----- |
| C1 | セラミックコンデンサ 10uF 1206 |
| C2, C3 | セラミックコンデンサ 22pF 1206 |
| C4, C5, C7 | セラミックコンデンサ 0.1uF 1206 |
| C6 | セラミックコンデンサ 1uF 1206 |
| F1 | リセッタブルヒューズ<br>500mA トリップ1A 1206 |
| R5, R6 | 抵抗 10k 1206 |
| R3, R4 | 抵抗 22 1206 |

※v.0.1では、コンデンサC1とSW19のソケットが干渉する箇所があるため、コンデンサC1をMCU側へ少しずらして取り付けます。

#### リセットスイッチ
どちら向きに取り付けても大丈夫です。

#### USBコネクタ
コネクタを基板裏面から差し込み、マスキングテープなどで仮固定しておき、コネクタの足を基板の表面からはんだ付けします。

USBコネクタの取り付けに少し遊びがあるため、端子が基板のパッドの真上に来るように取り付けてください。
USB pad  
USB パッド部  
USB leg  
USBコネクタの足（基板面面）  

取り付け後、テスターで端子がショートしていないか確認します。  
端子間が狭いため、ケーブルを接続してケーブル反対側のコネクタで確認するのもひとつの方法です。

### PCやMacへの接続確認と、ファームウェアの書き込み
MCU、USBコネクタ関連部品が正常に取り付けられ、PCやMacで認識されるかを確認するため、ファームウェアを書き込みます。  
初めてUSB接続したとき、Macでは  
〓システムレポートのUSBに、Atmega???〓  
というデバイス名が表示され、ファームウェア書き込み後は、  
〓Jones？〓  
というデバイス名で表示されます。  
（Windowsでどのように認識されるか未検証です。）

ファームウェアは以下よりダウンロードし、QMK Toolboxや、QMKのmakeコマンドなどで書き込んでください。  
QMK Toolbox用hexファイル：〓
QMKコマンド用キーボード関連ファイル：〓

QMK Toolbox：
hexファイルを指定しておきます。  
キーボードのリセットスイッチを押して〓DFUなんたらメッセージ〓が表示されることを確認します。  
Flashボタンを押して書き込みます。

QMKコマンド：
ダウンロードしたファイルをQMKのkeyboardsディレクトリ配下へ配置します。  
下記コマンドを実行します。

〓not foundメッセージ〓が表示されたら、キーボードのリセットスイッチを押します。
書き込みが行われます。

### キースイッチ関連部品の取り付け

ダイオードを取り付けます。  

※v.0.1では取り付け方向のシルクがありません。  
キーボード手前側がカソード（奥→手前）になるように取り付けてください。  
〓方向の写真（引いた図に拡大したものを入れ込んで1枚に〓

スイッチソケットを取り付けます。  
使用するレイアウトに合わせて取り付けます。  
スイッチソケット非対応の箇所は、mill-maxソケットでソケット化するか、スイッチを直接はんだ付けしてください。

※v.0.1では、SW19のソケットとコンデンサC1が干渉するため、ソケットをやすりで削るなどして対処します。  
スイッチ中央穴にかからない方向で取り付けます。  
〓けずる感じ〓

スタビライザーを取り付けます。  
使いたいレイアウトに合わせて、取り付けるスタビライザーの位置を確認してください。  
〓スタビライザーの設置〓
なお、左シフトキーのスタビライザーを取り付けると、この部分はケースへネジ止めできなくなります。  
ネジ止めしなくても問題なく使用できますが、気になる方はスタビライザーを装着しないなどの工夫が必要です。  
〓ネジ干渉〓

キースイッチを取り付けます。
5pinのスイッチは差し込みが硬いことがあるため、奥までしっかりと差し込みます。

オプションのキープレートを使用する場合は、スイッチ→キープレート→基板の順に取り付け、
スイッチとキープレートがきっちりはまるようにします。
4隅のスイッチを取り付けてから、残りを1個ずつ確認しながら取り付けていくのがおすすめです。

ソケット化していない場合は、スイッチを取り付けたらはんだ付けします。

※ケースネジ穴とスイッチ”H”と”[”〓レイアウトによって”[”じゃないときがある〓の足が干渉します。
これらの箇所では、低頭ネジを使用してケースへ固定してください。
”H”キーでは、3pinのスイッチを使用するか、片方の足をカットした5pinスイッチを使用してください。
”[”キーでは、上記の対応に加え、スイッチ中央の足（でっぱり部分）をネジに当たらないよう1/4～1/3ほどカットしてください。
スイッチによっては　装着できない場合もありますので、ひとつふたつダメにするくらいの気持ちで作業してください。
足加工による取り付け確認済みスイッチ：Gateron 静音赤, Gateron 静音白, Gateron Ink Red
〓足カットしたスイッチ〓
〓低頭ネジつけてるところ〓

PCなどに接続し、正常にキー入力できるか確認します。

### オプション部品の取り付け

（オプション）LEDを取り付けます。
基板表面のLED1、LED2へ取り付けます。
※v.0.1では取り付け方向のシルクがありません。〓ないか？〓
3と書いてあるところに、LEDの▲マークを合わせます。
〓LED方向〓

（オプション）ロータリーエンコーダを取り付けます。
基板表面の〓SWxx〓へ取り付けます。
〓RE取り付け図〓

（オプション）ブロッカーを取り付けます。
ネジとスペーサーでブロッカーを取り付けます。
〓ブロッカー取り付け図〓

### ケースへ取り付けます。

基板奥側から先にケースへ入れ、USBコネクタをケースの穴に合わせるようにして、基板全体をケースに納めます。
ケースと基板のねじ穴がぴったり合うように位置を調整し、ねじ止めします。
〓シフトのネジ入らんかも〓

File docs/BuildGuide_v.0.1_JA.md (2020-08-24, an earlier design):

# Jones v.0.1 ビルドガイド

**Jones v.0.1は試作版です。**

*キーボード基板としての機能には問題ありませんが、ブロッカーのネジ位置が合わず取り付けできないものがあります。*

## 注意事項、制限など

製作にあたり、次のような注意事項、制限があります。

- 試作版のため、ブロッカーのネジ穴位置が合わず、取り付けられないものがあります。
- コンデンサC1とSW19のソケットが干渉するため、コンデンサを少しずらして設置し、ソケットを削って回避してください。
- ケースのネジ穴とスイッチの足が干渉する箇所があり、スイッチの加工が必要です。
- レイアウトによっては、スイッチソケットに非対応の箇所があります。
- 左シフトのスタビライザーが、ケース取り付けネジと干渉する場合があります。

## 部品リスト

### 基本部品

キーボードとして動作させるのに必要な部品は次の通り。

| 部品名 | 個数 |
| ----- | -----: |
| Jones 基板 | 1 |
| USBコネクタ<br>Hirose UX60SC-MB-5S8(80)| 1 |
| リセットスイッチ<br>RS-187R05A2-DS MT RT | 1 |
| リセッタブルヒューズ<br>500mA トリップ1A 1206 | 1 |
| AVRマイコン<br>ATmega32U4-AU 44TQFP 10x10mm | 1 |
| クリスタル 16MHz 3225 | 1 |
| セラミックコンデンサ 0.1uF 1206 | 3 |
| セラミックコンデンサ 10uF 1206 | 1 |
| セラミックコンデンサ 1uF 1206 | 1 |
| セラミックコンデンサ 22pF 1206 | 2 |
| 抵抗 10k 1206 | 2 |
| 抵抗 22 1206 | 2 |
| ダイオード 1N4148 SOD-123 | 64 |
| MXソケット | 最大62(\*) |
| MXスイッチ | 最大63(\*) |
| スタビライザー 2U | 最大5(\*) |

\* レイアウトによって使用数が変わります。

### オプション部品

追加機能を使用する場合に必要となる部品は次の通り。

| 部品名 | 個数 | 目的 |
| ----- | -----: | ----- |
| Mill-Maxソケット | 必要数 | MXソケット非対応箇所のソケット化 |
| LED SK6812MINI | 2 | インジケータLED |
| ロータリーエンコーダ<br>EC11、EC12互換 | 1 | ロータリーエンコーダの設置 |
| キープレート（下記参照）| 1 | キースイッチをさらにしっかりと固定 |

#### キープレート

プレートマウントの5pinスイッチを使用すればある程度しっかりと固定できますが、さらにしっかりと固定したい場合は、キープレートを使用してください。

[切断堂](https://setsudando.jp)さんの1.5mmステンレスなら、4000円程度で作成できます。（2020年8月現在）

厚さが1.5mmを超えるとキースイッチの爪が引っ掛からなくなりますが、FR-4で作成したものは実用可能です。  
他にも、MDFやアクリルでも作成できると思います。(未作成)  

キープレートは以下のデータを使用して作成できます。  
[キープレート（SVG）](../assets/keyplate_SplitSpace_Merged_14x14.svg)  
[キープレート（DXF）](../assets/keyplate_SplitSpace_Merged_14x14.dxf)

自分好みのキープレートを作成したい場合は、Keyboard Layout Editorの[Jones v.0.1](http://www.keyboard-layout-editor.com/#/gists/62a2e13a54e2d129532bc8758cfc1e79)を参照してください。

## 組み立てに必要な工具
ドライバー、ピンセット、はんだ付け関連用品など、一般的な電子工作向け工具が必要です。  
また、MCUやUSBコネクタ取り付け後の確認にテスターが必要です。

以上に加え、やすりがあると仕上がりがきれいになります。  
また、ヘッドマウント型のルーペがあると細かいはんだ付けが楽になります。

## 基板概要

### 基板 表面

左上にUSBコネクタ部分の出っ張りがあるように置いた状態が表面。

PCB front side  

### 基板 裏面

右上にUSBコネクタ部分の出っ張りがあるように置いた状態が裏面。  
裏面には、シルク印刷がたくさんあります。

PCB back side  

### ブロッカー部

基板の下部に連結されている細長い部分。

### 回路図
Jones v.0.1 schematic  

[回路図 PDF](../assets/Jones_v.0.1_schematic.pdf)  

## 組み立て手順

部品の実装は、特に記載がない限り、基板裏面へ取り付けます。  

以下の部品のみ、表面から取り付けます。
- スタビライザー
- MXスイッチ
- インジケータ用のLED
- ロータリーエンコーダ

### 基板の切り離し

ブロッカー部を切り離します。  

マウスバイトの両側を指でつまみ、折り曲げて切り離します。  

Cutting  

切り離した箇所はとがっているので、ニッパーでカットしたり、やすりで削っておきます。  

### MCU、USBコネクタ関連部品の取り付け

各部品の取り付け説明と、部品の取り付け例の写真を参考に作業してください。

MCU Direction  
部品の取り付け例

MCU Direction  
MCU, クリスタル、ダイオードの取り付け方向

#### MCU
U2へ、MCU上面の●印を、基板のマークに合わせて取り付けてください。  
取り付け後、テスターで端子がショートしていないか確認します。

#### クリスタル
Y1へ、クリスタルに書かれた文字の左下が、基板のマークに合うように取り付けます。  
取り付け後、テスターで端子（基板上のパッド）がショートしていないか確認します。

#### コンデンサ、抵抗、リセッタブルヒューズ
これらの部品はどちら向きに取り付けてもかまいません。  
以下の部品記号に対応する部品を取り付けます。  

| 部品記号 | 取り付け部品 |
| ----- | ----- |
| C1(*) | セラミックコンデンサ 10uF 1206 |
| C2, C3 | セラミックコンデンサ 22pF 1206 |
| C4, C5, C7 | セラミックコンデンサ 0.1uF 1206 |
| C6 | セラミックコンデンサ 1uF 1206 |
| F1 | リセッタブルヒューズ<br>500mA トリップ1A 1206 |
| R5, R6 | 抵抗 10k 1206 |
| R3, R4 | 抵抗 22 1206 |

\* v.0.1では、コンデンサC1とSW19のソケットが干渉する箇所があるため、コンデンサC1をMCU側へ少しずらして取り付けます。

#### リセットスイッチ
どちら向きに取り付けても大丈夫です。

#### USBコネクタ
コネクタを基板裏面から差し込み、端子が基板のパッドの真上にように位置を調整してマスキングテープなどで仮固定しておきます。  
その状態で、コネクタの足を基板の表面からはんだ付けします。

USB leg  
はんだ付けしたUSBコネクタの足（基板表面）

端子と基板のパッドがずれていないことを確認し、端子をはんだ付けします。

USB pad  
はんだ付けしたUSBコネクタの端子

取り付け後、テスターで端子がショートしていないか確認します。  
端子と端子の間隔が狭いため、ケーブルを接続してケーブル反対側のコネクタで確認するのもひとつの方法です。

### PCやMacへの接続確認と、ファームウェアの書き込み
PCやMacで認識されるかを確認するため、ファームウェアを書き込みます。  

#### 初回接続時にデバイスが認識されていることを確認する
QMK ToolboxでDFUデバイスが接続されたことを確認するか、OSの機能を使用して確認してください。

##### Mac
Jonesを初めてUSB接続したとき、システムレポートのUSBに、`Atmega32U4DFU`というデバイス名が表示されることを確認します。

なお、ファームウェア書き込み後は、`jones`というデバイス名で表示されます。  

##### Windows
どのように認識されるか未確認です。

#### ファームウェアを書き込む。

ファームウェアは以下よりダウンロードし、QMK Toolboxや、QMKのmakeコマンドなどで書き込んでください。  

- QMK Toolbox用hexファイル：[jones_v.0.1_default.hex](../assets/jones_v.0.1_default.hex)  
- QMKコマンド用キーボード関連ファイル：[qmk_firmware/keyboards/jones/](https://github.com/jpskenn/qmk_firmware/tree/master/keyboards/jones)

##### QMK Toolbox
ダウンロードしたhexファイル`jones_v.0.1_default.hex`を指定し、MCUは`atmega32u4`を選択しておきます。  
キーボードのリセットスイッチを押して、  

`*** DFU device connected`  

というメッセージが表示されたら、Flashボタンを押して書き込みます。

##### QMKコマンド
ダウンロードしたファイルをQMKのkeyboardsディレクトリ配下へ配置し、下記のコマンドを実行します。  

`make jones/v.0.1:default:dfu`  

ファームウェアが作成され、

```
dfu-programmer: no device present.
ERROR: Bootloader not found. Trying again in 5s.
```

というメッセージが表示されたら、キーボードのリセットスイッチを押すと書き込みが行われます。

### キースイッチ関連部品、オプション部品の取り付け

#### ダイオードの取り付け

※v.0.1では取り付け方向のシルクがありません。  
基板の手前側がカソード（奥→手前）になるように取り付けてください。  

Diode Direction  
ダイオード取り付け方向

#### LEDの取り付け（オプション）
基板表面のLED1、LED2へ取り付けます。  

このLEDは熱に弱いため、270℃程度で数秒内に取り付けるなどして、LEDが壊れないよう注意してください。

LED Direction  
LED2 LED1がこのように見える方向に基板を置いたとき、右下にLEDの切り欠きを合わせます。

#### スイッチソケットの取り付け
使用するレイアウトに合わせて取り付けます。  

以下に示すキーのうち、×印以外のキーレイアウトがMXソケットに対応しています。  
Socket keys

スイッチソケット非対応の箇所は、mill-maxソケットでソケット化するか、スイッチを直接はんだ付けしてください。

※SW19のソケットとコンデンサC1が干渉する場合は、ソケットをやすりで削るなどして対処します。  

#### ロータリーエンコーダの取り付け（オプション）

基板表面の右下の枠内へ取り付けます。

#### スタビライザーの取り付け
使いたいレイアウトに合わせて、取り付けるスタビライザーの位置を確認してください。  

なお、左シフトキーのスタビライザーがケースネジと干渉する場合があります。  
ネジ止めしなくても問題なく使用できますが、気になる場合はスタビライザーを装着しないなどの工夫が必要です。  

#### キースイッチ、キープレート（オプション）の取り付け

※ケース中央、ケース右上のネジ穴にキースイッチが重なるレイアウトの場合は、その部分だけケースへ取り付けた後にスイッチを取り付けます。

オプションのキープレートを使用する場合は、上から  
スイッチ → キープレート → 基板  
の順に取り付け、スイッチとキープレートがきっちりはまるようにします。
4隅のスイッチを取り付けてから、残りを1個ずつ確認しながら取り付けていくのがおすすめです。

ソケット化していない箇所は、スイッチを取り付けたらはんだ付けします。

##### ケース中央、ケース右上のネジ穴に重なるキースイッチ  

ケース中央のねじ穴に重なるスイッチは、3pinのスイッチを使用するか、片方の足をカットした5pinスイッチを使用してください。  

ケース右上のねじ穴に重なるスイッチは、上記の対応に加え、スイッチ中央の足（でっぱり部分）をネジに当たらないよう1/4～1/3ほどカットしてください。  

キースイッチの加工  
キースイッチの加工  
左：足を全てカットしたGateron Silent Red  
右：片方の足をカットしたGateron Ink Red

スイッチによっては　装着できない場合もありますので、ひとつふたつダメにするくらいの気持ちで作業してください。

#### ブロッカーの取り付け（オプション）

※v.0.1ではネジ穴の位置が合わない箇所があるため、加工が必要になります。  
M2ネジとスペーサーでブロッカーを取り付けます。  
場合によってはワッシャーなどを使用してください。

### 基板のケースへの取り付け

基板奥側をケースへ入れ、USBコネクタをケースの穴に合わせるようにして、基板全体をケースに納めます。

USBコネクタがケースの穴に入れば、基板全体がスッとケース内に入ります。  
ぐいぐいと力をかけて押し込むようなことはしません。

KBDfansのTOFUでは問題ありませんが、お安いプラスチックケースの場合は、基板がケース内のリブに干渉して、ぐらつくことがあります。  
この場合は、次の写真のように、リセットスイッチの穴とねじ穴のポストの間のリブ（○で囲んだ箇所）をカットします。  
写真では○で囲んでいない箇所もカットしてありますが、そちらのカットは不要です。

お安いプラスチックケースの加工  

ケースと基板のネジ穴が合うように位置を調整し、ネジ止めします。  
キースイッチと重なる箇所は低頭ネジを使います。

### 動作確認

最後に、キースイッチの動作確認をして完成です。

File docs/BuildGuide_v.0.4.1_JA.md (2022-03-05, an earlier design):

# Jones v.0.4.1 ビルドガイド

購入していただいた方、リポジトリから製造していただいた方、その他の皆様、Jonesに興味を持っていただきありがとうございます。

このドキュメントは、Jones v.0.4.1を組み立てるためのビルドガイドです。  
Jonesのコンセプトや特徴などについては、[Jones README](https://github.com/jpskenn/Jones/blob/master/README.md)をご覧ください。

ビルドガイド全体に目を通して作業手順を把握しておくとミスの防止につながりますので、ぜひ、一度お読みになってから組み立て作業を始めてください。

オプションのインジケータLEDの取り付け作業を除き、基本的な作業の難易度はそれほど高くありません。  
組み立て手順には要点だけが書いていますが、組み立て初心者の方や、しっかりと確認しながら組み立てたい方は、

<details>
<summary>《詳しい手順》</summary>

ここに詳しい手順が書かれています。
</details>

と書かれたところをクリックすると、追加の説明が表示されます。

**試作版のビルドガイドのため、掲載している一部の写真に最新ではないものがございます。ご了承ください。**

## 目次

<!-- @import "[TOC]" {cmd="toc" depthFrom=2 depthTo=3 orderedList=false} -->

<!-- code_chunk_output -->

- [目次](#目次)
- [Jones v.0.4.1の機能](#jones-v041の機能)
- [注意事項、制限など](#注意事項制限など)
- [部品リスト](#部品リスト)
  - [キット内容物](#キット内容物)
  - [別途用意が必要な部品](#別途用意が必要な部品)
  - [オプション部品](#オプション部品)
- [組み立てに必要な工具](#組み立てに必要な工具)
- [組み立て前の確認](#組み立て前の確認)
  - [同梱物の確認](#同梱物の確認)
  - [接続の確認](#接続の確認)
  - [ソケット用パッドの確認](#ソケット用パッドの確認)
- [組み立て手順](#組み立て手順)
  - [作りたいレイアウトを決める](#作りたいレイアウトを決める)
  - [スイッチ用ソケットの取り付け](#スイッチ用ソケットの取り付け)
  - [（オプション）インジケータLEDの取り付け](#オプションインジケータledの取り付け)
  - [（オプション）スピーカーの取り付け](#オプションスピーカーの取り付け)
  - [（オプション）ロータリーエンコーダの取り付け](#オプションロータリーエンコーダの取り付け)
  - [スタビライザーの取り付け](#スタビライザーの取り付け)
  - [スイッチの取り付け](#スイッチの取り付け)
  - [ケースへの取り付け](#ケースへの取り付け)
  - [仕上げ](#仕上げ)
- [参考](#参考)
  - [参考：1個のスピーカーで2音同時再生する](#参考1個のスピーカーで2音同時再生する)
  - [参考：打鍵感向上：ケースへの基板取り付け方法](#参考打鍵感向上ケースへの基板取り付け方法)
  - [参考：打鍵感向上：ケース内部の制振と静音化](#参考打鍵感向上ケース内部の制振と静音化)
  - [参考：打鍵感向上：キープレートと基板間のパテ埋め](#参考打鍵感向上キープレートと基板間のパテ埋め)
  - [参考：USBコネクタ接続図](#参考usbコネクタ接続図)
  - [参考：スピーカーの2音同時再生](#参考スピーカーの2音同時再生)
  - [参考：正常に入力できないスイッチの原因調査](#参考正常に入力できないスイッチの原因調査)
  - [参考：LEDの取り付け不良調査](#参考ledの取り付け不良調査)
  - [参考：ファームウェアの書き込み方法（QMK Toolboxで書き込む）](#参考ファームウェアの書き込み方法qmk-toolboxで書き込む)
  - [参考：ファームウェアの書き込み方法（コマンドを使って書き込む）](#参考ファームウェアの書き込み方法コマンドを使って書き込む)
  - [参考：EEPROMを消去し、初期状態に戻す方法](#参考eepromを消去し初期状態に戻す方法)

<!-- /code_chunk_output -->

## Jones v.0.4.1の機能

- 主要な部品を実装済み  
  はんだ付けが必要な部品は、MXソケットとオプションパーツのみ。

- 対応レイアウト
  [Keyboard Layout Editor: Jones v04_1](http://www.keyboard-layout-editor.com/#/gists/5c8ac0bbee831ac1463e579fabf9d351)

- ファームウェア  
  RemapやVIAなどのキーマップ書き換えツールに対応したファームウェアを書き込み済み  
  [develop_jones:v04_1](https://github.com/jpskenn/qmk_firmware/tree/develop_Jones/keyboards/jones/v04_1)  

- 外部EEPROM（8KB）を搭載  
  書き込み済みのファームウェアで利用可能

- ケース
  - GH60型やPoker型に互換性のあるケース
  - Jones用ボトムプレートキット

- レイヤーインジケータLED（オプション）

- ロータリーエンコーダ（オプション）

- スピーカー（オプション）

## 注意事項、制限など

- キースイッチ取り付け時の加工

  GH60型, Poker型ケースを使用する場合、ケースのネジ穴とスイッチ足の干渉を避けるため、スイッチの足を加工して取り付けます。

  - 中央ネジ穴に重なるスイッチ
  - 右上ネジ穴に重なるスイッチ（Narrowレイアウトを使用する場合のみ）

- キースイッチの取り付け方向

  一部のキーは上下逆向きや横向きに取り付けるため、キーキャップが取り付けにくかったり、キーキャップとスイッチが干渉し打鍵感が悪くなることがあります。

- 左シフトキー

  左シフトキーの2Uスタビライザーは、ケースネジに干渉するため使用を避けてください。

- スピーカー

  スピーカーは、左シフトキーが1.75uまたは2uの場合にのみ取り付けることができます。

- ケースネジ

  中央下のネジはキースイッチやスタビライザーと干渉するため、ねじ止めせずに使用します。

- ケース

  GH60型, Poker型に対応する基板とキープレートですが、もしかしたら取り付けできないケースがあるかもしれません。  
  取り付け確認済みのケースは次の通りです。  
  （これら以外のケースへの取り付けの成功／失敗の報告を募集しております。）
  - [KBDfans TOFU 60% ALUMINUM CASE](https://kbdfans.com/products/kbdfans-tofu-60-aluminum-case)
  - [KBDfans 5° FROSTED ACRYLIC CNC 60% CASE](https://kbdfans.com/products/pre-order-kbdfans5-transparent-acrylic-cnc-60-case)
  - [60% プラスチックケース](https://yushakobo.jp/shop/60-plastic-case/)（簡単な加工が必要）

  木製のケースは、ケースの内部構造が基板うら側のソケットやスタビライザーに干渉するものが多いため、注意してください。  
  ケース内部の外周部に数ミリ幅の段があり、基板を支えるような構造がこれに該当します。  
  カッターや彫刻刀で干渉箇所を削れば取り付けできますが、ひと手間かかる加工作業になります。  
  - [60% 竹製ケース（パームレスト一体型）](https://shop.yushakobo.jp/products/a0700bp-01)  
  Lekipon様より[ご報告](https://twitter.com/lekipon/status/1439607642431754250)をいただきました。  
  Dropで販売されている[NPKC 60% WOODEN WRIST REST KEYBOARD CASE](https://drop.com/buy/npkc-60-percent-wooden-wrist-rest-keyboard-case)も同じ形状で、干渉すると思われます。
  - [60% 木製ケース](https://shop.yushakobo.jp/products/60-wood-case)  
  竹製ケースと同じような内部構造で、写真で見ると干渉は少なめですが、注意が必要です。
  - その他の木製ケース

## 部品リスト

このキットを組み立てるためには、”キット内容物”に加え、”別途用意が必要な部品”が必要です。  
好みに合わせて必要な数をお買い求めください。

”オプション部品”は使いたい機能などに合わせて用意してください。  

部品の購入先は、Self-Made Keyboards in Japanの[ショップリスト](https://scrapbox.io/self-made-kbds-ja/ショップリスト)などを参考にしてください。

### キット内容物

| 部品名 | 個数 | 備考 |
| ----- | :-----: | ----- |
| ご案内リーフレット | 1 | |
| Jones 基板 v.0.4.1 | 1 | [おもて側<br>基板おもて側](../assets/BuildGuide_v.0.4/_DSF0124.jpeg)<br>[裏側<br>基板裏側](../assets/BuildGuide_v.0.4/_DSF0120.jpeg) |
| Jones キープレート v.4.0.2 | 1 | [おもて側<br>キープレートおもて側](../assets/BuildGuide_v.0.4/_DSF0131.jpeg)<br>[裏側<br>キープレート裏側](../assets/BuildGuide_v.0.4/_DSF0132.jpeg) |
| Kailh MXソケット | 75(予備含む) | [MXソケット](../assets/BuildGuide_v.0.4/_DSF0133.jpeg) |
| PCBマウント スタビライザー<br>2uサイズ, ねじ止め式 | 2 | [](../assets/BuildGuide_v.0.4/_DSF0432_0.jpeg)<br>2.25uのキーにも使用できます。 |
| 低頭ネジ, M2 4mm | 3(予備含む) | [](../assets/BuildGuide_v.0.4/_DSF0432_1.jpeg) |
| 低頭ネジ, M2 5mm | 3(予備含む) | [](../assets/BuildGuide_v.0.4/_DSF0432_2.jpeg) |
| プラ板 | 1 | [](../assets/BuildGuide_v.0.4/_DSF0432_3.jpeg) <br>LEDインジケータ取り付け時のみ使用。|

※出荷時期によってメーカーや品番、色などが変わることがあります

### 別途用意が必要な部品

| 部品名 | 個数 | 備考 |
| ----- | :-----: | ----- |
| MXスイッチ | 最大 70 | 取り付け安定性が高い5pinタイプを推奨。<br>スイッチの端子折れや故障した場合に備えて、いくつか予備があると安心。 |
| キーキャップ<br>MXスイッチ用 | 必要数 | Wide, Normalレイアウトは、一般的な日本語108または英語104のキーキャップセットに対応。<br>Narrowレイアウトはカスタムキーキャップセットが必要。|
| PCBマウント スタビライザー<br>2uサイズ | 必要数 | キット付属の2個では足りない場合に必要。<br>確実に固定できるねじ止め式を推奨。 |
| GH60型, Poker型ケース<br>または<br>Jones用ボトムプレートキット(\*) | 1 | |
| USBケーブル （Type-C） | 1 | |

\* Jones用ボトムプレートキットの内容物は次の通り
| 部品名 | 個数 | 備考 |
| ----- | :-----: | ----- |
| ご案内リーフレット | 1 ||
| Jones用ボトムプレート | 1 | [おもて側<br>ボトムプレートおもて側](../assets/BuildGuide_v.0.4/_DSF0127.jpeg)<br>[裏側<br>ボトムプレート裏側](../assets/BuildGuide_v.0.4/_DSF0129.jpeg) |
| スペーサー, M2 3mm | 8 | [](../assets/BuildGuide_v.0.4/_DSF0435_0.jpeg) |
| ネジ, M2 3mm | 16 | [](../assets/BuildGuide_v.0.4/_DSF0435_1.jpeg) |
| ネジ, M2 3mm, 低頭 | 1 | [](../assets/BuildGuide_v.0.4/_DSF0435_2.jpeg) |
| ゴム足 大 | 2 | [](../assets/BuildGuide_v.0.4/_DSF0435_3.jpeg) |
| ゴム足 小 | 6 | [](../assets/BuildGuide_v.0.4/_DSF0435_4.jpeg) |

※出荷時期によってメーカーや品番、色などが変わることがあります

### オプション部品

| 部品名 | 個数 | 備考 |
| ----- | :-----: | ----- |
| LED<br>SK6812MINI | 最大 4 | 左側2個、右側2個、または左右両側4個。 |
| ロータリーエンコーダ<br>ALPS EC11, ALPS EC12またはその互換品 | 最大 2 | 左側1個、右側1個、または左右両側2個。 |
| ロータリーエンコーダ用ノブ（つまみ）| 最大 2 | ロータリーエンコーダの軸の形状に合ったもの。 |
| スピーカー<br>Murata PKMCS0909E4000-R1 | 1 | |

## 組み立てに必要な工具

先の小さなドライバー、ピンセット、はんだ付け関連用品など、一般的な電子工作向け工具を使用します。  
[遊舎工房の工具セット](https://yushakobo.jp/shop/a9900to/)を参考に用意してください。

また、キースイッチの取り外し用の工具も用意してください。  
[TALP KEYBOARDで売っているこのタイプ](https://talpkeyboard.net/items/601362fe2438601925ad0692)は、1本でキースイッチとキーキャップの両方に使えるので便利です。

なお、無くても組み立てはできますが、何か不具合があった場合の原因調査ではテスターが必要になることがあります。

## 組み立て前の確認

組み立てを開始する前に、同梱物と基板についての基本的な確認をおこないます。  
何か問題があった場合は作業を中止し、キット同梱のリーフレットに記載された連絡先へ問い合わせてください。

*組み立て手順の開始後は初期不良として対応できかねる場合がありますので、しっかりと確認してください。*

### 同梱物の確認

- 同梱物に不足がないこと

- 基板に配線が切れるような大きく深い傷や割れなどの破損がないこと

- 梱包の中に小さな部品が落ちていないこと（＝基板に実装された部品が外れていないこと）

### 接続の確認

MacやPCに接続した際に、キーボードとして認識されるかを確認します。

ファームウェアを書き込み済みですので、正常であれば、USBケーブルで接続するとキーボードとして認識されます。  
下記のOS別の確認方法を参考に、確認してください。

<details>
<summary>《Mac, macOS Big Sur 11.4》</summary>

*充電用ではないUSBケーブル（できれば他の機器を接続して使用した実績のあるもの）*を使って、キーボードとMacをUSB接続します。

`キーボード設定アシスタント`が表示されることがありますが、この段階ではキーを押すことができないため、そのまま放っておくか、閉じるボタンで閉じておきます。  
後で`キーボード設定アシスタント`を使いたくなったときは、`システム環境設定` → `キーボード`と進み、`キーボード`タブ内の`キーボードの種類を変更…`ボタンで呼び出すことができます。

キーボード設定アシスタント  
キーボード設定アシスタント

メニューバーから、``　→　`このMacについて`を選び、表示された画面で`システムレポート…`をクリックします。  
システム情報が表示されたら、左側の`ハードウェア`から`USB`を選択します。

右側の`USB装置ツリー`のどこかに`Jones`というデバイスが表示されていれば、正しく認識されています。  
`USB装置ツリー`の下の方が見切れている場合があるため、スクロールして確認してください。

Mac System Report  
システム情報の表示
</details>

<details>
<summary>《Windows, 10 Pro 1909(18363.1082)》</summary>

*充電用ではないUSBケーブル（できれば他の機器を接続して使用した実績のあるもの）*を使って、キーボードとPCをUSB接続します。

`スタートボタン`から`設定`を開いて`デバイス`を選択し、  
`マウス、キーボード、ペン`の項目に`Jones`が表示されていれば、正しく認識されています。

Windows Devices  
デバイスの表示
</details>

### ソケット用パッドの確認

キースイッチのソケットをはんだ付けするソケット用パッド（ソケットをはんだ付けする基板上の金属部分）が、電気的に正しく反応することを確認します。  
全てのパッドを確認しなくてもかまいませんが、少なくとも組み立てようとしているレイアウトのパッドが正しく反応することは確認しておいてください。

レイアウトを画面に表示させて確認できるのでキーマップ書き換えツール[Remap](https://remap-keys.app/)のテスト機能を使う方法がおすすめですが、OSのキーボードビューアや[Keyboard Checker](https://keyboardchecker.com)、[QMK Configrator](https://config.qmk.fm/)のキーボード入力テストを使用して確認することもできます。  
VIAを使用する際は、[この定義ファイル（jones_v04_1_VIA_definition.json）](https://gist.github.com/jpskenn/db13901f72a58f6757ae0baf57bfa7ee)を読み込ませてください。

<details>
<summary>《詳しい手順》</summary>

キーマップ書き換えツール[Remap](https://remap-keys.app/)のテスト機能を使い、確認を行います。

基板の裏面が上側になるように置き、PCやMacとUSBケーブルで接続します。

Google Chromeブラウザ（Web HID対応のバージョン89以降）で、[Remap](https://remap-keys.app/)を開きます。

`START REMAP FOR YOUR KEYBOARD`をクリックしてキーボード接続画面に進みます。

START REMAP FOR YOUR KEYBOARD

`+ KEYBOARD`をクリックしてデバイスへの接続要求画面を開きます。

+ KEYBOARD

デバイスへの接続要求画面で`Jones`を選択して`接続`をクリックすると、画面にキーボードのレイアウトが表示されます。

デバイスへの接続要求

レイアウト右側の`Layout Option`で、組み立てようとしているレイアウトに設定します。  
キーマップは組み立て完了後に変更するため、ここではレイアウトだけ設定して先へ進みます。

```aside
Layout Optionの、
Right R2とRight R3の、Narrow, 1.25u
は、v.1で追加されたレイアウトです。

v.0.4.1では、このレイアウトに対応していません。
```

Layout Option

レイアウト右側の`…`をクリックし、`Test Matrix mode`を選択します。

Test Matrix Mode

ピンセットなどの電気を通すものを使い、基板裏面のソケット用パッドをショートさせます。


ピンセットを使ってパッド部分をショートさせる様子

Remapの画面で、ショートさせたパッドに対応するキーの色が変わることを確認します。  

キーの色が変わる

ソケット用パッドを順にショートさせ、全てのキーの色が変わることを確認します。  
なお、ロータリーエンコーダの回転に割り当てた箇所は、この手順では確認しません。
</details>

余裕があれば、すべてのレイアウトでも同様に確認します。

確認が終わったら、USBケーブルを抜きます。

## 組み立て手順

以下の手順に沿って組み立ててください。  
工具類や部品による怪我や、はんだ作業での火傷などに気をつけてください。

### 作りたいレイアウトを決める

Jonesのレイアウトは、大きく分けて次の3つから選ぶことができます。  

- Wide（ワイド）レイアウト

  右手ホームポジションを右側へずらしてModキーに近づけ、キーボード中央に2キー分の間隔をもたせたレイアウトです。  

- Narrow（ナロー）レイアウト

  右側Modキーをキーボード中央側へずらし、ホームポジションに近づけたレイアウトです。  

- Normal（ノーマル）レイアウト

  一般的な英語配列や日本語配列とほぼ同じになるように調整したレイアウトです。

Wide, Normalレイアウトは、一般的な日本語108または英語104のキーキャップセットで組み立てられます。  
Narrowレイアウトの組み立てには、カスタムキーキャップセットが必要です。  

レイアウトをまとめた[Keyboard Layout Editor: Jones v04_1](http://www.keyboard-layout-editor.com/#/gists/5c8ac0bbee831ac1463e579fabf9d351)を参考に、どのレイアウトを作るか決めてください。  

### スイッチ用ソケットの取り付け

基板裏側へソケットを取り付けます。

#### 取り付け位置の確認

使用するレイアウトに合わせて、基板裏側のソケットの取り付け位置を確認します。  

**v.0.4.1の基板において、左Ctrlのサイズ表記に間違いがあります。  
正しくは、上が1.25u、下が1.5uです。**
左Ctrlのサイズ表記が逆

<details>
<summary>《詳しい手順》</summary>

基板にはソケットの枠が描かれており、1uよりも大きなキーと、ソケットが重なる箇所に適合キーサイズ（1uや2uなど）が表記されています。  
また、キーサイズの表記に`N`がついてものはNarrowレイアウトのみで使用するキーを意味していますので、それらの表記を参考に取り付け位置を確認します。  
わかりにくいときは、実際にスイッチやキーキャップを置いてみるとよいでしょう。  

ソケット取り付け位置の表記
ソケット取り付け位置の表記
</details>

#### ソケット用パッドの予備はんだ

先ほど確認したソケット用パッドの*片方だけ*に、予備はんだ（はんだをちょっとつけておく）します。

<details>
<summary>《詳しい手順》</summary>

はんだごてを320℃程度に設定します。

利き手にはんだごて、もう一方の手にはんだを持ちます。

パッドにこて先をあてて、1、2と数えて加熱します。

こて先にはんだをあてて溶かし、  
溶けたはんだがパッド全体に広がったらはんだを離し、  
続いてこて先をパッドから離します。
</details>

ソケット用パッドへの予備はんだ
左：仮置きしたソケット  
右：ソケット用パッドへの予備はんだ  

#### ソケットの仮置き

ソケットを基板に描かれた枠に合わせ、プラスチックの突起が穴にはまるように仮置きします。

この段階では、ソケットの片方の端子が予備はんだの上に乗り、基板から少し浮いて傾いた状態になります。

*基板の製造ロットによっては、一部の穴が小さい（狭い）ことがあります。*  
*プラスチックの突起を穴に合わせ、ソケットを指で押してはめ込んでください。*

ソケットの方向
左：正しいソケットの方向  
右：間違い（スイッチ中央の穴をふさいでいる）

#### 予備はんだした端子のはんだ付け

予備はんだした端子をはんだ付けします。

<details>
<summary>《詳しい手順》</summary>

はんだごてを320℃程度に設定します。

利き手にはんだごて、もう一方の手にピンセットを持ちます。

ピンセットでソケット中央のプラ部分を押さえ、端子の隙間にこて先を押し込みます。

金属部分へコテ先を押し込む
金属部分へコテ先を押し込む

1、2と数えたくらいで予備はんだが溶け始めます。  
ソケットを押さえていたピンセットを軽く押し込むと、ソケットのプラスチックの突起が基板の穴にはまり、浮いていた端子が基板に接します。

端子とパッドをしっかりと加熱するため、端子が基板に接してから、1、2と数えてこて先を離します。  
さらに1、2と数えて、はんだが冷えて固まるのを待ってから、ソケットを押さえていたピンセットを離します。
</details>

ソケットが枠に沿ってまっすぐに取り付けられ、傾いていないことを確認します。  
傾いている場合は端子部分を再加熱し、こて先とピンセットで傾きを修正します。

#### 残りの端子のはんだ付け

残りのもう一方の端子をはんだ付けします。

<details>
<summary>《詳しい手順》</summary>

利き手にはんだごて、もう一方の手にはんだを持ちます。

残りの端子の隙間にこて先を押し込み、1、2と数えて加熱します。

次の手順を、1、2、3、4と数える間におこないます。

1、基板のパッドと端子の隙間あたりへはんだを押しつけます。  
2、はんだを溶かしながら隙間へ流し込みます。  
3、溶けたはんだがパッド全体に広がる程度まで流し込んだら、はんだを離します。  
4、ソケットを動かしてしまわないよう、静かにこて先を離します。

はんだがパッド全体に広がり、端子の間にポコっと盛り上がって固まっているのが良好な状態です。
</details>

取り付けたソケット
取り付けたソケット

ソケットが枠に沿ってまっすぐに取り付けられていることを確認します。  
また、ソケットのプラスチックの突起が基板の穴にぴったりとはまり、基板から浮いていないことを確認します。  

浮いたソケット
右端：基板から浮いているソケット

#### すべてのソケットの取り付け

作業を繰り返して、すべてのソケットを取り付けます。

取り付けが終わったら、**はんだ付けし忘れた箇所がないか、十分に確認します**。

特に”残りの端子のはんだ付け”を忘れることがよくあるため、この段階でよく確認しておきます。

### （オプション）インジケータLEDの取り付け

*インジケータLEDを使用しない場合、この手順は不要です。*

#### インジケータLEDの組み合わせとジャンパの設定

LED未使用も含め、4通りの組み合わせがあります。  

| 組み合わせ | 左側<br>LED1, 2 | 右側<br>LED3, 4 | ジャンパ<br>Left LEDs | ジャンパ<br>Right LEDs |
| :--: | :--: | :--: | :--: | :--: |
| LED未使用 | なし | なし | 不要 または Off | 不要 または Off |
| 左側のみ | あり | なし | On | 不要 または Off |
| 右側のみ | なし | あり | Off | On |
| 左右両方 | あり | あり | On | On |

#### ジャンパをおこなう

基板裏側のジャンパ`Right LEDs`と`Left LEDs`を、インジケータLEDの組み合わせに応じて`On`または`Off`にジャンパ（隣同士のパッドにはんだをつけてつなげる）します。  
`不要 または Off`となっている箇所は、ジャンパしなくてもかまいません。

LEDジャンパ箇所
LEDジャンパ箇所

<details>
<summary>《詳しい手順》</summary>

3個あるパッドのうち、中央と`On`の2個、または中央と`Off`の2個を同時に温め、  
こて先にはんだを押し付けて、たっぷり目に溶かし、  
こて先を、基板をなでるようにスッと横へずらしてパッドから離し、2個のパッドをはんだでつなげます。

最初のうちはうまくつなげられないことが多いですが、はんだをチョンチョンとつけたりしていると、そのうちつながります。  
はんだをつけすぎて、3個あるパッドがすべてつながってしまわないように気をつけてください。
また、パッドをこて先でグリグリいじりすぎると基板から剥がてしまうため、こて先はパッドにそっと乗せて温めて、スッと横へずらすだけにしてください。
</details>

Left LEDsをOnにジャンパ
Left LEDsをOnにジャンパにした状態

#### LED用パッドの予備はんだ

基板おもて側から、インジケータLEDの組み合わせに応じたLEDの取り付け場所へ予備はんだします。

<details>
<summary>《詳しい手順》</summary>

LED1個につき4箇所のパッドがあり、そのうち*1箇所だけ*に予備はんだします。  
スイッチソケット用のパッドに比べてLEDのパッドはとても小さいため、はんだをつけすぎないようにします。
</details>

LED用パッドの予備はんだ
LED1のLED用パッド4箇所のうち、右上へ予備はんだした状態

#### LEDの仮固定

予備はんだした箇所へ。LEDを仮固定します。

<details>
<summary>《詳しい手順》</summary>

LEDの1箇所だけ欠けた角が、基板に描かれた▲マークに合うように、LEDを基板に置きます。  
この段階では、LEDが予備はんだした箇所に乗り、基板から少し浮いています。


LED取り付け方向。基板に描かれた▲マークと、LEDの方向、

LEDは高温ではんだ付けすると壊れるため、こて先温度を220-270℃に設定します。  
220℃の方が安心ですが、加熱不足によるはんだ不良（表面上ははんだ付けされたように見えるが、内部はしっかりとくっついていない状態）になりやすいので注意してください。  
[加熱不足による、はんだ不良の例](https://twitter.com/jpskenn/status/1291328876283478016)

フラックスを予備はんだに塗っておくと、作業しやすくなります。

ピンセットでLEDをつまみ、位置がずれないように保持します。

はんだごてのこて先を、LEDの横方向からパッドとLEDの端子にあてて、予備はんだを溶かします。  
こて先温度を220℃に設定したときは、はんだが溶けるまでに少し時間がかかります。

予備はんだが溶けたら、LEDが設置位置の中心になるように微調整し、1、2と数えてこて先を離します。  
さらに1、2と数えて、はんだが固まったらLEDをつまんでいたピンセットを離します。  

はんだが、直径0.5-1mmくらいの小さな球のようになっていれば良い仕上がりです。

LEDの取り付け位置が大きくずれていたり基板から浮いている場合は、はんだ付けした箇所を再加熱し、ピンセットで修正します。  
再加熱する際も、フラックスを塗っておくと作業がしやすくなります。
</details>

仮固定したLED
仮固定したLED

#### LEDの取り付け

残り3箇所のパッドをはんだ付けし、LEDを取り付けます。

<details>
<summary>《詳しい手順》</summary>

次の順番で残り3箇所のパッドをはんだ付けします。

1. 予備はんだしたパッドとLEDの発光部を挟んだ反対側のパッド

1. 1の隣のパッド

1. 残ったパッド（予備はんだしたパッドの隣）

残り3箇所の、はんだ付け順序
残り3箇所の、はんだ付け順序

フラックスを残り3箇所のパッドに塗っておくと、作業しやすくなります。

はんだをこて先にあてて溶かし、少量のはんだをこて先につけます（乗せます）。

こて先をパッドとLED側面の端子に軽く押しあて、こて先につけておいたはんだをパッドと端子にもつけます。  
押し当てるだけではんだがつくので、こて先は動かしません。

1、2と数えてこて先を離します。
</details>

取り付けたLED
取り付けたLED

作業を繰り返し、必要な数のLEDを取り付けます。

#### LEDの動作確認

LEDの動作確認のため、次の3箇所へ一時的にスイッチを取り付けます。  

- `左シフト`キー（むらさき）
- `左スペース`キー（みどり）
- `右スペース`キー（あお）

レイアウトによって取り付ける位置が少し変わるため、図を参考に取り付けてください。

LEDテスト用スイッチ取り付け箇所
LEDテスト用スイッチ取り付け箇所

3箇所に取り付けたスイッチ
3箇所に取り付けたスイッチの例（Wideレイアウト：左シフト2u, 左スペース2.25u, 右スペース2u）

USBケーブルを接続します。

以下のように、スイッチの状態に応じてLEDが点灯することを確認します。  
LEDを左右両方に取り付けている場合も、左側と右側で同じ光り方になります。

| スイッチの状態 | LEDの点灯<br>手前, 奥 | 備考 |
| :-- | :--: | :-- |
| 何も押さない | 白, 白 | |
| `左スペース`を押し続ける | 白, 緑 | |
| `右スペース`を押し続ける | 白, 水 | |
| `左スペース`と`右スペース`を押し続ける | 白, 赤 | |
| `左スペース`と`右スペース`を押しながら`左シフト`を押し、<br>すべてのスイッチから手を離す | 紫, 白 | 操作するたびに”白, 白”と”紫, 白”が切り替わる。|

確認が終わったら、USBケーブルを抜き、スイッチを取り外します。

光らないLEDがある場合は、[参考：LEDの取り付け不良調査](#参考：LEDの取り付け不良調査)を参考にして調査します。

#### （オプション）LEDディフューザーの取り付け

*ディフューザーを使用しない場合、この作業は不要です。*

キープレートのLED窓部分にプラ板をディフューザーとして取り付け、LEDの視認性を向上させることができます。

LED窓部分
LED窓部分

LED窓の大きさに合わせて、プラ板を切り取ります。  
キープレートへ貼り付けるための、のりしろを残した大きさにします。

切り取ったプラ板
切り取ったプラ板

両面テープなどでキープレートへ貼り付けます。

プラ板貼り付け前・後
プラ板貼り付け前・後

### （オプション）スピーカーの取り付け

*スピーカーを使用しない場合、この作業は不要です。*  
*なお、スピーカーは、左シフトキーが1.75uまたは2uの場合にのみ取り付けることができます。*

実験的ですが、1スピーカーで2音同時再生する機能を有効にしたい方は以下を参考にしてください。

- [参考：1個のスピーカーで2音同時再生する](#参考：1個のスピーカーで2音同時再生する)

#### スピーカーの取り付け

基板おもて側、`Speaker`と書かれた枠内へスピーカーを取り付けます。  
スピーカーの端子に極性はないため、どちらの方向に置いてもかまいません。

スピーカー取り付け箇所
スピーカー取り付け箇所

<details>
<summary>《詳しい手順》</summary>

2箇所のパッドうち、1箇所だけに予備はんだします。

スピーカーを枠とパッドに合わせて置きます。

スピーカー上面の小さな穴が、左方向になるように取り付けるとキープレートの枠から音が抜け、聞こえやすくなります。

予備はんだした箇所の端子をはんだ付けします

スピーカーが枠に沿ってまっすぐに取り付けられていることを確認します。

残りの1箇所をはんだ付けします。
</details>

取り付けたスピーカー
取り付けたスピーカー

#### スピーカーの動作確認

USBケーブルで接続した際、`♪ピッ`という音が聞こえることを確認します。

確認が終わったら、USBケーブルを抜きます。

音が聞こえない場合は、スピーカーが正しくはんだ付けされているか確認します。

### （オプション）ロータリーエンコーダの取り付け

*ロータリーエンコーダを使用しない場合、この作業は不要です。*

#### ロータリーエンコーダの取り付け

基板おもて側の右下と左下のどちらか一方、または両方へ、からロータリーエンコーダ（ALPS EC11, ALPS EC12とその互換品）を取り付けます。  
ノブは、キープレートと基板を組み合わせた後に取り付けます。

ロータリーエンコーダ取り付け箇所
ロータリーエンコーダ取り付け箇所

取り付け確認済みのロータリーエンコーダは次の通りです。

- ALPS
  - EC11E09244AQ
  - EC11E153440D
  - EC11E18244AU
  - EC12E24204A2
- Bourns
  - PEC11R-4315F-S0012
  - PEC11R-4015F-S0024

<details>
<summary>《詳しい手順》</summary>

ロータリーエンコーダのピン（上3本または上下5本）と、左右の固定足を、基板の設置位置に合わせて差し込みます。  
固定足が差し込みにくいときは、足を横から少し押さえ、先端を基板の穴に入れます。  

左右の固定足である程度しっかりと基板に固定されるはずですが、固定がゆるく、基板から外れたり浮いたりする場合はマスキングテープなどで仮固定します。

基板を裏側が上になるように置き、いずれかのピンを*1本だけ*はんだ付けします。

ロータリーエンコーダが基板に描かれた枠に沿ってまっすぐ取り付けられていることを確認します。

ロータリーエンコーダが基板から浮かないように気をつけながら、残りのピンをはんだ付けします。
</details>

取り付けたロータリーエンコーダ（基板おもて側）
取り付けたロータリーエンコーダ（基板おもて側）

取り付けたロータリーエンコーダ（基板裏側）
取り付けたロータリーエンコーダ（基板裏側）

#### ロータリーエンコーダの動作確認

USBケーブルを接続し、ロータリーエンコーダのつまみを左右に回すとOSの音声出力ボリュームが変化することを確認します。  
また、プッシュボタンスイッチ付きのロータリーエンコーダでは、プッシュするとOSの音声出力のミュート状態が切り替わることを確認します。

何か問題があった場合は、正しくはんだ付けされているかを確認してください。

### スタビライザーの取り付け
〓左SPCはねじ止め式を推奨
#### スタビライザーの取り付け位置の確認

使用するレイアウトに合わせて、基板おもて側のスタビライザー取り付け位置を確認します。  
なお、左シフトキーの2uスタビライザーは、ケースネジに干渉するため使用を避けてください。

スタビライザー取り付け箇所
スタビライザー取り付け箇所（左下は2uキーと2.25uキーが並んでいる）

#### スタビライザーの組み立て

必要な数のスタビライザーを組み立てます。

<details>
<summary>《詳しい手順》</summary>

次のようにスタビライザーを組み立てます。  

大きいプラパーツの下側から、小さいプラパーツの切り欠きの位置を合わせて差し込みます。  

金属の棒の先を、大きいプラパーツの穴を通して、小さいプラパーツの溝へ差し込みます。  

金属の棒を、プラ部分の爪へパチンとはめ込みます。  

反対側も同じ方法で組み立てます。

../assets/BuildGuide_ v.0.4/Stab_assemble.jpeg
スタビライザーの組み立て（[拡大](../assets/BuildGuide_v.0.4/Stab_assemble.jpeg)）

</details>

#### スタビライザーの基板への取り付け

基板おもて側から、スタビライザーを取り付けます。

<details>
<summary>《詳しい手順》</summary>

スタビライザーの棒がある方の突起部分を、大きい方の穴に斜めに差し込んで引っ掛けます。  
スペースキーとそれ以外のキーのスタビライザーは、上下を逆向きに取り付けるため注意してください。

大きい方の穴に引っ掛けたスタビライザー
大きい方の穴に引っ掛けたスタビライザー

スタビライザーの反対側のねじ止めする部分を、小さい方の穴にはめ込んでねじ止めします。

ねじ止めしたスタビライザー
ねじ止めしたスタビライザー
</details>

取り付けたスタビライザー
取り付けたスタビライザー

### スイッチの取り付け

スイッチを、キープレートを介して基板に取り付けます。

打鍵感向上に興味のある方は、次の項目をお読みになると何かヒントがあるかもしれません。

- [参考：打鍵感向上：キープレートと基板間のパテ埋め](#参考：打鍵感向上：キープレートと基板間のパテ埋め)

#### スイッチ取り付け前の確認

スイッチの端子を見て、折れたり、曲がったりしていないことを確認します。  
少しだけ曲がっているものは、まっすぐに戻します。

スイッチの端子
スイッチの端子（左から順に、曲がり、正常、曲がり）

折れてしまっているものは使用できません。  
また、大きく曲がっているものは、まっすぐに戻しても折れやすくなっているため、使用を避けた方がよいでしょう。

#### キープレートの仮固定

キープレートの4隅に仮固定用のスイッチをはめ込んでから、基板へ取り付けます。  

<details>
<summary>《詳しい手順》</summary>

キープレートをおもて側が上になるように置きます。

使用するレイアウトに合わせ、キープレートの4隅にスイッチをはめ込みます。  
ロータリーエンコーダを取り付けている場合は、その隣へはめ込みます。

スイッチの取り付け方向がソケットの方向に合うようにしてください。  
例えば、左上のキーは上下逆向きにはめ込みます。

キープレート4隅につけたスイッチ
キープレート4隅につけたスイッチ

スイッチがキープレートの枠にぴったり密着してはまっていることを確認します。

スイッチのキープレートへのはまり具合（異常）
スイッチのキープレートへのはまり具合（異常）

スイッチのキープレートへのはまり具合（正常）
スイッチのキープレートへのはまり具合（正常）

基板を表側が上になるように置きます。

4隅にスイッチをはめ込んだプレートを基板に乗せ、スイッチの端子とソケットの位置を合わせます。
スタビライザーを取り付けているときは、キープレートの枠にはまるように位置を調整します。

キープレートの枠にはまったスタビライザー
キープレートの枠にはまったスタビライザー（Wideレイアウトの例）

4隅のスイッチを、1個ずつ基板のソケットに押し込んでいきます。  
スイッチの端子が奥まで差し込めるように、基板裏側のソケットを押さえながら、少しだけ力を入れて（\*）スイッチを押し込みます。  
※：洗濯バサミをつまんで開くよりも、もう少し強いくらいの力。

スイッチを押し込む様子
スイッチを押し込む様子
</details>

キープレートを基板に仮固定
キープレートを基板に仮固定

#### （該当者のみ）ケースネジ穴に干渉するスッチの取り付け

*GH60型, Poker型ケースを使用しない場合、この手順は不要です。*

GH60型, Poker型ケースのネジ穴とスイッチ足の干渉を避けるため、スイッチの足を加工して取り付ける箇所があります。  



##### 中央ネジ穴に重なるスイッチ

すべてのレイアウトにおいて、中央ネジ穴に重なるスイッチ（Gの右隣）は、スイッチの足を加工して取り付けます。

5pinスイッチは、中央ネジ穴と干渉する片方の足を、ニッパーなどで切断して取り付けます。  

3pinスイッチは干渉しないため、そのまま取り付けできます。


5pinスイッチの片方の足を切断

##### 右上ネジ穴に重なるスイッチ

Narrowレイアウトを使用する場合のみ、右上ネジ穴に重なるスイッチ（上から2行目、右から2番目）の足を加工して取り付けます。

ケースによってネジ穴サイズの大小が異なりスイッチとの干渉具合が変わってくるため、現物合わせで作業してください。

5pinスイッチ、3pinスイッチのいずれも、スイッチ中央の足（出っ張り）を、ネジ穴に当たらない程度に一部切断して取り付けます。  
中央の足をすべて切断しても良いですが、スイッチ固定の安定性が下がるため、1/4〜1/3に切り込みを入れて一部だけ切断する方がおすすめです。


中央の足の1/4くらいに切り込みを入れる


切り込みを入れたところまで切断する

なお、押下時にスイッチの軸がネジに当たる場合は、軸の下端を少しだけ切断します。

軸の下端を切断
軸の下端を切断（上：切断後, 下：切断前）

#### 残りのスイッチの取り付け

スイッチの取り付け方向をソケットの方向に合わせて、残りのスイッチを取り付けます。

ロータリーエンコーダを使用する場合は、ノブを取り付けます。

<details>
<summary>《詳しい手順》</summary>

スイッチの端子が曲がらないよう、真上からまっすぐに押し込みます。  
押し込む際に変な抵抗を感じたり、奥までスッと刺さらないときは、スイッチを一旦取り外し、端子が曲がっていないか確認してやり直します。

差し込み時に端子が曲がったスイッチ
差し込み時に端子が曲がったスイッチ

取り付けたら、スイッチがキープレートの枠にぴったりとはまっていることを確認します。  
スイッチがキープレートから浮いているような場合は、プレートを指で引っ張り、スイッチと密着させます。
</details>

スイッチをすべて取り付けた状態
スイッチを全て取り付けた状態  
（赤いペイントは、スイッチの足を切断したことがわかるようにつけた印で、特に意味はありません）

#### スイッチの動作確認

組み立て前におこなった[ソケット用パッドの確認](#ソケット用パッドの確認)と同様に、動作確認をおこないます。  
以前はピンセットでソケット用パッドをショートさせましたが、この手順ではスイッチを押して正しく反応することを確認します。

正常に入力できないスイッチがあった場合は、[参考：正常に入力できないスイッチの原因調査](#参考：正常に入力できないスイッチの原因調査)の手順に沿って調査します。

### ケースへの取り付け

#### （該当者のみ）Jones用ボトムプレートキットの取り付け

*Jones用ボトムプレートキットを使用しない場合、この手順は不要です。*

ボトムプレート裏面から、ネジ（M2 3mm）を使い、スペーサー（M2 3mm）をねじ止めします。  
以下の写真のように、8箇所をねじ止めします。  
右下は、キースイッチでネジ穴がふさがるため、WideレイアウトとNarrow, Normalレイアウトでねじ止め位置が異なります。

なお、GH60型, Poker型ケース取り付け用の、中央と中央右下のネジ穴はねじ止めしません。

スペーサー取り付け箇所
スペーサー取り付け箇所

基板を、ボトムプレートのスペーサーの位置にネジ穴の位置が合うように乗せます。  
基板裏側の部品やソケットが、スペーサーにぶつからないように気をつけてください。

基板おもて側から、ネジ（M2 3mm）を使ってねじ止めします。  
Narrowレイアウトの場合は、スイッチとの干渉を避けるため、右上のネジ穴にネジ（M2 3mm 低頭）を使用します。

低頭ネジの取り付け箇所
低頭ネジの取り付け箇所

基板とボトムプレートをねじ止めした状態
基板とボトムプレートをねじ止めした状態

取り外していたスイッチを取り付けます。

ボトムプレート底面に、次のように滑り止めのゴム足を貼り付けます。  

- キーボードに傾斜をつける場合
    奥の左・右の2箇所：ゴム足 大
    手前の左・中・右の3箇所：ゴム足 小

- キーボードをフラットにする場合
    手前と奥の左・中・右の6箇所：ゴム足 小

ボトムプレート取り付け完了
ボトムプレート取り付け完了

見た目を良くしたい場合は、キープレート, 基板, ボトムプレートの側面を、水性顔料インクのポスターカラーや油性マジックなどを使って塗ります。  
また、キープレートと基板の周りにマスキングテープなどを貼り付けて、見た目の印象を変えることもできます。

側面の加工例
側面の加工例（マスキングテープ貼り付けと黒色ペンでの塗り）

#### （該当者のみ）60% プラスチックケースの加工

*60% プラスチックケースを使用しない場合、この手順は不要です。*

60% プラスチックケースへ取り付ける際は、基板裏側の部品がケース内リブと干渉するため、干渉箇所を切り取る加工を行います。

切り取る箇所は以下の点線で囲んだ部分です。

リブ切り取り箇所
リブ切り取り箇所

写真で示した部分を、ニッパーやカッターなどを使って切り取ります。  
ニッパーで切り取る際は、1-2mmくらいずつ切り進んでください。  
それ以上の長さを一気に切断しようとすると、意図しないところが割れることがあります。

リブ切り取り前
リブ切り取り前

リブ切り取り後
リブ切り取り後

#### （該当者のみ）GH60型, Poker型ケースへの取り付け

*GH60型, Poker型ケースを使用しない場合は、この手順は不要です。*

打鍵感向上に興味のある方は、次の項目をお読みになると何かヒントがあるかもしれません。

- [参考：打鍵感向上：ケースへの基板取り付け方法](#参考：打鍵感向上：ケースへの基板取り付け方法)
- [参考：打鍵感向上：ケース内部の制振と静音化](参考：打鍵感向上：ケース内部の制振と静音化)

基板の奥側（USBコネクタ側）からケース内へ入れていきます。

基板の奥側を水平から30度くらいの角度でケースへ差し込むと、USBコネクタがケースの穴にスッとはまります。  
その状態で基板の手前側を静かに下ろして水平にすると、力をかけることなく、基板全体がストンとケースに入ります。  
力を入れてグリグリとこじったり、ググググッと押し込むようなことはせず、角度を合わせて差し込むだけです。

スペーサー取り付け箇所
30度で差し込む

ケースネジ穴と基板のネジ穴の位置を合わせ、ケースに付属しているネジで仮止めします。
ネジ穴とスイッチがかぶさる箇所は、キット付属の低頭ネジを使用します。  
低頭ネジは、ケースに付属しているネジの長さと同じか、より短いものを使用します。

ケースに対して上下左右の真ん中になるように、基板の位置を調整します。

ネジを締めて基板を固定します。

取り外していたスイッチを取り付けます。

ケース底面に、滑り止めのゴム足を貼り付けます。

### 仕上げ

キーキャップを取り付けます。

Remapで自分好みのキーマップに変更します。  
初期状態では、Wideレイアウトで英語配列のキーマップが設定され、6個のレイヤーを使用できます。  
レイヤー構成とLEDインジケータの色は次の通りです。

| No. | レイヤー名 | LEDインジケータ色<br>手前, 奥 |
| :-: | :-- | :-: |
| 0 | ベースレイヤー #1 | 白, 白 |
| 1 | ベースレイヤー #2 | 青, 青 |
| 2 | ベースレイヤー #3 | 黄, 黄 |
| 3 | Lower | －, 緑 |
| 4 | Raise | －, 水 |
| 5 | Adjust | －, 赤 |

完成です。

製作例
製作例

写真を撮影し、`#Jones_kbd` のタグをつけてツイートすると設計者が喜んだりします。  
[Twitter: #Jones_kbd](https://twitter.com/search?q=(%23jones_kbd)&src=typed_query&f=live

## 参考

打鍵感向上についてのDIY情報や、トラブル調査方法などの参考資料です。  
必要に応じてお読みください。

### 参考：1個のスピーカーで2音同時再生する

*元々は2個のスピーカーで2音同時再生する機能であり、1個のスピーカーでの再生は**実験的な機能**です。*
*ハードウェア的には1箇所ジャンパするだけで機能が有効になりますが、ファームウェアの書き換えが必要となるため、**それがどういうことか理解できる方のみ**おこなってください。*

QMKのAudio機能で[Music Mode](https://docs.qmk.fm/#/feature_audio?id=music-mode)を使用する際に、1つのスピーカーで2音同時再生させることができます。

Playing QMK's simultaneous tones with single speaker. (https://www.youtube.com/watch?v=ZqbNMjGJpUM)
YouTube：2音同時再生デモ動画

なお、2音同時再生されるのはMusic Modeで演奏する際の音だけで、キーボードの起動音やリセット音などの[Songs](https://docs.qmk.fm/#/feature_audio?id=songs)については、単音再生のままで変わりません。

キーボード裏側の`Simultaneous Audio`をジャンパします。

ジャンパ箇所
ジャンパ箇所

ファームウェアは、私のQMKフォークのブランチ [develop_jones:v04_1](https://github.com/jpskenn/qmk_firmware/tree/develop_Jones/keyboards/jones/v04_1)に、[via_duophone](https://github.com/jpskenn/qmk_firmware/tree/develop_Jones/keyboards/jones/v04_1/keymaps/via_duophone)の名前で用意しています。

初期状態で書き込んであるVIA対応ファームウェアと同等ですが、キーマップの`via_duophone/config.h`で2音同時再生の設定に上書きしている点が異なります。  
また、ファームウェアサイズの制限により、`ベースレイヤー #3`を削除して、使用できるレイヤー数を6から5に減らしています。

``` c
#ifdef AUDIO_ENABLE
  #undef AUDIO_PIN
  #define AUDIO_PIN C6
  #define AUDIO_PIN_ALT B6
#endif
```

ファームウェアを次のように作成し、任意の方法で書き込みます。

``` shell
make jones/v04_1:via_duophone
```

### 参考：打鍵感向上：ケースへの基板取り付け方法

GH60型, Poker型ケースへの基板取り付け方法を変更し、打鍵感の向上を目指すための資料です。  

通常であれば、左2, 右2, 中央1, 中央下1の合計6本のネジで基板をケースに固定しますが、基板を改造して固定方法を変えることで、打鍵感の向上を狙います。

なお、通常の手順で組み立てた後でも、これらの改造をおこなうことができます。

``` aside
60%プラケースは、ケース内のリブがネジ穴と同じ高さに成形されているため、そのままでは打鍵感は向上しません。
ケース内のリブをネジ穴よりも低い高さに切り取る加工を行えば、効果が期待できます。
```

**この加工による基板の破損や、ケースへの取り付け不良などの不具合が発生することが考えられるため、加工者の責任でお楽しみください。**  
**また、改造を行なった基板は元には戻せませんので、それを理解した上でおこなってください。**

``` aside
今のところ、これらの改造をおこなって不具合が発生したことはありません。
```

#### 方法1：基板中央のフレックス加工

基板の中央付近のネジ穴を切り取り、左右のネジだけでケースに固定することで、基板を適度にしならせて打鍵感を柔らかくする改造です。  

組み立て済みの場合は、切り取り箇所付近のスイッチを取り外します。

基板裏側、中央と中央下のネジ穴
基板裏側、中央と中央下のネジ穴

中央と中央下のネジ穴を、基板裏側に白い点線で描かれた切断ガイドに沿ってニッパーなどを使って切り離します。  
まわりの部品を傷つけないように注意しながら、一度にカットしようとせず、基板の裏側とおもて側から少しずつ切り進めていきます。  
ケースねじ穴に当たらないよう、切り取った箇所のバリをやすりやカッターなどを使ってきれいにします。

切り離した状態
切り離した状態

ケースに基板を入れ、左右のネジだけでケースに固定します。

TOFUケースに入れた状態（中央ねじ穴）
TOFUケースに入れた状態（中央ねじ穴）

#### 方法2：ネジを使わずにケースへ固定

基板からすべてのネジ穴を切り取り、制振スポンジによってケース内側側面に固定することで、打鍵時の衝撃がケースのネジ穴へ直接伝わるのを抑える改造です。  
制振スポンジは、PORON（衝撃吸収の良いマイクロセルウレタンフォーム）などを使用します。

基板を支えるため、ケース内側に制振スポンジを敷き詰めます。  
ケースネジ穴と同じくらいの高さになるようにします。

すべてのネジ穴を、基板裏側に白い点線で描かれた切断ガイドに沿ってニッパーなどを使って切り離します。  
まわりの部品を傷つけないように注意しながら、一度にカットしようとせず、基板の裏側とおもて側から少しずつ切り進めていきます。

基板4辺の側面に、両面テープなどを使い、1.5mm厚の制振スポンジを貼り付けます。  
基板外形には0.5mmの凹みがついている箇所があるので、その部分へ貼り付けます。  
基板とケース内側との隙間が広い場合は、現物合わせで、凹みのない部分へ貼り付けます。

基板をケースへ入れます。

### 参考：打鍵感向上：ケース内部の制振と静音化

ケース内部底面におもり（10円玉, 真鍮板, 自動車のホイールバランスウェイト, 鉛シート, etc.）を入れておくと、ケースの共振が抑えられ、打鍵感の向上や、打鍵音の変化が期待できます。

ウレタンスポンジやシリコンシートなどで基板とケース間の空間を埋めてケース内部の残響音を減らしたり、基板の振動を抑制して振動音の発生を抑えて静音化するのも効果的です。



### 参考：打鍵感向上：キープレートと基板間のパテ埋め

キープレートと基板の間をパテ埋めすることで、打鍵感の向上を目指すための資料です。  
パテはエアコン配管用パテを使用します。



パテ埋めすることで、次のような効果が期待できます。

- 剛性の大幅な向上
- 振動を大幅に低減
- キープレートと基板の間の空間で発生する音を除去
- キースイッチの安定性の向上

これらの効果により、ブレの少ないかっちりとした打鍵感と、密度が高く、明瞭で少しピッチが高い打鍵音を得ることができます。
<!-- 〓打鍵音比較を見せたいが、使用前がないかも -->

<details>
<summary>《詳しい手順》</summary>
組み立て済みの場合は、ケースから基板を取り外し、キープレートと基板を分離します。

キープレートにスイッチを取り付けた状態にして、裏側（スイッチの端子が見える側）を上にして置きます。

スイッチとスイッチの間、キープレートの枠の部分にパテを乗せます。  
基板と組み合わせた時に、スイッチと基板の間にはみ出さない程度の量にします。  
スタビライザーを取り付けているスイッチ付近は、スタビライザーの動作を妨げることがあるので、この段階ではパテを乗せずにおきます。



キープレートと基板を合わせ、スイッチをソケットにはめ込みます。

スタビライザー付近や、キープレートの枠がないスイッチの周り、基板外周部にパテを追加します。  



打鍵してみて、振動を感じたり、他と比べて音が異なる箇所があれば、スイッチを取り外してパテを押し込みます。



</details>

### 参考：USBコネクタ接続図

USBコネクタの配線は次の通りです。


USBコネクタ接続図

### 参考：スピーカーの2音同時再生

基板裏側のジャンパ`simultaneous audio`をジャンパすると、2音同時再生できるようになります。  
ジャンパしない場合は単音で再生されます。

ジャンパ箇所
ジャンパ箇所

### 参考：正常に入力できないスイッチの原因調査

もっとも多い原因は、スイッチの取り付け不良です。  
スイッチを取り外し、端子が曲がったり折れたりしていないか確認します。  
端子の曲がりを修復するか、新しいスイッチに交換して、もう一度キー入力を確認します。

次いで多いのが、ソケットのはんだ不良です。  
ソケットのはんだ忘れや、はんだが適切に行われていないことが原因のため、ソケットのはんだ状態を確認します。  
必要であれば再度はんだ付けし直して、もう一度キー入力を確認します。

上記で解決できなかった場合は、基板のソケット用パッドをピンセットなどを使ってショートさせ、もう一度キー入力を確認します。  
キー入力が確認できた場合は、パッド自体は正常ですので、スイッチとソケットを再度調査します。

ソケット用パッドをショートしてもキー入力が確認できない場合は、組み立て途中に基板の配線や部品がダメージを受けたことが原因と考えられ、これ以降の調査と修復の難易度は、かなり高くなります。

電子工作に詳しい方であれば、[JonesのKiCadプロジェクト](https://github.com/jpskenn/Jones/tree/master/PCB)を参考にテスター等を用いて調査を進められると思います。

自分ではどうにもできない方は、キット同梱のリーフレットに記載された連絡先へ問い合わせてください。  
状況に応じて、できる限りのサポートをいたします。  

### 参考：LEDの取り付け不良調査

#### ジャンパの確認

LEDの組み合わせに応じて、基板裏側のジャンパが正しく行われていることを確認します。

| 組み合わせ | 左側<br>LED1, 2 | 右側<br>LED3, 4 | ジャンパ<br>Left LEDs | ジャンパ<br>Right LEDs |
| :--: | :--: | :--: | :--: | :--: |
| LED未使用 | なし | なし | 不要 または Off | 不要 または Off |
| 左側のみ | あり | なし | On | 不要 または Off |
| 右側のみ | なし | あり | Off | On |
| 左右両方 | あり | あり | On | On |

#### LEDの確認

ジャンパが正しく行われても点灯しない場合は、LEDに原因があると考えられますので、以下の順に対処します。  

``` aside
なお、基板の配線へのダメージなど、他の要因も考えられますが、確率はかなり低いです。  
「組み立て中に工具で基板をガリっとやってしまった…」などの心当たりがあれば、また別ですが…
```

1. 光らないLEDのはんだ不良を修復する
    光らないLEDが正しくはんだ付けされていない、と仮定した対処です。
    光らないLEDの側面の端子部分にフラックスを塗り、こて先につけたはんだを押しあてて、はんだ付けをやり直します。

1. 光らないLEDの*ひとつ前*のLEDのはんだ不良を修復する
    光らないLEDのはんだは正常だが、ひとつ前のLEDのはんだ不良が原因で配線がつながっていない、と仮定した対処です。
    LEDは組み合わせによって、以下に示す順番で並んでいます。
    ひとつ前のLEDのはんだ付けをやり直します。
    | 組み合わせ | LEDの並び |
    | :--: | :-- |
    | 左側のみ | 左上（LED1） → 左下（LED2） |
    | 右側のみ | 右上（LED3） → 右下（LED4） |
    | 左右両方 | 左上（LED1） → 左下（LED2） → 右上（LED3） → 右下（LED4） |

1. 光らないLEDを新しいものに交換する
    220-270℃で1、2と数える程の加熱ではそう簡単にはLEDは壊れないと考えますが、何度かはんだをやり直しても点灯しない場合は、LEDが壊れていると判断して新しいものに交換します。

### 参考：ファームウェアの書き込み方法（QMK Toolboxで書き込む）

QMK Toolboxを使ったファームウェアの書き込み方法について説明します。

<details>
<summary>《詳しい説明》</summary>

#### ビルド済みファームウェアのダウンロード

[Firmware for Jones v.0.4.1](https://gist.github.com/jpskenn/d945e87789f29a62901298beea667db1)のページで`Download ZIP`をクリックしてZIPファイルをダウンロードします。

ZIPファイルを解凍／展開し、ビルド済みファームウェア`jones_v04_1_via.hex`を取り出します。

#### QMK Toolboxの使用

ビルド済み（≒作成済み）のキーボード用ファームウェアを書き込むには、[QMK Toolbox](https://github.com/qmk/qmk_toolbox/releases)を使用します。

QMKファームウェアに関するドキュメントの、[ファームウェアを書き込む](https://docs.qmk.fm/#/ja/newbs_flashing?id=ファームウェアを書き込む)を参考に、QMK Toolboxを使ってキーボードに書き込みます。

#### キーボードを DFU (Bootloader) モードにする方法

JonesキーボードでDFU (Bootloader)モードにするには、次のように操作します。

1. USBケーブルを抜く

1. キーボードの左上のキーを押したまま、USBケーブルを差し込む

この操作によってEEPROMも消去されるので、古いデータが残って動作がおかしくなるのを防止できます。  
ファームウェアの書き込みが終わった後に外部EEPROMの消去がおこなわれるため、**キーボードの起動まで5〜10秒ほどかかります**。（書き込み直後の初回起動のみ）

</details>

### 参考：ファームウェアの書き込み方法（コマンドを使って書き込む）

Jones v.0.4.1のファームウェアは、私のQMKフォークのブランチ[develop_jones:v04_1](https://github.com/jpskenn/qmk_firmware/tree/develop_Jones/keyboards/jones/v04_1)に用意しています。  
必要に応じてキーマップや機能の設定を変更し、ファームウェアを構築して書き込んでください。

ファームウェアの書き込みが終わった後、外部EEPROMの消去に5~10秒ほどかかる場合があります。（書き込み直後の1回のみ）

<details>
<summary>《詳しい手順》</summary>

[QMK環境の構築](https://docs.qmk.fm/#/ja/newbs_getting_started)を参考にビルド環境を構築します。

必要に応じてキーマップや機能の設定を変更します。

次のようにファームウェアを構築します。  
`via`キーマップでファームウェアを構築する例

``` shell
qmk compile  -kb jones/v04_1 -km via
```

[ファームウェアを書き込む](https://docs.qmk.fm/#/ja/newbs_flashing)を参考に、構築したファームウェアを書き込みます。

</details>

### 参考：EEPROMを消去し、初期状態に戻す方法

RemapやVIAなどのキーマップ書き換えツールで設定した内容など、EEPROMに記録されているデータを消去し、ファームウェアの初期状態に戻すことができます。  
EEPROMに記録されている全てのデータが消去されるので、キーボードの動作がおかしい場合の最終手段としておこなってください。

なお、キーマップだけを初期状態に戻すのは、Remapでも可能です。

<details>
<summary>《詳しい手順》</summary>

USBケーブルを抜きます。

キーボードの左上のキーを押したまま、USBケーブルを差し込みます。

差し込んで1,2と数えてから、USBケーブルを抜きます。

USBケーブルを差し込みます。

5秒ほどで外部EEPROMが消去され、キーボードが動作するようになります。  

これで設定が初期状態に戻ります。
</details>

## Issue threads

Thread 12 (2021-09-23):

TRRSでI2Cを外へ出す

jpskenn, 2021-09-23:
## 機能

I2Cで拡張する可能性

- OLEDディスプレイ付きTRRSケーブル
  [A TRRS Cable w/ A OLED Display](https://edoball.hatenablog.com/entry/2021/09/20/132818)

- テンキーパッド（自前で作る？）

## 実装

どこか1キーをつぶして、VerticalなTRRSコネクタをつける？

jpskenn, 2021-09-23:
TRRSで良いパーツが見つかっていない

jpskenn, 2021-10-03:
Verticalなものは、プラグ差し込み時に飛び出しすぎる。
Horizontalなもの、ErgoDashとかでも使ってるタイプは、高さ5mmでキープレートに干渉。

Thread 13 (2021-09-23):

クリスタル→セラロック

jpskenn, 2021-09-23:

jpskenn, 2021-09-23:
使用パーツ
Murata CSTNE16M0VH3L000R0 (16MHz)

http://applause.elfmimi.jp/ShiroMicro-BOM.pdf
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

jpskenn, 2021-10-02:
使用するセラロックが高精度なCSTNE16M0VH3L000R0のため、パーツ入手性に難がある。

- JLCPBCのSMTAに在庫なし
- Digikey在庫なし
- 秋月在庫なし

世界状況的に、すぐの回復が見込めないため、
よって、v.1.1には含めない

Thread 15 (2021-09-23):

アンダーグローを、LEDテープとLED取り付けの排他使用

jpskenn, 2021-09-23:
v.1.0ではLEDテープに対応した。

LEDテープの

- 入手性がイマイチ（舎に15個とかのやつがない）
- MXソケットと重なって厚みが出るため、ボトムプレートに非対応
- 60％プラケースとかでは、ケース内のリブに当たる（回避可能）

という欠点に対応するため、テープのかわりにLEDをそのまま実装できるようにしたい。

WS2812またはSK6812MINIとする。
タブ付きのYS-SK6812MINI-Eは、基板の穴で光の周りがわるい（Unisonでは四角い枠がついた）のと、配線がつらくなりそうなので使わない。

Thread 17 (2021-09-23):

SemiErgo風の親指

jpskenn, 2021-09-23:
[SemiErgo](https://github.com/mtei/SemiErgo_Layout)

現在：100-150-200　または　125-125-200
SemiErgo：100-125-100-125 または 100-125-125-100

jpskenn, 2021-09-23:
SemiErgoでは、スペースキーがFにかからずGの直下から始まっている。
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
60%キーボードは2u-wideにしたとしても幅が狭いため、手（腕）はハの字となる。
（スプリットキーボードやKinesis Advantageのサイズなら、前にまっすぐ平行になる）
そのため、Gの直下に親指を置くには親指を広げる必要があり、これは手（指）を自然にした状態から親指を緊張させるような気がする。
というわけで、GとFにかかるように1.25uを配置することとする。

都合のいいことに（？）、Jones配列でR2-R3にズレがないので、GとFにかかる1.25uにしても、左右の端に3uのvendor specific areaが残ることになる。

jpskenn, 2021-09-23:
基板のフットプリント、左側は100（既存）-125-100-125が配置できる。
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

jpskenn, 2021-09-23:
右手側に、125-100-125-100（既存）を配置するのは、なかなか厳しい。
150,125,125,100の4個の重ね方を調整すればスイッチのフットプリントはOKだが、ボトム用ネジ穴にかぶる。
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

jpskenn, 2021-09-23:
右手側の125（既存）-100-125-100（既存）は、これでネジ穴も回避できる。
1.5uのパッドがそこそこ削られるので強度が心配だが、SW_'2もこれくらいなので、なんとか…
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

jpskenn, 2021-09-24:
SemiErgoに対応するキーキャップセットは？

jpskenn, 2021-09-24:
US104はOK。
JP108（Filcoのタイプ）は1.25uがUSより少ないので、非対応。

jpskenn, 2021-09-29:
http://www.keyboard-layout-editor.com/#/gists/ddfb2fe4c752bd98f6f64e0d973b00ad
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

jpskenn, 2021-09-30:
> 基板のフットプリント、左側は100（既存）-125-100-125が配置できる。
> 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

1uがMXソケットだと、隣の2uのソケットのパッドと干渉するので、非ソケットにする。

jpskenn, 2021-09-30:
> 右手側の125（既存）-100-125-100（既存）は、これでネジ穴も回避できる。
> 1.5uのパッドがそこそこ削られるので強度が心配だが、SW_'2もこれくらいなので、なんとか…
> 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

右手側、Narrowは元々スイッチの本体がネジ穴にかぶるので、別のねじ穴でボトムに止めるようにしてあるので、かぶってOK。
SemiErgoも別のネジ穴でとめればよいから、かぶってOKだよ。

jpskenn, 2021-09-30:
とは言うものの、1.5uを縦にするしか、入らなかった。

jpskenn, 2021-09-30:
SemiErgo対応で、キーマトリクスに1キー増えている。
SemiErgo対応のQMKファームウェアを作成すると、v.1(042)とRemap／VIA的に整合性がなくなってしまう。
※RemapはProductNameでv.1を生かしつつ、別のものとしてv.1.1を使えるがVIAはだめ。

SemiErgoはソケットにも対応しないし、非公開の機能とする。
ビルドガイドの`参考`には書くけど、手厚いサポートは無し。

Closed 2021-10-01.

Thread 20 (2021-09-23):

最下段、センター2u／1u+1uで、2uのフットプリントを180度回転

jpskenn, 2021-09-23:
2uのフットプリントを反転して、どっちのソケットをつけてても干渉しないようにする。
気分で2uと1+1を変えたいときに、ソケットを取り外すために、はんだ準備するのが面倒なのを改善。

jpskenn, 2021-09-23:
#21のコメントで、元々はNorth Facingを避ける意味合いで同じ方向に並べたもの。

North Facingを避けたいというルールは残っているので、**現状の正方向2uはそのまま残して、逆方向の2uを追加する。**
2uのフットプリントを追加するとスタビ穴を二回あけられてガバガバになることが懸念されるため、1uのフットプリントを追加する。

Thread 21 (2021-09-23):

最下段、センターからすぐ右のNarrow1.25uを180度回転

jpskenn, 2021-09-23:
#20 と同様

jpskenn, 2021-09-23:
センターの2u／1u+1uは、同一レイアウト内でのマイナーチェンジみたいな感じだから、まだ、やる意味がある。
NarrowとWideのレイアウト変更は、どうせ他のかぶってるところもやらないとダメ。

元々はなるべくNorth Facingを避けるために正方向にしていたのだから、これをやると元のルールが崩れるのでボツ。

Closed 2021-09-23.

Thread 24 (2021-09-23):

ケース：スポンジマウント

jpskenn, 2021-09-23:
ケースへの基板マウント方法についてのアイデア

60%ケースのねじ穴のまわりに、ネジ穴より少し頭がでるくらいのポロンスポンジとかを置いて（ドーナツみたいな穴を開けたやつ）、基板を下から支える感じ。

左右の端はドーナツにできないので、左右ネジ穴より少し内側に基板表側からネジ通して（裏側はナット留めか、スペーサー）、ポロンスポンジに刺さる（ドーナツの穴に入る）棒を出しておく。

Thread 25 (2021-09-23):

PI PICO用のピン

jpskenn, 2021-09-23:
基板うら側からPICOを挿せるようにする。
テストピン、予備ピンとして用意しているものをPICOピンにもってくる。

PICOサイズの切り欠きをつけたボトムプレートと合わせて、なんとかしたい。

jpskenn, 2021-09-24:
PICOの動作テストがやりたいだけ。

jpskenn, 2021-09-24:
#18 と合わせて、PICOを配置できるところを探る。
右か左の端？

jpskenn, 2021-10-01:
スイッチ3個分くらいの設置スペース
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

jpskenn, 2021-10-01:
ソケットが縦になっているときびしい。
無理ではなさそう
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

jpskenn, 2021-10-01:
- 0-4, 5-9のピンをまとて並べつつ、配線しやすいところのPICOピンを使う。
- 他の穴とどうしてもかぶる場合は、ピンヘッダを一部カットするとかもアリ

jpskenn, 2021-10-02:
総当たりマトリクスで動くかわからんよ

jpskenn, 2021-10-03:
KMKで、ROWとCOLにピンを重複して定義できなかったので、一旦中止。

jpskenn, 2021-10-03:
v.0.4.1とv.1(042)で、普通のGPIOピンと、GPIOピンがダイオードを通った後の配線をテストピンとして良いしている。
普通のGPIOピンをROW、ダイオード通った後のをCOLとしてPICOに接続すればOKでは？

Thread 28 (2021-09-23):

右上にロータリーエンコーダを配置

jpskenn, 2021-09-23:
現状の最下行では、背の高いノブだとつらい。
右上なら、まぁ、なんでもつけられる。

ピンは余ってるのを使ってRE3とするか、右下と排他にするか？
要検討。

スタビ穴とかぶるので、横向き？
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

jpskenn, 2021-09-24:
参考
https://discord.com/channels/376937950409392130/698226997876359209/890967052708364318
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

jpskenn, 2021-09-26:
これはダメだったみたい
https://discord.com/channels/376937950409392130/418326189644709889/891597840147697714

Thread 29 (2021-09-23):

レイアウト：40sキット対応

jpskenn, 2021-09-23:
アルファと40sキット、もしくはDSSとかでよくある40sセットだけを使って組めるレイアウトを追加する。

- R2の1.5uタブない
  - 1u TABに対応？
  左に0.5uの隙間あくのと、スイッチは片足をカットでなんとかなる
  1uで0.5uの隙間はダサいけど、R3の1.25u TABがよく入っているが、KATとかのプロファイルによってはR3の1.25がR2のプロファイルと違いすぎて合わないものがあるので1uも入れる

  - 1.25u TAB

  プロファイルによっては、R3（CTRL行）用の1.25u tabをR2で使ってもOKぽいので、1.25uにも対応

## 実装
1uと1.25uを横向きで並べる。

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

jpskenn, 2021-09-23:
TAB以外にも対応が必要なキーは？
DSSの40sセットを、もう少し調査する必要あり。

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

jpskenn, 2021-09-23:
参考 DSS After School
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

jpskenn, 2021-09-23:
TABの1u、1.25uの追加だけでOKぽい

http://www.keyboard-layout-editor.com/#/gists/d6d76405757dc91c19fa5c8c125fb77c
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

jpskenn, 2021-09-23:
参考
KAT Alpha
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

jpskenn, 2021-09-24:
1uのTABを使うと、左に0.5uの隙間ができるので、基板にロゴとか書いておきたい

jpskenn, 2021-09-27:
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

横向きで入れている1uの固定用ピン穴が、元々の60%Tab 1.5uのパッドを半分削ってしまうのは、ちょっとやりすぎなので、別の実装方法を考える。

jpskenn, 2021-09-27:
参考　DSS Lightcycle
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

jpskenn, 2021-09-27:
1uのHotswapはどうにも入れにくい。
1uのソケットじゃないやつを上向きなら、ギリな感じ。

**1u入れるかどうかを決める。**

jpskenn, 2021-09-27:
ソケットなしを下向き（逆向き）に入れる。
2番ピンの中に他の穴が入ってくるので、入ってくる穴のスイッチのフットプリントで、穴を消す。

jpskenn, 2021-09-28:
1.25u、1uともに、縦にして入れる。
1uの固定ピンが1.5uのパッドを半分削ってしまうのを避けるため、片方の固定ピンを取り除いたフットプリントを作成して対応。
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

Closed 2021-09-29.

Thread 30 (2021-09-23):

左上、右上のネジ穴を少しだけ大きく

jpskenn, 2021-09-23:
ケースの誤差を吸収するため、基板上の左上と右上のネジ穴サイズを、**ほんの少し**拡大する。

現在M2。
M2.4くらいでもいいが、大きすぎて低頭ネジの頭が基盤にかからなくならない程度に。
ほんの少しの拡大でよい。

関連
https://twitter.com/yohewi/status/1441039060580003850

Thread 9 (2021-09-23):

AUDIO

jpskenn, 2021-09-23:

jpskenn, 2021-09-23:
デメリット
- RemapのJSON作り直し
- 旧ver.使用者がRemap開くとちょっと…（Remap側でProduct Name見てくれてるからセーフだけどVIAはだめ）

jpskenn, 2021-09-24:
ロータリーエンコーダのVIA書き換えの仮想キーを含めて74キーが必要なので、
総当たりマトリクスは10ピンで作成。（v.0.4.1からこれ）
このとき、VIAで4レイヤーが使えるが、どうせ外部EEPROMをつけたので、マトリクスを変更するメリットが見えてこない。

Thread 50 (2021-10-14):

バックライト対応レイアウト

jpskenn, 2021-10-14:
バックライトに対応するため、ほぼ固定のレイアウトに変更する。

## 概要
- US104キーキャップですべて埋められるレイアウト。
  すべてソケット対応。
- カスタムキーキャップで、完全なレイアウト（1.5u Enterなど）または柔軟なレイアウト（40sキット）を構成可能。
  US104のソケットとLEDの配置を優先するため、スルーホールの可能性あり。
- レイアウトのバリエーション削減
  LEDの配置を優先
- JP108廃止
- Narrow廃止
- キーキャップ以外のLED設置場所
  - 基板おもて側：レイヤーインジケータ（v.1と同じ位置，4個）
  - 基板うら側：アンダーグロー。手前8？、奥8？

## ソフトウェア的なこと
QMKのRGB Matrixを使用

jpskenn, 2021-10-14:
http://www.keyboard-layout-editor.com/#/gists/50c520a81398491816d06e839fa04f78
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

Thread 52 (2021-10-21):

Question about the extra diodes on each pin as a column

myst729, 2021-10-21:
This is not an issue. It's a technical problem that I don't figure out. Excuse me.

I know diodes could fix the ghosting problem in an ortho matrix. But I couldn't get the idea why every "column pin" has an extra diode. What's the purpose and how do they work?

myst729, 2021-11-08:
Tested. The extra diodes are still mandatory for Li-Po powered 32u4+bluetooth. The current is very low, so the diode's actual Vf is much lower that its maximum value. Two diodes couldn't provide enough Vf in total. Four diodes do.

myst729, 2021-11-26:
I finally step back to duplex layout for several reasons. 😃

1. Comparing to standard ortho matrix, duplex significantly reduces the amount of GPIOs. In practice, half col pins, which is a big improvement.
2. Although the amount of GPIOs in a round-robin layout can be even less, the PCB routing complexity increases a lot. To achieve a fairly reasonable complexity (also for future maintainability), Round-robin does not have obvious advantages in regards of GPIOs.
3. Duplex doesn't need to calculate Vf, easier to alter materials.

Nevertheless, this repo is still a great inspiration for me.

jpskenn, 2021-11-26:
Thanks to report your status👍

PCB routing complexity is ... Yes, I'm struggled with that😅
So, I chose duplex for my  next project [Nora](https://github.com/jpskenn/Nora).

myst729, 2021-11-26:
Running QMK on RP2040? Interesting.

jpskenn, 2021-11-26:
No, No, No.

QMK runs on ATmega32u4.
Some other "X"MK runs on PICO😝

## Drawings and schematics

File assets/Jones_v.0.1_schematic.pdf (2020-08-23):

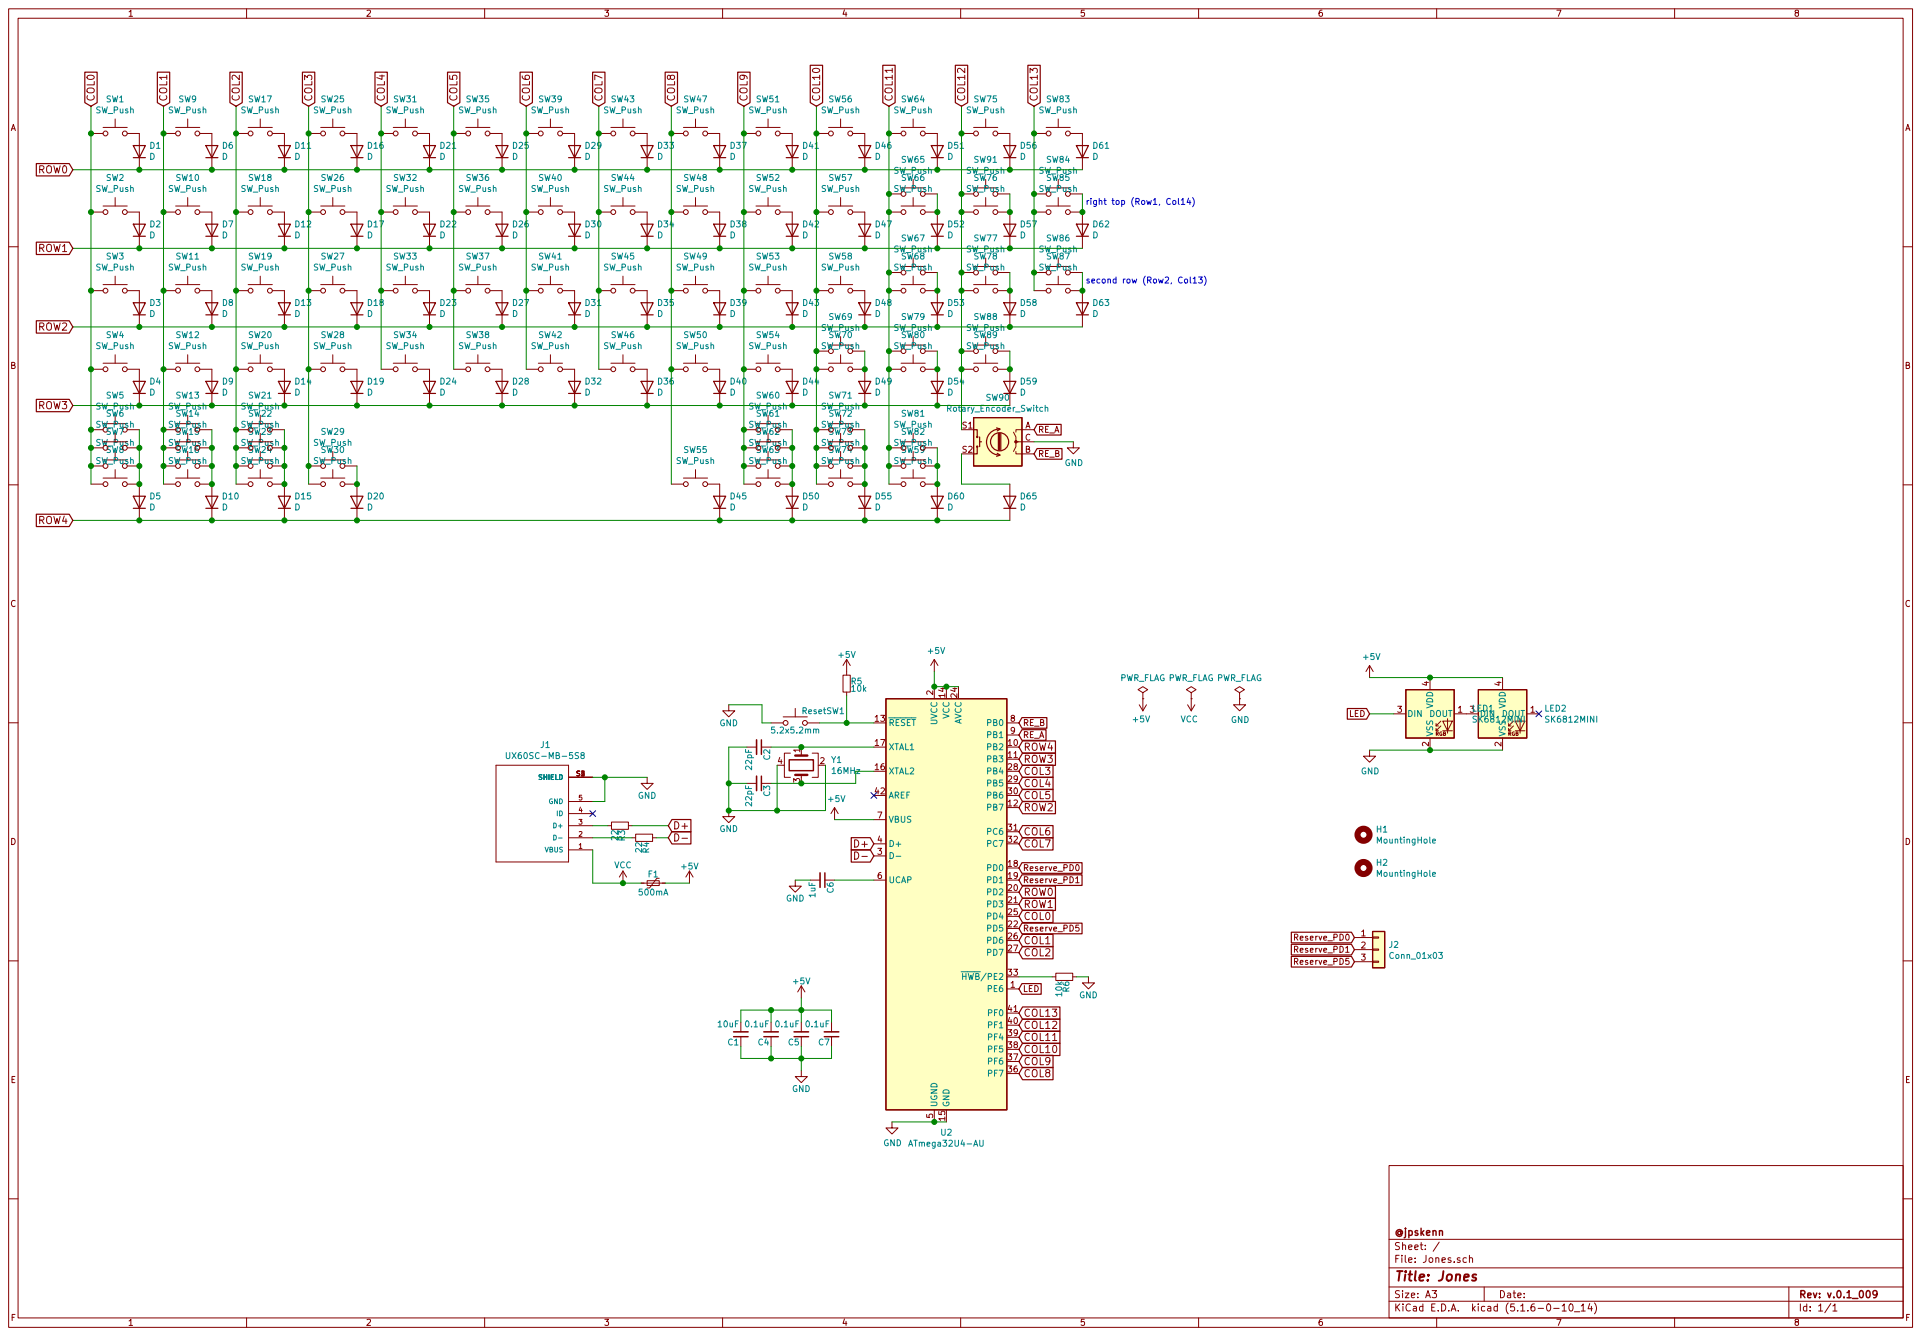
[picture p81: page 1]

2 PD2 20 PD3 21 PD5 22 AVCC 24 PD4 25 PD6 26 PD7 27 PB4 28 PB5 29 D- 3 PB6 30 PC6 31 PC7 32 HWB/PE2 33 PF7 36 PF6 37 PF5 38 PF4 39 D+ 4 PF1 40 PF0 41 AREF 42 UGND

File: Jones.sch Sheet: / @jpskenn

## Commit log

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2020-07-11 New キープレート関連初期コミット
    [keyplate_SplitSpace_Merged.dxf, keyplate_SplitSpace_Merged_for_切断堂.dxf]
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2020-08-23 Update v.0.1のビルドガイドを追加。
    [keyplate_SplitSpace_Merged_14x14.dxf]
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2020-08-23 Fix ビルドガイドのリンク修正
2020-08-23 Fix タイポ修正。
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2020-08-23 Fix 文章の表現変更。
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2020-08-23 Fix 不要箇所削除。
2020-08-23 Fix タイポ
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2020-08-24 New ローカルのキープレート関連を新規追加。
    [ai03_plate_generator.dxf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]
2020-08-24 New PCB v.0.1
    [Jones-2018-12-25-18-22-20.sch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]
2020-08-24 New PCB v.0.2
    [Jones-2018-12-25-18-22-20.sch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]
2020-08-24 New PCB v.0.3
    [Jones-2018-12-25-18-22-20.sch, Jones.kicad_pcb, Jones.sch]
2020-08-24 New PCB_Blocker
    [Jones-2018-12-25-18-22-20.sch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]
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2020-10-17 New v.0.3.1系KiCadプロジェクトの初期コミット。
    [Jones-2018-12-25-18-22-20.sch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]
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2020-10-17 New PCBをバージョン管理しつつ作っていく最初のコミット
    [Jones-2018-12-25-18-22-20.sch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]
2020-10-17 New 過去の作成分を全て登録
    [Jones-2018-12-25-18-22-20.sch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]
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2020-11-01 Update LED抵抗値の計算を追加
    [RR-Matrix.xlsx]
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2020-11-22 New Voyager60の基板データを初期状態としてコピー
    [Jones-2018-12-25-18-22-20.sch, Jones.kicad_pcb, Jones.sch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]
2020-11-22 Update 001
    [Jones.kicad_pcb]
2020-11-22 Update 002
    [Jones.kicad_pcb, Jones.sch]
2020-11-22 Update 003 Y軸ミラーが気に入らない
    [Jones.kicad_pcb, Jones.sch]
2020-11-22 Update 004
    [Jones.kicad_pcb, Jones.sch]
2020-11-22 Update 005
    [Jones.kicad_pcb, Jones.sch]
2020-11-22 Update 006
    [Jones.kicad_pcb]
2020-11-22 Update 007
    [Jones.kicad_pcb]
2020-11-22 008 初回発注
    [Jones-B_Cu.gbl, Jones-B_Fab.gbr, Jones-B_Mask.gbs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]
2020-11-22 Update 基板チェックFailedを修正
    [Jones-B_Cu.gbl, Jones-B_Fab.gbr, Jones-B_Mask.gbs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]
2020-11-22 Update 000
    [Jones-B_Cu.gbl, Jones-B_Fab.gbr, Jones-B_Mask.gbs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]
2020-11-22 Update 003
    [Jones.kicad_pcb, Jones.sch]
2020-11-22 Update 006 w/o Blocker
    [Jones-B_Cu.gbl, Jones-B_Fab.gbr, Jones-B_Mask.gbs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]
2020-11-22 Update 下調べ
    [Jones-B_Cu.gbl, Jones-B_Fab.gbr, Jones-B_Mask.gbs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]
2020-11-22 Update USB Type-C
    [Jones.kicad_pcb, Jones.sch]
2020-11-22 Update RR-Matrix
    [Jones.kicad_pcb, Jones.sch]
2020-11-22 Update 2U-Wideを廃止し、Narrowのみとする。
    [Jones.kicad_pcb, Jones.sch]
2020-11-22 Update 配線引き直し
    [Jones.kicad_pcb, Jones.sch]
2020-11-22 Update 基盤外形のネジ穴サイズを縮小
    [Jones.kicad_pcb, Jones.sch]
2020-11-22 Update 部品、表と裏を移動。
    [Jones.kicad_pcb, Jones.sch]
2020-11-22 Update 位置調整
    [Jones-B_Cu.gbl, Jones-B_Fab.gbr, Jones-B_Mask.gbs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]
2020-11-22 Update initial
    [Jones-B_Cu.gbl, Jones-B_Fab.gbr, Jones-B_Mask.gbs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]
2020-11-22 Update USBコネクタはんだ付け時に配線を擦らないよう、配線を裏面へ移動。
    [Jones.kicad_pcb]
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2020-11-23 Update USBコネクタ裏のGNDベタが途切れるため、v.0.3.1に近い配線に変更。 24c09707c8a92fe4cf8691956c160a484a01a86f
    [Jones.kicad_pcb]
2020-11-23 Update ネジ穴を介して2箇所のソケットのパッドが導通してしまうため、基板外形のフットプリントから裏面のマスクを無くした。
    [Jones.kicad_pcb]
2020-11-23 Update ビルド時に方向を間違いやすいため、左側LEDの設置方向を右側LEDと同じ方向に合わせた。LEDシルク位置調整。
    [Jones.kicad_pcb]
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2020-11-28 Update TOFUケースの製品名をアルミケースであることがわかるように修正。
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2020-11-29 Update Twitterハッシュタグの表記間違いを修正
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2021-01-06 Update: 右上ネジ穴とスイッチソケットのパッドが導通しないよう、基板外形のネジ穴を変更。
    [Jones.kicad_pcb]
2021-01-06 Update: 部品実装後にシルクが見えなくなる箇所を位置調整。
    [Jones.kicad_pcb]
2021-01-06 Update: バージョン表記を更新
    [Jones.kicad_pcb]
2021-01-06 Update: 回路図のOLEDがレスキューされた
    [Jones.sch]
2021-01-06 New: キープレートの強度アップのため、外部拡張、OLED配置用の切り欠きをオプションとした。
    [keyplate-B_Cu.gbl, keyplate-B_Mask.gbs, keyplate-B_Paste.gbp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]
2021-01-07 Update: 未配線箇所を配線し、全ての配線完了。
    [Jones.kicad_pcb]
2021-01-10 Update, Order: ガーバー生成、SMT関連ファイル準備。発注。
    [Jones-B_Cu.gbr, Jones-B_Fab.gbr, Jones-B_Mask.gbr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]
2021-01-10 Update: 必要性がないため、外部拡張、I2C、OLED関連の回路を削除。
    [Jones.sch]
2021-01-10 Update: 配線削除。部品再配置。
    [Jones.kicad_pcb]
2021-01-11 Update: 配線途中
    [Jones.kicad_pcb]
2021-01-11 Update: 配線途中。もう少しだが、マトリクスを見直した方が配線がすっきりしそう。
    [Jones.kicad_pcb, Jones.sch]
2021-01-11 Update: 総当たりマトリクスの使用ピン数を11から10に変更し、マトリクスないのスイッチの接続を変更。
    [Jones.sch]
2021-01-13 Update: PCB,回路図 ひとまず配線完了
    [Jones.kicad_pcb, Jones.sch]
2021-01-14 Update: 総当たりマトリクスについてのメモを追加
    [雑多メモ.xlsx]
2021-01-15 Update: PCB,回路図 配線完了
    [Jones.kicad_pcb, Jones.sch]
2021-01-16 Update: ダイオードのソケットへのかぶさり回避。配線、シルク調整完了。
    [Jones.kicad_pcb, Jones.sch]
2021-01-16 Update: PCB 外形のネジ穴を1箇所を除きNPTHへ変更。基板にネジ穴を追加。パーツ位置調整。
    [Jones.kicad_pcb]
2021-01-16 Update: 回路図 ネジ穴を用意
    [Jones.sch]
2021-01-16 Update: 強度不足が気になるので、中央付近にネジを1個追加。
    [Jones.kicad_pcb, Jones.sch]
2021-01-17 Update: ネジ穴位置調整。
    [Jones.kicad_pcb]
2021-01-17 Update: 配線最適化のため、MCUのピン割り当て変更。ボトムプレート用ネジ穴追加。
    [Jones.kicad_pcb, Jones.sch]
2021-01-17 New: v.0.4用ボトムプレートを追加。
    [Jones_plate_bottom-B_Cu.gbr, Jones_plate_bottom-B_Mask.gbr, Jones_plate_bottom-B_SilkS.gbr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]
2021-01-17 Update: 配線調整。シルク調整。
    [Jones.kicad_pcb]
2021-01-17 Updater: PCB 配線調整。ネジ穴を裏面配置に変更し、コートヤードにかからないようにした。
    [Jones.kicad_pcb]
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2021-01-18 Update: 配線調整。
    [Jones.kicad_pcb]
2021-01-19 Update: 基板の おもて と うら が間違っていたのを修正。
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2021-01-19 Update: 配線調整、シルク調整。
    [Jones.kicad_pcb, Jones.sch]
2021-01-31 Update: 簡易ボトムプレートとのねじ穴位置を調整。
    [Jones.kicad_pcb]
2021-03-10 VIAで5レイヤー使えるようにするため、総当たりマトリクスを10ピンから9ピンへ変更
    [Jones.sch]
2021-03-10 ロングスペース左Mod変更
    [Jones.kicad_pcb, Jones.sch]
2021-03-10 左シフトのバリエーションに、1u+1uを追加。
    [Jones.kicad_pcb]
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2021-03-13 Enter 1.25uとその右の関連を削除。右Shift 1.5+1.5を削除。
    [Jones.kicad_pcb, Jones.sch]
2021-03-13 穴の干渉を減らすため、ISOエンターのスタビの方向を逆に。
    [Jones.kicad_pcb, Jones.sch]
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2021-03-13 右上ネジ穴にかぶるソケットのプラ部分の干渉対策。
    [Jones.kicad_pcb, Jones.sch]
2021-03-13 右上ネジ穴にかぶるソケットのプラ部分の干渉対策。
    右隣のフットプリントとパッドの干渉があったため、さらに修正。
    [Jones.kicad_pcb, Jones.sch]
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2021-05-16 左シフト1u+1uの右側の配置ずれを修正
    [Jones.kicad_pcb]
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2021-06-27 上辺のネジ2個が、1uスイッチの中間から少し右へずれていたのを修正。
    [Jones.kicad_pcb]
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2021-07-11 英単語のスペース空け忘れを修正
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2021-07-11 細かい修正
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2021-07-29 リンク修正
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2021-07-29 表の乱れ修正
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2021-07-29 ファイル名修正
2021-07-29 リストに現在のものがふくまれていたのを修正
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2021-07-29 表記の揺れを修正
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2021-07-31 2音同時再生の掲載箇所間違いを修正
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2021-07-31 目次を追加。章立ての間違い修正。
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2021-07-31 文字化け修正
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2021-07-31 リンクミス修正
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2021-07-31 容量なのか物理的な大きさなのかわかりにくい表現を修正
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2021-07-31 色の間違い修正
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2021-08-01 表の崩れを修正
2021-08-01 L-CRLのシルク、1.5uと1.25uが逆なのを修正
    [Jones.kicad_pcb]
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2021-08-29 <details>の閉じ忘れを修正
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2021-08-29 キャプション誤記修正
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2021-08-30 スペースの文字種がおかしかったのを修正
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2021-09-01 v.1で104キー、108キーに対応したため、修正
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2021-09-03 スタート直後の文言を変更。そのた細かい修正・調整
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2021-09-04 画像リンク先を修正
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2021-09-17 章タイトルの重複表現を修正
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2021-09-18 不正な文字の混入を修正
2021-09-18 文章の表現変更、改行を修正
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2021-09-18 折り畳みの閉じタグをコメントアウトしたままだったのを修正
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2021-09-18 Typo修正
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2021-09-28 issue レイアウト：40sキット対応 #29
2021-09-29 Revert "Merge pull request #36 from jpskenn/dev_1.1_Add_40s_layout_#29"
    This reverts commit ac7df7e95556fcbf06f35e39de5424a1bd39dfc1, reversing
    changes made to 127994836709470240343b38cf9ba11c4b8eb1ff.
    [Jones.kicad_pcb, Jones.sch]
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2021-11-23 リンク切れ修正
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2022-03-05 目次のリンク切れ修正
2022-03-05 デザイン崩れの修正
